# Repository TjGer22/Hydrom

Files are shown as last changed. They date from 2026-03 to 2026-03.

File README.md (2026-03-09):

# Hydrom Firmware

This directory contains the ESP32 firmware for the Hydrom smart hydrometer, built with [PlatformIO](https://platformio.org/) on the Arduino framework.

## Target Hardware

**Heltec WiFi LoRa 32 V2** — ESP32 with integrated OLED and LoRa (only the ESP32 core is used; LoRa is not used in this project).

## Directory Structure

```
firmware/
├── src/              # main.cpp — application entry point
├── lib/              # Project-specific libraries
│   ├── ArduAutoUpdater/   # OTA firmware update
│   ├── BTManager/         # Bluetooth LE (BLE iBeacon)
│   ├── Calibrator/        # Gravity calibration logic
│   ├── DeviceManager/     # Device lifecycle management
│   ├── FileManager/       # SPIFFS configuration storage
│   ├── FindCurve/         # Polynomial curve fitting
│   ├── I2Cdevlib-Core/    # I2C abstraction (vendored)
│   ├── I2Cdevlib-MPU6050/ # MPU6050 IMU driver (vendored)
│   ├── NetworkManager/    # Wi-Fi (AP + client mode)
│   ├── SensorManager/     # IMU + DS18B20 sensor handling
│   ├── ServiceManager/    # Cloud service integrations
│   ├── Utils/             # Shared utilities
│   └── WebManager/        # Embedded Web UI
├── data/             # SPIFFS assets (logo, font, favicon)
├── Flasher/          # Helper scripts for manual flashing
├── platformio.ini    # Build configuration
└── partitions_custom8MB.csv  # Custom 8 MB partition table
```

## Installing the Firmware (no development tools required)

The installer scripts download the latest release from GitHub and flash it
to your Hydrom automatically. You only need an internet connection and a USB
cable that supports data transfer.

### Windows

Open **PowerShell** (search for it in the Start menu) and paste:

```powershell
powershell -ExecutionPolicy Bypass -Command "irm https://raw.githubusercontent.com/TjGer22/Hydrom/main/firmware/Flasher/install.ps1 | iex"
```

The script will:

1. Install Python 3 if it is not already present (via winget or direct download)
2. Install esptool via pip
3. Detect the COM port of your Hydrom automatically
4. Download the latest firmware files from the GitHub Releases page
5. Flash all five binary files in the correct order

> **Driver note** — if no COM port is detected, install the CP2102 driver first:
> https://www.silabs.com/developers/usb-to-uart-bridge-vcp-drivers

---

### macOS

Open **Terminal** and paste:

```bash
curl -fsSL https://raw.githubusercontent.com/TjGer22/Hydrom/main/firmware/Flasher/install.sh | bash
```

---

### Linux

```bash
curl -fsSL https://raw.githubusercontent.com/TjGer22/Hydrom/main/firmware/Flasher/install.sh | bash
```

> **Permission note** — if the flash fails with a permission error, add your user
> to the `dialout` group, then log out and back in:
> ```bash
> sudo usermod -aG dialout $USER
> ```

---

### Overriding port or baud rate

If the installer cannot find the device automatically, you can pass the port
and baud rate as environment variables before the command:

**macOS / Linux:**
```bash
HYDROM_PORT=/dev/ttyUSB0 HYDROM_BAUD=115200 \
  curl -fsSL https://raw.githubusercontent.com/TjGer22/Hydrom/main/firmware/Flasher/install.sh | bash
```

**Windows (PowerShell):**
```powershell
$env:HYDROM_PORT="COM3"; $env:HYDROM_BAUD="115200"
powershell -ExecutionPolicy Bypass -Command "irm https://raw.githubusercontent.com/TjGer22/Hydrom/main/firmware/Flasher/install.ps1 | iex"
```

---

### What happens during flashing

The installer writes five binary files to specific addresses in the ESP32 flash:

| File | Address | Purpose |
|---|---|---|
| `bootloader_dio_40m.bin` | `0x1000` | ESP32 first-stage bootloader |
| `partitions.bin` | `0x8000` | Partition table (8 MB layout) |
| `boot_app0.bin` | `0xe000` | OTA selection bootloader |
| `firmware.bin` | `0x10000` | Application firmware |
| `spiffs.bin` | `0x5B0000` | Filesystem (Web UI assets) |

When prompted, hold the **BOOT** button on the Hydrom and release it once
you see `Connecting...` in the output.

---

## Building from Source (PlatformIO)

```bash
# Build firmware + SPIFFS image
pio run --environment local --target buildfs
pio run --environment local

# Flash to connected device
pio run --environment local --target upload
pio run --environment local --target uploadfs

# Open serial monitor
pio device monitor
```

## Building

```bash
# Build firmware + SPIFFS image
pio run --environment local --target buildfs
pio run --environment local

# Flash to connected device
pio run --environment local --target upload
pio run --environment local --target uploadfs

# Open serial monitor
pio device monitor
```

## Credentials

Copy `lib/FileManager/Credentials.txt.example` to `lib/FileManager/Credentials.txt` and fill in your own values.
The `Credentials.txt` file is listed in `.gitignore` and will **never** be committed.

## License

GPL v3 — see [../LICENSE](../LICENSE)

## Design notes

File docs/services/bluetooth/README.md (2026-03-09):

---
description: >-
  The Hydrom supports iBeacon technology and enables Bluetooth Low Energy data
  transmission to smartphones and tablets in the surrounding area.
---

# Change Bluetooth Settings

!!! danger
    It is not possible to connect to the Hydrom via Bluetooth. \
    To receive the Bluetooth signals (iBeacon), please use the competitor's Tilt2app:\
    [https://tilthydrometer.com/pages/app](https://tilthydrometer.com/pages/app)

    If you have an iPhone, there is a BETA test currently running:

    [https://testflight.apple.com/join/UNli2kml](https://testflight.apple.com/join/UNli2kml)

!!! tip
    **Precondition:**

    To make this setting you must have access to the user interface. If this is not the case, see here how to do it:[access-to-the-user-interface.md](../access-to-the-user-interface.md)

## Step 1: Open the Menue

To access the menu bar you have to click on the three lines in the upper left corner. (See arrow)\
Then the menu bar will open.

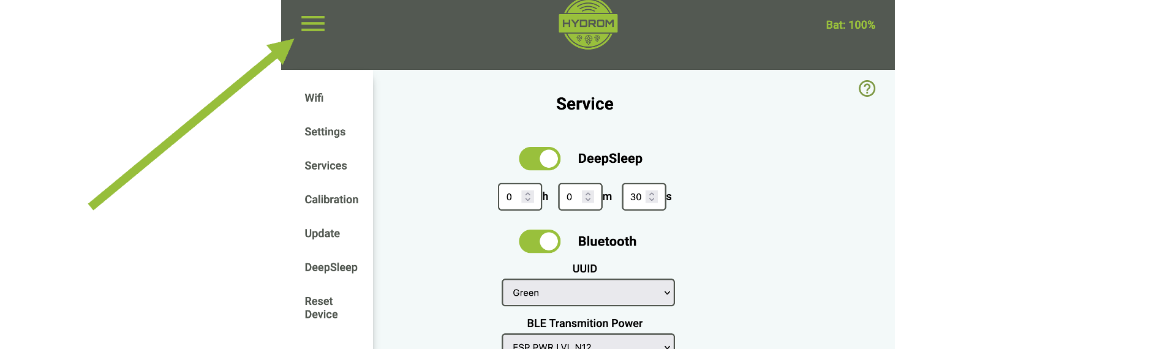
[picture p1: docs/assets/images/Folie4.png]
<figure><figcaption></figcaption></figure>

## Select "Service"

The "Services" page is a resource that allows users to select and configure various interfaces and cloud services for use with their system. On this page, users can choose from three different interfaces - HTTP, MQTT, and TCP - and several cloud services, and then activate and parameterize these options to suit their needs. This page is a useful tool for those who want to connect their system to the cloud or other external services and customize the way in which data is transmitted and received. With the options available on the "Services" page, users can tailor their system to meet their specific requirements and ensure that it is able to communicate effectively with other devices and systems.

## Step 3: Enable Bluetooth

The Hydrom will now send the following measured values via bluetooth after a restart by DeepSleep. For this, DeepSleep must also be activated as shown in the picture below.

!!! warning
    The "test message" option is not available for Bluetooth. So you have to wait until the Hydrom wakes up from a deep sleep. Hier findest du die Anleitu

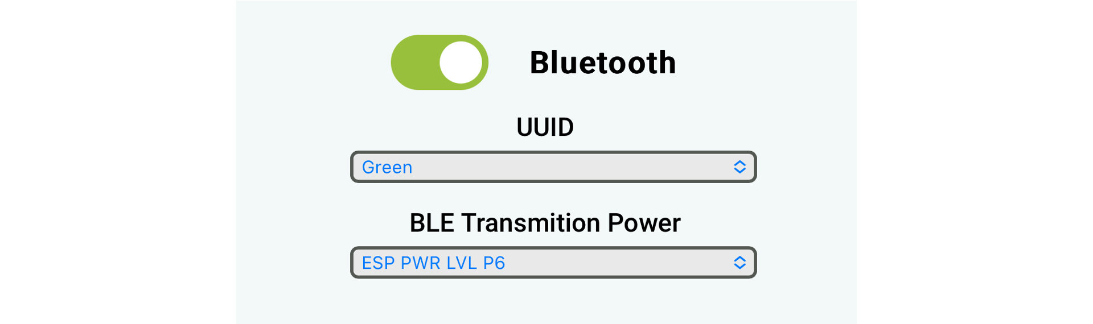
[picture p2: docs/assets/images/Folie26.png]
Enabled Bluetooth


!!! warning
    The "test message" option is not available for Bluetooth. So you have to wait until the Hydrom wakes up from a deep sleep.

## Choose UUID

Up to 8 Hydrom can be connected in parallel via Bluetooth. The different devices are then assigned different colors.

## Choose the transmission power

In the Hydrom, the power with which Bluetooth is transmitted can be set here. The range increases with higher transmission power. But beware, the battery life will also decrease with higher transmission power.

The powers with ascending transmission power:

*   ESP\_PWR\_LVL\_N14

    Corresponding to -14dbm
*   ESP\_PWR\_LVL\_N11

    Corresponding to -11dbm
*   ESP\_PWR\_LVL\_N8

    Corresponding to -8dbm
*   ESP\_PWR\_LVL\_N5

    Corresponding to -5dbm
*   ESP\_PWR\_LVL\_N2

    Corresponding to -2dbm
*   ESP\_PWR\_LVL\_P1

    Corresponding to 1dbm
*   ESP\_PWR\_LVL\_P4

    Corresponding to 4dbm
*   ESP\_PWR\_LVL\_P7

    Corresponding to 7dbm

### Save Settings

Saving the data is important because it is the only way to connect to the service after waking up from DeepSleep.

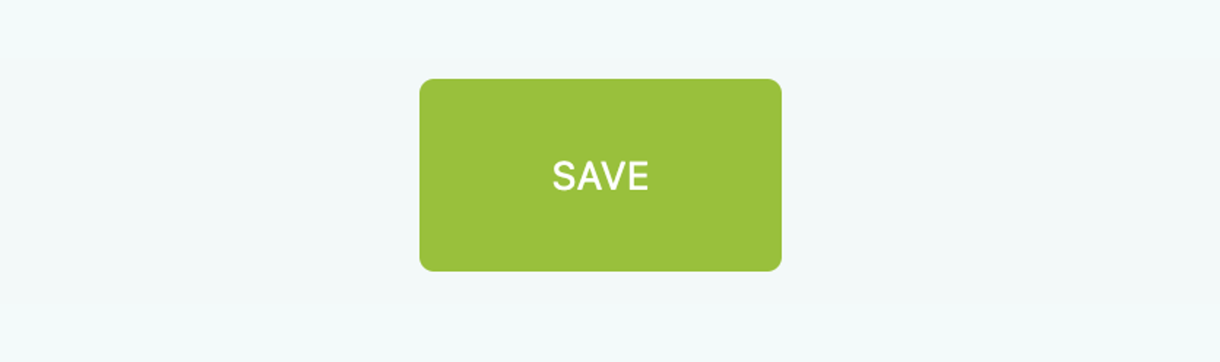
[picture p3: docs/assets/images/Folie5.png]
Pressing the "save" button saves the settings.


You can check whether the saving was successful by looking at the settings file at http://hydrom001/settings.json/. to check if the save was successful. This file is the permanent memory of the Hydrom.

A second way to check the saving is to reload the page (all browsers offer this). If the properties are then reloaded, the hydrom has accepted them, otherwise the old settings are reloaded.

### activate DeepSleep

Activating DeepSleep is mandatory for the hydrom to be able to send data. If DeepSleep is activated, the hydrom wakes up after the set time and sends the data to the set service. Afterwards, the hydrom goes back to sleep and waits for the new service.

[enable-deepsleep.md](../../configuration/enable-deepsleep.md)

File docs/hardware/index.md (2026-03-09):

---
description: >
  Overview of the Hydrom hardware design, KiCad source files and PCB specifications.
---

# Hardware Overview

The Hydrom PCB is designed with [KiCad](https://www.kicad.org/) (version 6+). All design files are open source under the **CERN Open Hardware Licence v2 – Strongly Reciprocal (CERN-OHL-S v2)**.

## Board Images

| Top side | Bottom side |
|---|---|
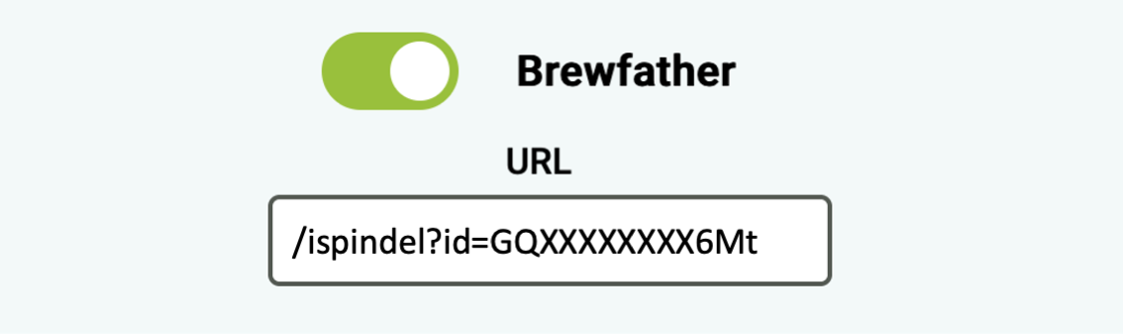
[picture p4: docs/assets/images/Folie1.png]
PCB Top
|  | PCB Bottom |

## Main Components

| Component | Function |
|---|---|
| ESP32 (Heltec WiFi LoRa 32 V2) | Main microcontroller — Wi-Fi, BLE, processing |
| MPU6050 | 6-axis IMU — measures tilt angle for density calculation |
| DS18B20 | 1-Wire temperature sensor |
| RT9080-33GJ5 | 3.3 V LDO voltage regulator |
| LiPo battery | Power supply |
| USB-C connector | Charging |

## Design Files

All KiCad source files are in [`hardware/pcb/`](https://github.com/TjGer22/Hydrom/tree/main/hardware/pcb). Open `hydrom_V1.0-2.kicad_pro` in KiCad to get started.

## Production Files

Ready-to-order files for PCB fabrication and assembly are in [`hardware/production/`](https://github.com/TjGer22/Hydrom/tree/main/hardware/production):

- **Gerbers** — standard Gerber 274-X format, tested with JLCPCB
- **BOM** — full bill of materials in XLSX format
- **Centroid** — pick-and-place files for top and bottom side

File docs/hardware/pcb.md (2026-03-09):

---
description: >
  PCB design details, fabrication notes and Gerber file locations for the Hydrom circuit board.
---

# PCB Design Files

The schematic and board layout are created with [KiCad](https://www.kicad.org/) 6+.

## Files

| File | Description |
|---|---|
| `hydrom_V1.0-2.kicad_pro` | KiCad project file — open this first |
| `hydrom_V1.0-2.kicad_sch` | Schematic |
| `hydrom_V1.0-2.kicad_pcb` | PCB layout |
| `hydrom_V1.0-2.xml` | Netlist |
| `PCB2.lib` | Custom schematic symbol library |
| `RT9080-33GJ5.lib` / `.dcm` | RT9080 LDO symbol and datasheet reference |
| `fp-lib-table` | Footprint library table |
| `sym-lib-table` | Symbol library table |

## Opening the Project

1. Install [KiCad](https://www.kicad.org/download/) 6 or later.
2. Clone the repository:
   ```bash
   git clone https://github.com/TjGer22/Hydrom.git
   ```
3. Open `hardware/pcb/hydrom_V1.0-2.kicad_pro` in KiCad.

## Board Renders

JLCPCB Top View
JLCPCB Bottom View

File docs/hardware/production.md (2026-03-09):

---
description: >
  Ready-to-order production files for PCB fabrication and SMD assembly of the Hydrom.
---

# Production Files

Ready-to-order production files are in [`hardware/production/`](https://github.com/TjGer22/Hydrom/tree/main/hardware/production).

## Gerbers

Standard Gerber 274-X files for PCB fabrication. Tested successfully with **JLCPCB**.

| File | Layer |
|---|---|
| `hydrom-F_Cu.gbr` | Front copper |
| `hydrom-B_Cu.gbr` | Back copper |
| `hydrom-F_Mask.gbr` | Front solder mask |
| `hydrom-B_Mask.gbr` | Back solder mask |
| `hydrom-F_Silkscreen.gbr` | Front silkscreen |
| `hydrom-B_Silkscreen.gbr` | Back silkscreen |
| `hydrom-F_Paste.gbr` | Front solder paste |
| `hydrom-B_Paste.gbr` | Back solder paste |
| `hydrom-Edge_Cuts.gbr` | Board outline |
| `hydrom-PTH.drl` | Plated through-holes |
| `hydrom-NPTH.drl` | Non-plated through-holes |

## Centroid (Pick-and-Place)

Pick-and-place files for SMT assembly:

- `hydrom-top-pos.xlsx` — top side component positions
- `hydrom-bottom-pos.xlsx` — bottom side component positions

## Ordering from JLCPCB

1. Download the `gerbers/` folder as a ZIP.
2. Upload to [jlcpcb.com](https://jlcpcb.com) → *Order Now*.
3. Enable *SMT Assembly* and upload the BOM and centroid files from `bom/` and `centroid/`.
4. Review the component placement preview and place your order.

!!! tip
    Select **HASL-Lead Free** or **ENIG** surface finish for best solderability.

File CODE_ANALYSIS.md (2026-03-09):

# Hydrom Firmware – Code Analysis & Cleanup Plan

> Generated: 2026-03-08
> Branch: `cleanup`
> Status: **In progress**

This document tracks every finding from the deep code review so work can be
resumed if the session is interrupted. Each item is marked ✅ when fixed.

---

## 1. Critical Typos in Identifiers

These affect compilation and must be changed everywhere consistently.

| # | File | Identifier | Issue | Fix | Status |
|---|---|---|---|-----|---|
| T1 | `lib/SensorManager/TemperaturCompensation.h/.cpp` | `TemperaturCompensation` | Missing 'e' → affects 17+ files | Rename class + files to `TemperatureCompensation` | ✅ |
| T2 | `lib/FileManager/HydromConfiguration.h:148` | `Enable_Temperaturcompensation` | Typo in member name | `Enable_TemperatureCompensation` | ✅ |
| T3 | `lib/FileManager/HydromConfiguration.h` | `Temperaturcompensation_Factor` | Typo in member | `TemperatureCompensation_Factor` | ✅ |
| T4 | `lib/SensorManager/SensorManager.h:47` | `readBatteryVolatage` | "Volatage" → "Voltage" | `readBatteryVoltage` | ✅ |
| T5 | `src/main.cpp:95` | comment `"3 seconds0"` | Stray zero | `"3 seconds"` | ✅ |

### Files affected by T1 (`TemperaturCompensation`):
- `lib/SensorManager/TemperaturCompensation.h` → rename file
- `lib/SensorManager/TemperaturCompensation.cpp` → rename file
- `lib/SensorManager/SensorManager.h` (include + member type)
- `lib/SensorManager/SensorManager.cpp` (usage)
- `lib/FileManager/HydromConfiguration.h` (member)
- `lib/FileManager/HydromConfiguration.cpp` (usage)
- `lib/WebManager/WebManager.cpp` (usage)
- `src/main.cpp` (include + usage)

---

## 2. Magic Numbers → Named Constants

All to be placed in `lib/FileManager/Globals.h`.

| # | File | Line | Value | Name | Status |
|---|---|---|---|---|---|
| M1 | `src/main.cpp` | 96 | `7` (button press seconds) | `BUTTON_PRESS_RESET_WIFI_SECONDS` | ✅ |
| M2 | `src/main.cpp` | 101 | `15` (factory reset seconds) | `BUTTON_PRESS_FACTORY_RESET_SECONDS` | ✅ |
| M3 | `src/main.cpp` | 170 | `3.0` (battery critical V) | `BATTERY_CRITICAL_VOLTAGE` | ✅ |
| M4 | `src/main.cpp` | 170 | `1.0` (battery min V) | `BATTERY_MIN_VOLTAGE` | ✅ |
| M5 | `src/main.cpp` | 173 | `10.0` (min startup temp °C) | `MIN_STARTUP_TEMPERATURE` | ✅ |
| M6 | `src/main.cpp` | 175 | `30.0` (max startup temp °C) | `MAX_STARTUP_TEMPERATURE` | ✅ |
| M7 | `lib/Calibration_MPU.cpp` | 36 | `3150` (µs delay) | `MPU_CALIBRATION_US_DELAY` | ✅ |
| M8 | `lib/Calibration_MPU.cpp` | 37 | `1000` (fast samples) | `MPU_CALIBRATION_FAST_SAMPLES` | ✅ |
| M9 | `lib/Calibration_MPU.cpp` | 38 | `10000` (slow samples) | `MPU_CALIBRATION_SLOW_SAMPLES` | ✅ |
| M10 | `lib/BTManager/BLESender.cpp` | 76 | `0x4C00` | `APPLE_IBEACON_MANUFACTURER_ID` | ✅ |

---

## 3. Duplicate Logic → Helper Functions

| # | Location | Pattern | Refactoring | Status |
|---|---|---|---|---|
| D1 | `main.cpp:209,281,334,446` | `DeepSleep.hours*3600 + DeepSleep.minutes*60 + DeepSleep.seconds` | Extract `calculateDeepSleepSeconds()` to Util | ✅ |
| D2 | `SensorManager.cpp:49-58` | Element-by-element array copy | Replace with `memcpy()` | ✅ |

---

## 4. const Correctness

| # | File | Function | Fix | Status |
|---|---|---|-----|---|
| C1 | `SensorManager.h` | `get_batteryVoltage()` and all getters | Add `const` | ✅ |
| C2 | `FindCurve.h:29` | `get_Curve_Quality()` | Add `const` | ✅ |
| C3 | `ServiceManager.h:33` | `Replace_Placeholder(char _url[265])` | `const String&` param | ✅ |
| C4 | `Calibration_MPU.h:22-26` | `LBRACKET`, `RBRACKET` etc. | `static constexpr` | ✅ |

---

## 5. Safety – StringCopy Buffer Overflow

| # | File | Lines | Issue | Fix | Status |
|---|---|---|---|-----|---|
| S1 | `Util.cpp:13-21` | `StringCopy` + `StringCopyConst` | `strlen(des)` on uninit buffer; no bounds check | Add null-guard + use `strlcpy()` | ✅ |
| S2 | `Util.cpp:27` | `IpToString()` static buffer | Not thread-safe | Add comment, keep for now (embedded single-task path) | ✅ |

---

## 6. Include Guards → `#pragma once`

All custom headers converted to `#pragma once` (PlatformIO/GCC supports it).

Files: `TemperaturCompensation.h`, `SensorManager.h`, `FindCurve.h`,
`Calibrator.h`, `BLESender.h`, `NetworkManager.h`, `DeviceManager.h`,
`WebManager.h`, `ServiceManager.h`, `HydromConfiguration.h`.

Status: ✅

---

## 7. Uninitialized Variables

| # | File | Line | Variable | Fix | Status |
|---|---|---|---|-----|---|
| U1 | `main.cpp:34` | `long last_Release;` | Initialize to `0` | ✅ |
| U2 | `SensorManager.h:88-100` | `float g_*` members | Default-initialize to `0.0f` | ✅ |

---

## 8. Dead Code Removed

| # | File | Lines | Description | Status |
|---|---|---|---|---|
| DC1 | `main.cpp:554-605` | ~50-line commented-out block | Remove | ✅ |
| DC2 | `WebManager.cpp:30` | `// boolean liveData = false;` | Remove comment | ✅ |

---

## 9. Out of Scope / Risk Too High (deferred)

These require deeper refactoring or embedded system expertise:

- **Race conditions** on global structs (FreeRTOS multi-core): Requires adding `SemaphoreHandle_t`; risks affecting timing.
- **setup() split**: 280-line function; refactoring into sub-functions is safe but very large change.
- **Hardcoded OTA password** in `NetworkManager.cpp:40`: Already in `Secrets.h`-like pattern; moving to runtime config requires flash storage changes.
- **TLS `setInsecure()`** in `ArduAutoUpdater`: Requires embedding CA cert bundle; separate task.
- **`Salzen()` rename**: Cryptographic/obfuscation function – renaming without understanding all callers is risky.
- **Service registry pattern** for `publish_Data_to_Services()`: Large architectural change.

---

## File Rename Map (T1)

| Old | New |
|-----|-----|
| `lib/SensorManager/TemperaturCompensation.h` | `lib/SensorManager/TemperatureCompensation.h` |
| `lib/SensorManager/TemperaturCompensation.cpp` | `lib/SensorManager/TemperatureCompensation.cpp` |

---

*Resume point: All items with ✅ are complete. Continue with any remaining items.*

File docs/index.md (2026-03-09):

---
description: >
  Introduction to the Hydrom open-source smart hydrometer — features, hardware, and licence overview.
---

# Hydrom — Open-Source Smart Hydrometer

**Hydrom** is a free-floating smart hydrometer that measures the density of your beer, wine, or cider in real time — no more opening the fermenter to take manual readings.

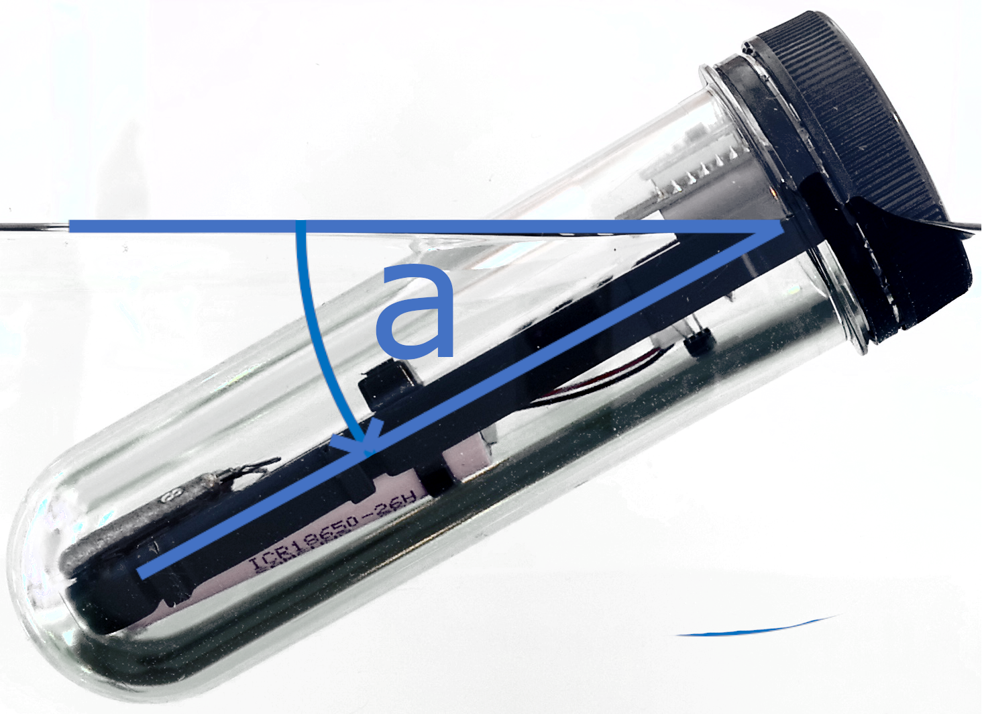
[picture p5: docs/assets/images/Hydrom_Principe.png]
Hydrom smart hydrometer floating in fermenter


---

<div class="feature-grid" markdown>

<div class="feature-card" markdown>
<h3>📡 Wi-Fi</h3>
<p>Connects to your home network and transmits measurements every few minutes — fully automatic.</p>
</div>

<div class="feature-card" markdown>
<h3>🔵 Bluetooth LE</h3>
<p>Broadcasts as an iBeacon — pick up readings on your smartphone without an internet connection.</p>
</div>

<div class="feature-card" markdown>
<h3>☁️ Cloud Services</h3>
<p>Direct integration with Brewfather, Brewer's Friend, Brewblox, Grainfather, MQTT, Google Sheets, and more.</p>
</div>

<div class="feature-card" markdown>
<h3>🔋 Deep Sleep</h3>
<p>Ultra-low power consumption. One charge lasts through an entire fermentation.</p>
</div>

<div class="feature-card" markdown>
<h3>🔧 OTA Updates</h3>
<p>Update firmware directly from the built-in web interface — no USB cable needed.</p>
</div>

<div class="feature-card" markdown>
<h3>📖 Open Source</h3>
<p>Firmware, hardware, and documentation are fully open. Build your own or contribute.</p>
</div>

</div>

---

## Quick Start

New to Hydrom? These are the steps to get from unboxing to active monitoring:

| Step | Action |
|---|---|
| 1 | [Read Safety Warnings](getting-started/warnings-read-before-use.md) |
| 2 | [Disinfect the Hydrom](getting-started/disinfect-before-use.md) |
| 3 | [Charge via USB-C](services/charging-the-hydrom.md) |
| 4 | [Switch on](services/turn-on-the-hydrom.md) and [enter Configuration Mode](services/wakeup-the-hydrom.md) |
| 5 | [Connect to your Wi-Fi](services/wifi-setup.md) |
| 6 | [Open the Web UI](services/access-to-the-user-interface.md) |
| 7 | [Calibrate](calibration/check-calibration.md) for accurate readings |
| 8 | [Connect a service](services/connect_to_brewfather.md) — e.g. Brewfather |

→ [Full Getting Started guide](getting-started/README.md)

---

## How It Works

The Hydrom floats in your liquid at an angle determined by the liquid's density. An onboard IMU (MPU-6050) measures this angle continuously, a DS18B20 temperature sensor compensates for temperature effects, and the firmware converts the result to specific gravity or °Plato. Data is transmitted via Wi-Fi every few minutes — or broadcast continuously as a Bluetooth Low Energy beacon.

---

## Licenses

| Component | License |
|---|---|
| Firmware / Software | [GPL v3](https://github.com/TjGer22/Hydrom/blob/main/LICENSE) |
| PCB / Hardware | [CERN-OHL-S v2](https://github.com/TjGer22/Hydrom/blob/main/hardware/LICENSE-HARDWARE) |
| Documentation | [CC BY 4.0](https://github.com/TjGer22/Hydrom/blob/main/docs/LICENSE-DOCS) |

Contributions are welcome — see the [Contributing Guide](contributing.md).

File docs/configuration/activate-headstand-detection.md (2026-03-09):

---
description: >
  How to enable headstand detection so the Hydrom pauses measurements when inverted.
---

# Activate Headstand Detection

## What is Headstand Detection?

During fermentation, your Hydrom needs to float normally in your fermenter. However, sometimes the Hydrom may accidentally end up upside down—for example, during cleaning, when removing it from the fermenter, or if something bumps it.

**Headstand detection** automatically recognizes when the Hydrom is inverted and stops transmitting false readings. This protects your fermentation data by preventing inaccurate measurements and saves battery power by not sending bad data.

!!! info
    Detection threshold is approximately 90 degrees. When inverted, the Hydrom will suspend measurement and transmission. It automatically resumes normal operation on the next wake cycle when placed right-side up.

## How to Enable Headstand Detection

### Step 1: Open the Menu

Open the Hydrom web interface in your browser. Look for the **menu icon** (three horizontal lines) in the top-left corner of the screen.

### Step 2: Navigate to Settings

Tap or click on **Settings** from the menu options.

### Step 3: Enable Headstand Detection

In the Settings page, locate the **Headstand Detection** toggle switch. Tap or click to enable it.

### Step 4: Save Your Settings

Click the **Save** button to apply the setting. You'll see a confirmation message.

## How It Works

When **Headstand Detection** is enabled:

- **Monitors orientation** of the Hydrom continuously
- **Detects inversion** when tilted beyond approximately 90 degrees
- **Stops transmissions** if upside down to prevent false readings
- **Prevents battery drain** from transmitting bad data
- **Auto-recovers** when the Hydrom returns to normal floating position

## Benefits

- **Protects data integrity** during handling and cleaning
- **Saves battery** by not transmitting erroneous measurements
- **Automatic recovery** — no manual intervention needed
- **Works silently** in the background

## When to Use This Feature

Enable Headstand Detection if:

- Your Hydrom occasionally gets bumped or moved around
- You clean your fermenter while the Hydrom is present
- You want the maximum battery life
- You're concerned about accidental inversions affecting your data

## Tips

- **Always leave enabled** for normal operation
- **No impact on accuracy** when the Hydrom is floating normally
- **Complements temperature compensation** for the best measurement experience
- **Check orientation occasionally** to ensure normal floating position

---

**Related guides:**
- [Temperature Compensation →](setting-up-the-temperature-compensation.md)
- [Return to Settings →](changing-the-hydrom-name.md)

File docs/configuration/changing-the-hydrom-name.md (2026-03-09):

---
description: >
  How to change the device name of your Hydrom in the web interface.
---

# Changing the Hydrom name

!!! danger
    ATTENTION! If you have entered incorrect Name for the Hydrom, you will not be able to connect to the Hydrom via existing Network. You will then need to use the Configuration-Wifi.

    If the setting is incorrect, you can reset the Hydrom as described here:

    [#reset-by-the-button](factory-reset.md#reset-by-the-button)

!!! info
    Changing the Hydrom name has the following effect:

    1. The user interface is not accessed via [http://hydrom001/](http://hydrom001) as described in the chapter [Access to the User Interface](../services/access-to-the-user-interface.md#connect-to-the-hydrom-via-the-hydroms-configuration-wifi), but now via http://\<own\_choosen\_name>/.
    2.  Some of the services described in the chapter "Connect Services" now send to a different address.

        However, this is mentioned separately in the respective instruction article.

!!! tip
    To make this setting you must have access to the user interface. If this is not the case, see here how to do it:

    [access-to-the-user-interface.md](../services/access-to-the-user-interface.md)

## Step 1: Open the Menue

To access the menu bar you have to click on the three lines in the upper left corner. (See arrow)\
Then the menu bar will open.

access the menu bar by clicking the three lines in the upper left corner

## Step 2: Select "Settings"

On this page, you can adjust various settings to personalize your experience with the device. Options you can customize include the interval at which the device collects and sends data, the units displayed on the main page, and the overhead detection feature. You can also enable temperature compensation to ensure accurate measurements. Take some time to explore the various settings available and make the necessary adjustments for your needs.

## Step 3: Change device name

To change the device name, enter the new name under the "Devicename" lettering.\
By default, the device name is "Hydrom001".

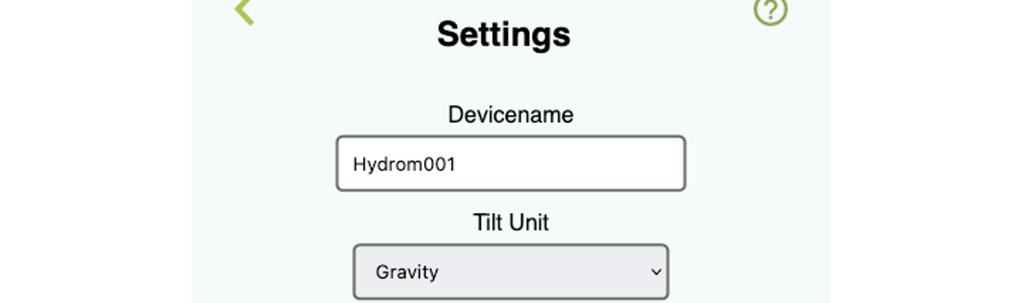
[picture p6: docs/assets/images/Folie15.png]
Changing the device name of the hydrometer


### Save Settings

Saving the data is important because it is the only way to connect to the service after waking up from DeepSleep.

Pressing the "save" button saves the settings.

You can check whether the saving was successful by looking at the settings file at http://hydrom001/settings.json/. to check if the save was successful. This file is the permanent memory of the Hydrom.

A second way to check the saving is to reload the page (all browsers offer this). If the properties are then reloaded, the hydrom has accepted them, otherwise the old settings are reloaded.

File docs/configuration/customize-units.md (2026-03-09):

---
description: >-
  The Hydrom supports several units for the tilt and the temperature. Here is
  explained how to change the unit.
---

# Customize units

!!! tip
    **Precondiion:**\
    To make this setting you must have access to the user interface. If this is not the case, see here how to do it:[access-to-the-user-interface.md](../services/access-to-the-user-interface.md)

## Step 1: Open the Menue

To access the menu bar you have to click on the three lines in the upper left corner. (See arrow)\
Then the menu bar will open.

access the menu bar by clicking the three lines in the upper left corner

## Step 2: Select "Settings"

On this page, you can adjust various settings to personalize your experience with the device. Options you can customize include the interval at which the device collects and sends data, the units displayed on the main page, and the overhead detection feature. You can also enable temperature compensation to ensure accurate measurements. Take some time to explore the various settings available and make the necessary adjustments for your needs.

## Step 3: Change Units

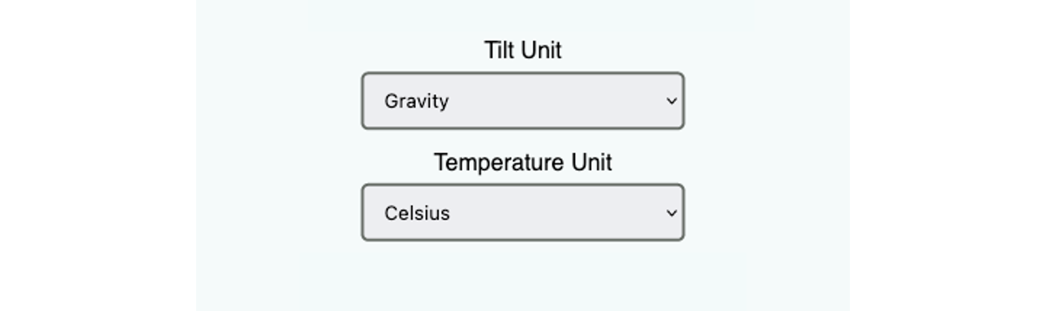
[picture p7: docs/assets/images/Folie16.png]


### Tilt

* **Plato** The unit Plato (°P) is a unit of measure used to quantify the concentration of sugars in a solution. It is commonly used in the brewing industry to describe the concentration of wort, which is the liquid that is extracted from the mashing process during the production of beer. One degree Plato is equal to one gram of sucrose per 100 grams of solution. The Plato scale is widely used because it is more accurate than other methods of measuring the concentration of sugars, such as the Brix scale.
* **Specific Gravity** Specific gravity is a unit of measure used to compare the density of a substance to the density of a reference substance, typically water. It is commonly used in the brewing industry to measure the concentration of sugars in a solution, such as wort or beer. Specific gravity is expressed as a ratio, with the density of the substance being measured being the numerator and the density of the reference substance being the denominator. For example, if the specific gravity of a substance is 1.050, it means that it is 1.050 times denser than water, which has a specific gravity of 1.000. Specific gravity is an important measure for brewers because it allows them to determine the concentration of sugars and other dissolved solids in their wort or beer, which can affect the final alcohol content and flavor of the finished product.
* **Degree** The raw angle of the Hydrom to the horizontal is indicated in degrees. If the hydrometer is horizontal, "0°" is displayed. If the hydrometer is in the vertical plane, "90°" is displayed.

### Temperature

* **Celsius** The unit Celsius (°C) is the international standard temperature scale used for measuring temperatures, with zero set at 0 °C and the boiling point of water set at 100 °C.
* **Fahrenheit** Fahrenheit (°F) is a temperature scale used in the United States and some other countries, with the freezing point of water set at 32 °F and the boiling point at 212 °F.
* **Kelvin**. The unit Kelvin (K) is a temperature scale used in science and industrial applications and on which the absolute temperature scale is based. On the Kelvin scale, absolute zero is set at 0 K, which corresponds to the theoretical state of complete immobility of atoms and molecules. The Kelvin scale is often used in physics and chemistry because it is independent of the type of heat transfer and has no negative values.

!!! info
    The set units do not affect the services.

    This means that the data sent will always be consistent, no matter what unit is set.

### Save Settings

Saving the data is important because it is the only way to connect to the service after waking up from DeepSleep.

Pressing the "save" button saves the settings.

You can check whether the saving was successful by looking at the settings file at http://hydrom001/settings.json/. to check if the save was successful. This file is the permanent memory of the Hydrom.

A second way to check the saving is to reload the page (all browsers offer this). If the properties are then reloaded, the hydrom has accepted them, otherwise the old settings are reloaded.

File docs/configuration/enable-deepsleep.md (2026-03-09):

---
description: >-
  If you put your ESP32 in deep sleep mode, it will reduce the power consumption
  and your batteries will last longer.
---

# Adjust Interval

!!! tip
    **Precondition:**\
    To make this setting you must have access to the user interface. If this is not the case, see here how to do it:

    [access-to-the-user-interface.md](../services/access-to-the-user-interface.md)

## Step 1: Open the Menue

To access the menu bar you have to click on the three lines in the upper left corner. (See arrow)\
Then the menu bar will open.

access the menu bar by clicking the three lines in the upper left corner

## Step 2: Select "Settings"

On this page, you can adjust various settings to personalize your experience with the device. Options you can customize include the interval at which the device collects and sends data, the units displayed on the main page, and the overhead detection feature. You can also enable temperature compensation to ensure accurate measurements. Take some time to explore the various settings available and make the necessary adjustments for your needs. or "Services"

## Step 3: Adjust Interval

Select the time the hydrom should sleep.



If you want to put the Hydrom to sleep immediately, you can select "DeepSleep" in the navigation bar.
Even if you switch the Hydrom off and on again via the switch, the Hydrom will be put into deep sleep after the first transmission of the measured values.

!!! info
    **Sleep time calculation**

    Currently the Hydrom needs 23sec. to start, set up the network, send out the readings.

    This means that for a constant transmission of data every 15min, you need to set a sleep time of 14min. 27sec.

### Save Settings

Saving the data is important because it is the only way to connect to the service after waking up from DeepSleep.

Pressing the "save" button saves the settings.

You can check whether the saving was successful by looking at the settings file at http://hydrom001/settings.json/. to check if the save was successful. This file is the permanent memory of the Hydrom.

A second way to check the saving is to reload the page (all browsers offer this). If the properties are then reloaded, the hydrom has accepted them, otherwise the old settings are reloaded.

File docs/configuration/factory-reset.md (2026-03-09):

---
description: >-
  The Hydrom can be reset with the reset button
---

# Factory Reset

## Reset by the button

The Hydrom can be reset by pressing the reset button for 10 seconds.&#x20;

To access this button, the lid must be unscrewed.

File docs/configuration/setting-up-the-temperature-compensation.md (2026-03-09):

---
description: >
  How to configure the temperature compensation factor to correct angle readings at different temperatures.
---

# Setting Up Temperature Compensation

## What is Temperature Compensation?

The Hydrom hydrometer is calibrated at 20°C (68°F) during manufacturing. However, during fermentation, your beer or wine may be at a different temperature—warmer or cooler. Since the density of liquids changes with temperature, this difference can introduce small measurement errors.

**Temperature compensation automatically corrects these errors** by using the Hydrom's built-in temperature sensor to adjust readings based on the actual liquid temperature. This ensures you get accurate gravity measurements regardless of fermentation conditions.

!!! note
    The sensor must be fully submerged for accurate temperature readings. Make sure the Hydrom floats freely in your fermenter.

## How to Enable Temperature Compensation

### Step 1: Open the Menu

Open the Hydrom web interface in your browser. Look for the **menu icon** (three horizontal lines) in the top-left corner of the screen.

Open the menu

### Step 2: Navigate to Settings

Tap or click on **Settings** from the menu options that appear.

### Step 3: Enable Temperature Compensation

In the Settings page, locate the **Temperature Compensation** toggle switch. Tap or click to enable it.

Save your settings

### Step 4: Save Your Changes

Click the **Save** button to apply the temperature compensation setting. You'll see a confirmation message indicating the setting has been saved.

## What to Expect

Once enabled, the Hydrom will:

- **Monitor liquid temperature** continuously using its built-in sensor
- **Automatically adjust** gravity readings to reflect 20°C equivalent values
- **Display both** the actual reading and temperature in the web interface
- **Improve accuracy** especially during temperature fluctuations

## Tips

- **Enable this feature** for the most accurate fermentation tracking
- **Works best** when the Hydrom is floating freely in the fermenter
- **No additional calibration** is needed after enabling temperature compensation
- **Check occasionally** that the Hydrom remains fully submerged as fermentation progresses

Temperature compensation takes the guesswork out of accounting for temperature variations and helps you make better decisions about your fermentation.

---

**Next steps:**
- [Activate Headstand Detection →](activate-headstand-detection.md)
- [Return to Settings →](changing-the-hydrom-name.md)

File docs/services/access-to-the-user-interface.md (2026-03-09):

---
description: >
  How to access the Hydrom configuration web interface from a phone or computer.
---

# Access to the user interface

!!! tip
    **Precondition:**

    1. The Hydrom must be powered on\
       How to switch on the Hydrom can be found here:\
       [turn-on-the-hydrom.md](turn-on-the-hydrom.md)
    2.  The Hydrom must be in configuration mode\
        In normal operation, no user interface is loaded in order not to waste the battery charge. Therefore, the Hydrom must be put into configuration mode.

        You can detect if the Hydrom is in Deepsleep when the green LED is on as described here: [Status LED](../getting-started/indicator-leds.md#status-led-of-the-hydrom-logic)

        If the Hydrom is in Deepsleep, it can be woken up according to the instructions on this page:\
        [wakeup-the-hydrom.md](wakeup-the-hydrom.md)

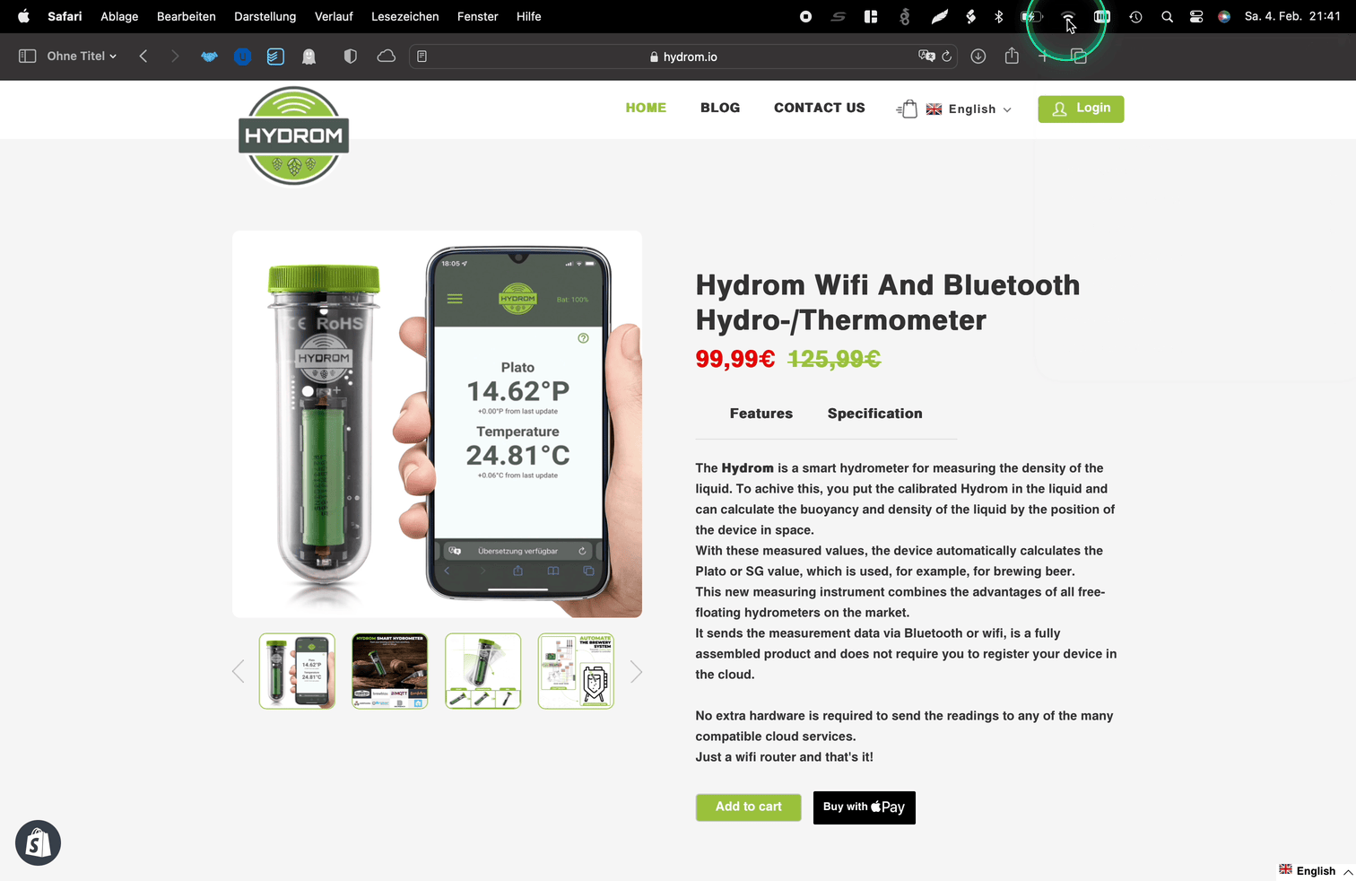
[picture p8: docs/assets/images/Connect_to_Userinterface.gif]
<figure><figcaption></figcaption></figure>

## Connect to the Hydrom via the Hydrom's configuration wifi.

### Step 1: Connect to the Hydrom's WLAN

1. turn on your smartphone, tablet or computer.
2. in your device's wifi settings, search for a wifi named "hydrom\_XXXXX". Select this Wi-Fi and connect to it.

### Step 2: Open the Hydrom user interface in the browser

1. open the internet browser on your device (e.g. Google Chrome, Mozilla Firefox or Safari). Enter the following address in the address bar of the browser: [http://192.168.2.1](http://192.168.2.1) and press Enter.

## Connect to the Hydrom via the existing WLAN (only if the Hydrom is already connected to the WLAN).

!!! info
    If the hydrom is already connected to your WLAN, it now has a different address. The old address "[http://192.168.2.1](http://192.168.2.1)" does not work anymore.

    If you don't know the new address, connect to the Hydrom WLAN as described in **step 1**.\
    Then go to the network settings in the Hydrom user interface. If the connection is successful, you will see the new address in a green box at the top of the page.

1. open your internet browser again. 2.
2. type the new address (e.g. "http://\<new IP>") in the address bar and press enter.

Now you should be able to see and use the Hydrom user interface.

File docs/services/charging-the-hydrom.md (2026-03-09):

---
description: >
  How to charge the Hydrom battery and check the charging status via the indicator LEDs.
---

# Charging the Hydrom

The Hydrom can be charged with any commercially available USB-C charging cable.

Even the direction in which you insert the plug into the device does not matter. To charge, open the Hydrom by twisting off the lid.

The charging LED (described here: [Charging LED](../getting-started/indicator-leds.md#charging-led)) indicates the current charging status. If the LED is red, the Hydrom is being charged. When the LED is green, the charging process is complete.\\

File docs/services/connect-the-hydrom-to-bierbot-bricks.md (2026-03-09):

---
description: >-
  BierBot Bricks software is designed to support all steps of the brewing
  process from mashing, to fermentation, to lagering.
cover: ../assets/images/Folie74.png
coverY: 0
---

# Connect the Hydrom to BierBot Bricks

!!! tip
    **Prerequisite:**

    1. **Access to user interface**\
       To make this setting, you must have access to the user interface. If this is not the case, see here how to do it:[access-to-the-user-interface.md](access-to-the-user-interface.md)
    2. **BierBot Bricks account available**.\
       To use BierBot Bricks, you need an account. You can register here: [https://bierbot.com](https://bierbot.com)

## Prepare the service

### Create brick in the BierBot brewery

To do this navigate to the BierBot Bricks website and log in. Then click on the "Brewery" tab. Then click on the "Add Brick" button.

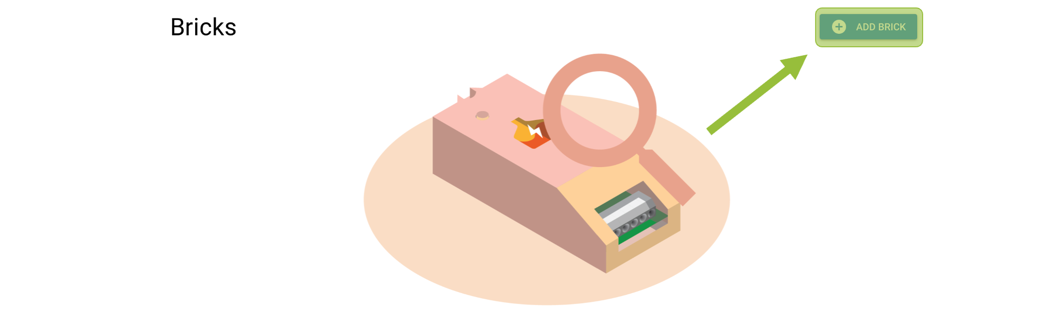
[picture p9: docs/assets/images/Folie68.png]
Add Brick


Choose HYDROM as type of brick you want to add. Then click on the "Add Brick" button.

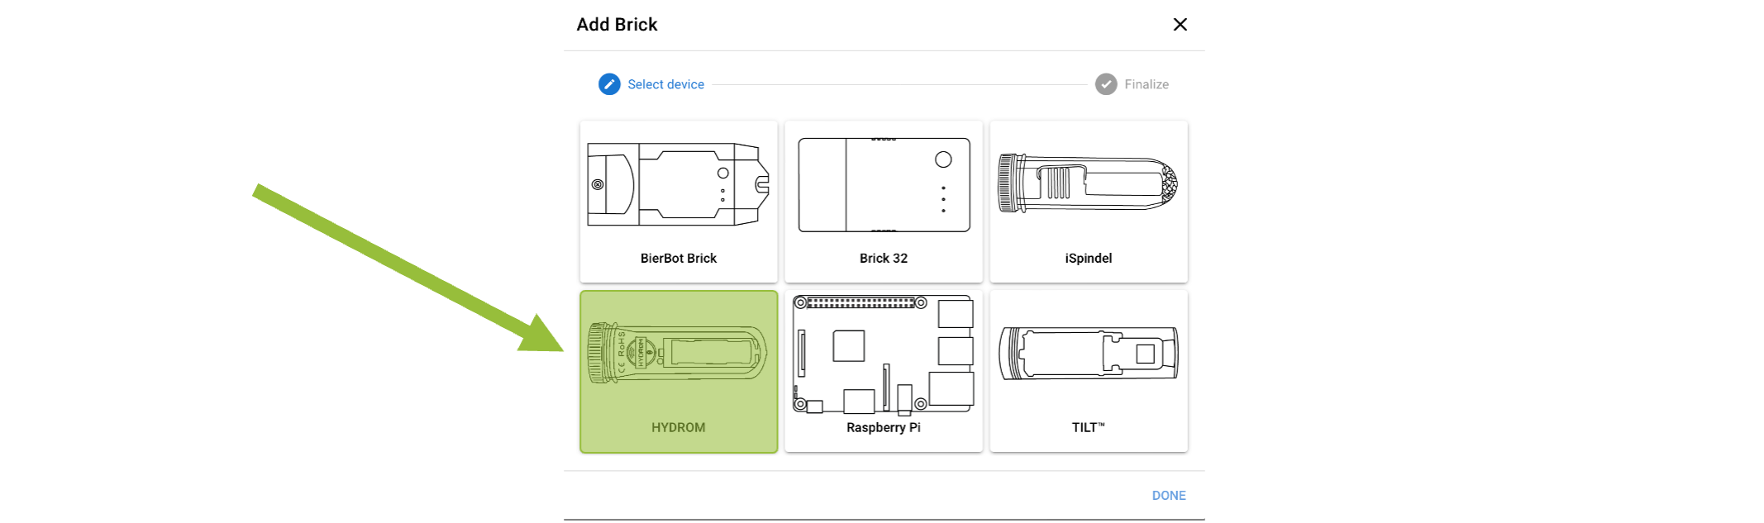
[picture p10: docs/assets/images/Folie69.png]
Add HYDROM Brick


### Copy the API token

After the brick has been added, you will be redirected to the brick settings. Here you can find the API token. Copy the API token and save it for later use.

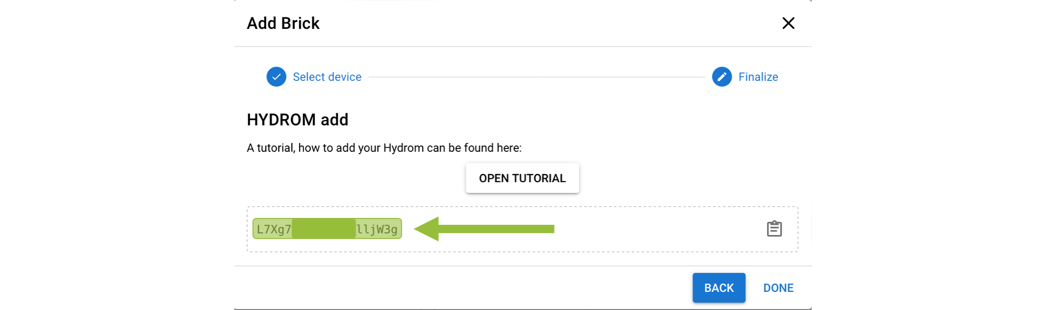
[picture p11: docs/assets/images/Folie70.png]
<figure><figcaption></figcaption></figure>

When the Hydrom sends measured values to the BierBot Bricks service for the first time, the new device is displayed in the brewery under "Bricks" with all measured values.\
The fastest way to get the device displayed is to set the interval in the Hydrom to 1 second.\
Then BierBot Bricks will automatically set the time to 15min.

### Activate the Device

If the device is displayed under the Bricks, it still needs to be activated.

### Set custom logging interval

The default logging interval is 15 minutes. If you want to change this interval, you can do so here. To do this, click on the "Settings" tab and then on the "Logging" tab.

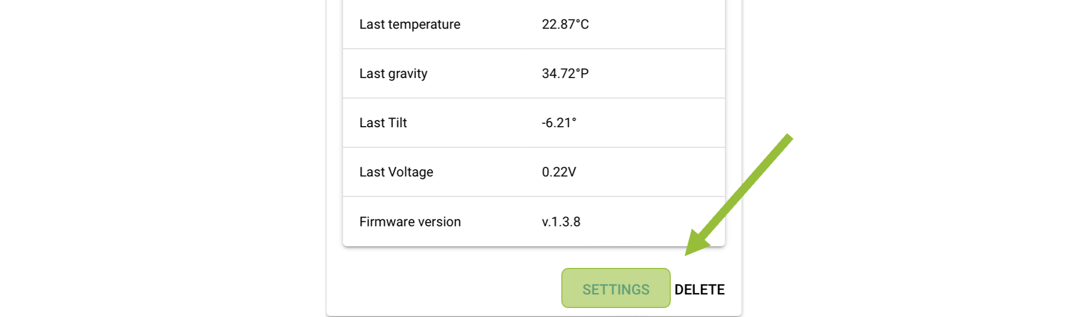
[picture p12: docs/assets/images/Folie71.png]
<figure><figcaption></figcaption></figure>

Activate "Set Custom Interval" (1). Then change the logging interval to the desired value (2) and click on the "Save" button (3).

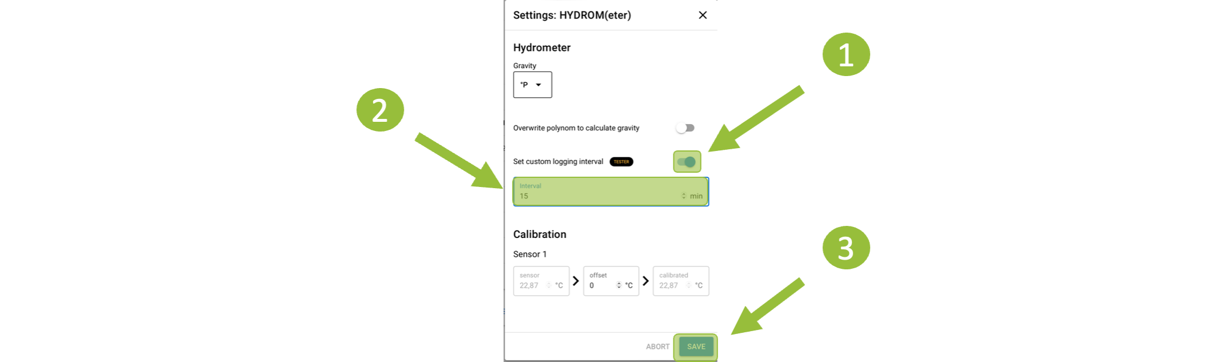
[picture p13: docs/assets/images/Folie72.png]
<figure><figcaption><p>Set custom logging interval</p></figcaption></figure>

## Insert BierBot Bricks settings in Hydrom

Now open the user interface of the Hydrom, in the best case the Hydrom is already in the network and can be easily accessed via Webpage.\
If there are questions about how to get to the user interface, the following page is recommended: [access-to-the-user-interface.md](access-to-the-user-interface.md)

Otherwise the Hydrom must still be started.

### Step 1: Open the Menue

To access the menu bar you have to click on the three lines in the upper left corner. (See arrow)\
Then the menu bar will open.

access the menu bar by clicking the three lines in the upper left corner

### Step 2: Select "Service"

The "Services" page is a resource that allows users to select and configure various interfaces and cloud services for use with their system. On this page, users can choose from three different interfaces - HTTP, MQTT, and TCP - and several cloud services, and then activate and parameterize these options to suit their needs. This page is a useful tool for those who want to connect their system to the cloud or other external services and customize the way in which data is transmitted and received. With the options available on the "Services" page, users can tailor their system to meet their specific requirements and ensure that it is able to communicate effectively with other devices and systems.

### Step 3: Activate BierBot Bricks and change the settings.

On the "Service" page, you need to activate the BierBot Bricks service. Copy the API token from the BierBot Bricks website and paste it into the "Token" field.

!!! info
    The token must be entered without any spaces. If there are spaces, the token will not be accepted.

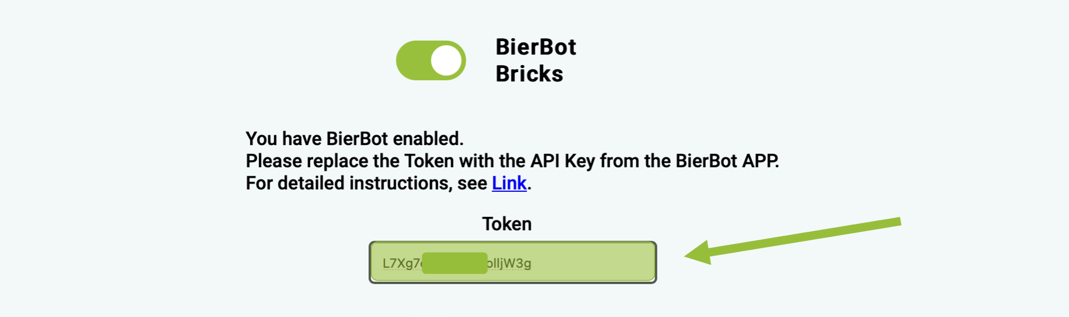
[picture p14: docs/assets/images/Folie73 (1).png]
The settings made here will be used in the Hydrom


The Deepsleep interval set here will be ignored, cause the Bierbot Bricks API will set the setted interval in the Bierbot Bricks brewery.\
The default value is 15 minutes.\
If you want this Interval to be different, you have to change it in the BierBot Bricks brewery (see above).

### additional settings

In order not to consume too much power, we would turn Bluetooth off when it is not needed. It was documented here:

[Enable Bluetooth on the Hydrom](bluetooth/README.md)

In order for the Hydrom to transmit the data reliably, a DeepSleep time must be set. This is documented on this page:

[enable-deepsleep.md](../configuration/enable-deepsleep.md)

### Save Settings

Saving the data is important because it is the only way to connect to the service after waking up from DeepSleep.

Pressing the "save" button saves the settings.

You can check whether the saving was successful by looking at the settings file at http://hydrom001/settings.json/. to check if the save was successful. This file is the permanent memory of the Hydrom.

A second way to check the saving is to reload the page (all modern browsers offer this Feature). If the properties are then reloaded, the hydrom has accepted them, otherwise the old settings are reloaded.

### activate DeepSleep

Activating DeepSleep is mandatory for the hydrom to be able to send data. If DeepSleep is activated, the hydrom wakes up after the set time and sends the data to the set service. Afterwards, the hydrom goes back to sleep and waits for the new service.

[enable-deepsleep.md](../configuration/enable-deepsleep.md)

!!! tip
    To ensure that the device sends measured values to the Service in the set interval as intended, the Hydrom must be put into deep sleep.

    There are two ways to put the Hydrom into deep sleep.

    Turning the _**power switch off and on**_ is the easiest way to put the Hydrom into deep sleep.

    The alternative way is to put it to sleep _**via the UI**_. To do this, open the navigation bar and go to the "DeepSleep" tab.

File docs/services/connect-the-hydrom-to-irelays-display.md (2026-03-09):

---
description: >-
  Nautilis, have an iRelays on the market that receives and displays the hydrom
  locally. Here is a description of how to make the connection.
---

# Connect the Hydrom to iRelays Display

!!! tip
    **Prerequisite**

    1. To make this setting, you must have access to the user interface. If you don't, see here how to do it:\
       [Access to the user Interface](access-to-the-user-interface.md)
    2. **iRelays available** To use iRelays, you need to buy one of this devices.

## Principle of the iRelay

The iRelay can be used locally or as a transmitter to the cloud. It acts as a repeater and reports the received measurement results to a cloud service. For information on how to create a cloud service in the relay, please refer to the instructions for the relay.

In this manual, you will learn how to configure the relay and the Hydrom so that the measurement values are sent to the relay and can then be displayed locally.

## Prepare the iRelay

If the iRelay is to be connected to the Internet or an existing network, the following steps must be done.

### Step 1: Supply the iRelay with voltage

The device has no battery, so you have to power it with a USB-C cable.

### Step 2: Connect to the WiFi of the iRelay

### Step 3: Connect the iRelay to the existing network

## Setting up the Hydrom

Now open the Hydrom's user interface.

### Step 1: Open menu bar

To access the menu bar, you need to click on the three lines in the upper left corner. (See arrow)\
Then the menu bar will open.

open the menu bar by clicking on the three lines in the upper left corner

### Step 2: Select "Service

On the "Services" page, you have the option to select and configure various interfaces and cloud services for use with its system. On this page, users can choose from three different interfaces - HTTP, MQTT, and TCP - and several cloud services, and then enable and parameterize these options to fit their needs. This page is a useful tool for those who want to connect their system to the cloud or other external services and customize the way data is transmitted and received. With the options available on the Services page, users can customize their system to meet their specific needs and ensure that it can communicate effectively with other devices and systems.

### Step 3: Enable "http" and change the settings.

On the "Service" page, the http-Server service must be activated.

<!-- Screenshot: Service page with HTTP Server activated -->

Content:

* **Server**\
  Set the server to "192.168.4.1".
* **Port**\
  Set the port to "80".
* **URL**\
  Set the server to "/gravity".

### Step 4: Change the name of the Hydrom

The iRelay needs a special name for the hydrom like this: "1-Hydrom\[SG]".\
You can find out how to change the name here:

[changing-the-hydrom-name.md](../configuration/changing-the-hydrom-name.md)

### Step 5: Connect the hydrom to the WiFi of the iRelay

In order for the hydrom to send the readings to the iRelay, the hydrom needs to be connected to the iRelay's WiFi.

* **SSID**\
  Set the SSID to "nautilis-ispindel".
* **Password**\
  Set the password to "1234567890".

You can find out how to change the Network Settings here:

[Wi-Fi Setup](wifi-setup.md)

### additional settings

To avoid using too much power, we would turn off Bluetooth when it is not needed. This was documented here:

[Enable Bluetooth on the Hydrom](bluetooth/README.md)

In order for the hydrom to transmit data reliably, a DeepSleep time must be set. This is documented on this page:

[enable-deepsleep.md](../configuration/enable-deepsleep.md)

### Save settings

Saving the data is important because it is the only way to connect to the service after waking up from DeepSleep.

Pressing the "SAVE" button saves the settings

You can check if the save was successful by looking at the settings file at http://hydrom001/settings.json/. This file is the persistent storage of the hydrom.

A second way to check the saving is to reload the page (all browsers offer this). If then the properties are reloaded, the hydrom has accepted them, otherwise the old settings are reloaded.

### Activate DeepSleep

Enabling DeepSleep is mandatory for the hydrom to send data. If DeepSleep is activated, the hydrom wakes up after the specified time and sends the data to the set service. After that, the hydrom goes back to sleep and waits for the new service.

[enable-deepsleep.md](../configuration/enable-deepsleep.md)

!!! tip
    In order for the device to send readings to the service at the set interval as intended, the Hydrom must be put into deep sleep.

    There are two ways to put the Hydrom into deep sleep.

    The easiest way to put the Hydrom into deep sleep is to _**turn the power switch**_ off and on.

    The other way is to put the device into deep sleep _**using the user interface**_. To do this, open the navigation bar and go to the "DeepSleep" tab.

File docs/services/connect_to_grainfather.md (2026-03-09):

---
description: >-
  The free brewing app has all the tools, calculators and beer recipes that
  empower you to create amazing beer at home.
cover: https://grainfather.com/wp-content/uploads/2021/06/GF-logo.svg
coverY: 0
---

# Connect the Hydrom to Grainfather

!!! tip
    **Prerequisite:**

    1. **Access to user interface**\
       To make this setting, you must have access to the user interface. If this is not the case, see here how to do it:[access-to-the-user-interface.md](access-to-the-user-interface.md)
    2. **Grainfather user account available**.\
       An account has been created with the cloud provider Grainfather.
    3. **Grainfather App was downloaded**.\
       https://grainfather.com/brewing-app/

## Preparing the service

In order to make the Hydrom known to the Grainfather application, the Hydrom must be created in the application.

### Step 1: Navigate to the equipment manager.

Select the icon at the bottom that looks like a boiler, then the equipment manager will open up

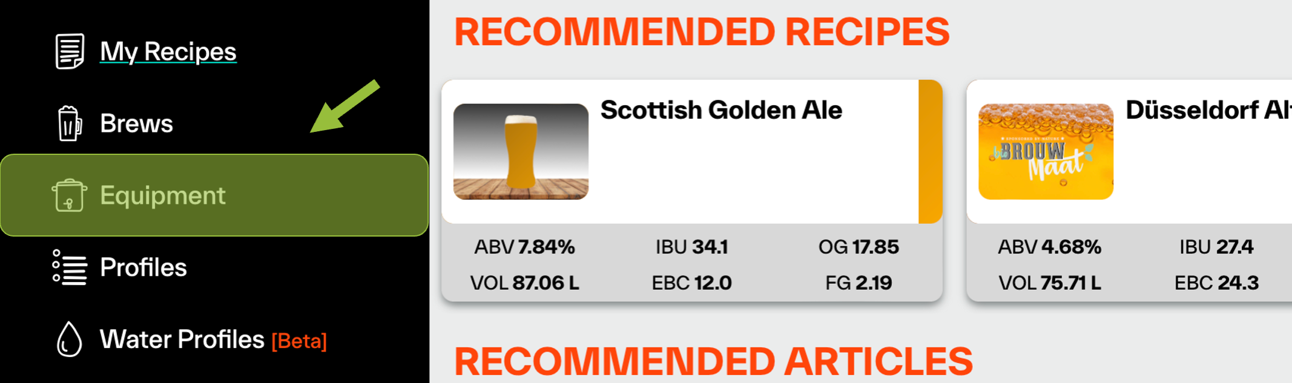
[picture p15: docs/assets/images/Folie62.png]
<figure><figcaption></figcaption></figure>

### Step 2: Add Fermentation device

The Hydrom should be added as a "Fermentation device".

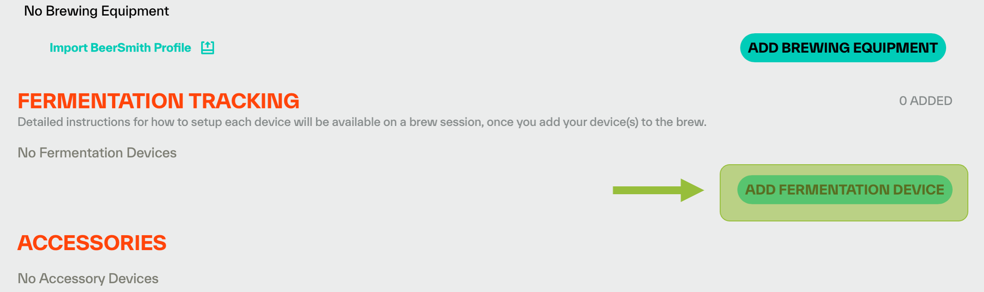
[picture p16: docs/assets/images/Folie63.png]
<figure><figcaption></figcaption></figure>

### Step 3: Select device type

Unfortunately, the Hydrom is not yet natively supported, so you still have to take the detour via the custom device. Please select the custom device.

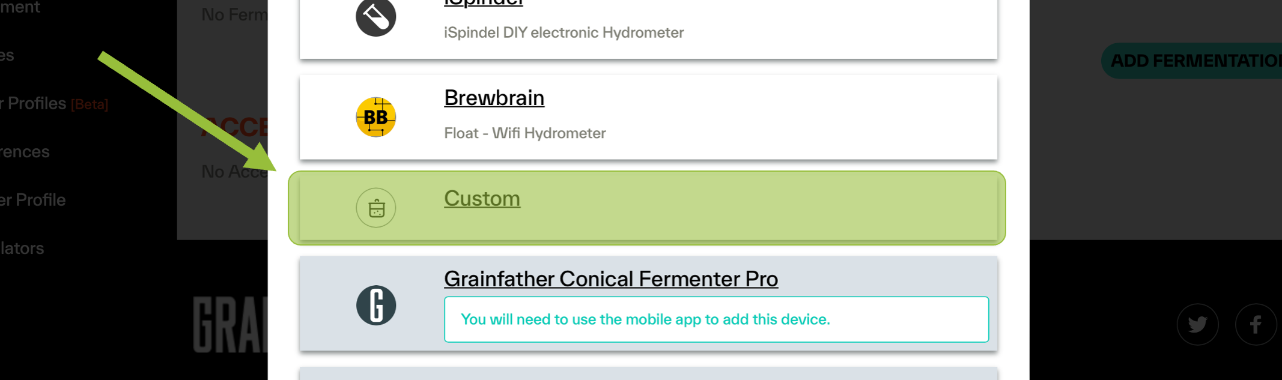
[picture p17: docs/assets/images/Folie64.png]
<figure><figcaption></figcaption></figure>

### Step 5: Choose device name

Here you have to choose a device name (1).\
If there are several devices the name should be chosen speaking.\
Then confirm with "Save" (2).

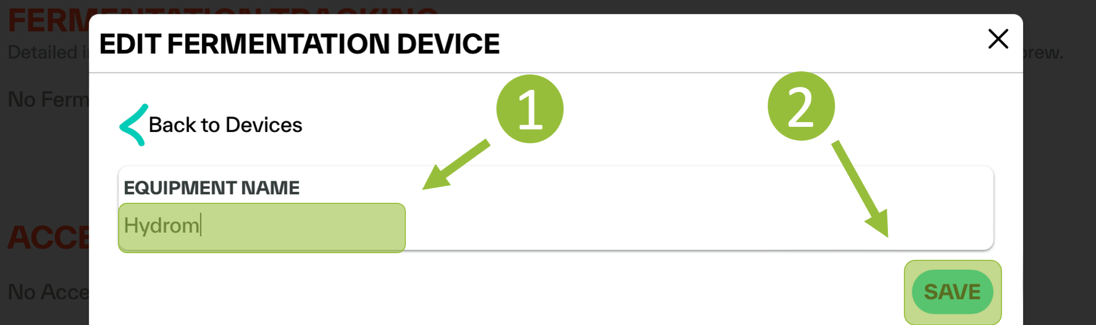
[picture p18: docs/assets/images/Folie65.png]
<figure><figcaption></figcaption></figure>

### Step 6: Copy the ID

If the saving was successful, then the created device will appear in the Fermentation Tracking part.\
Clicking on the information menu opens the window where you can find the connection settings.

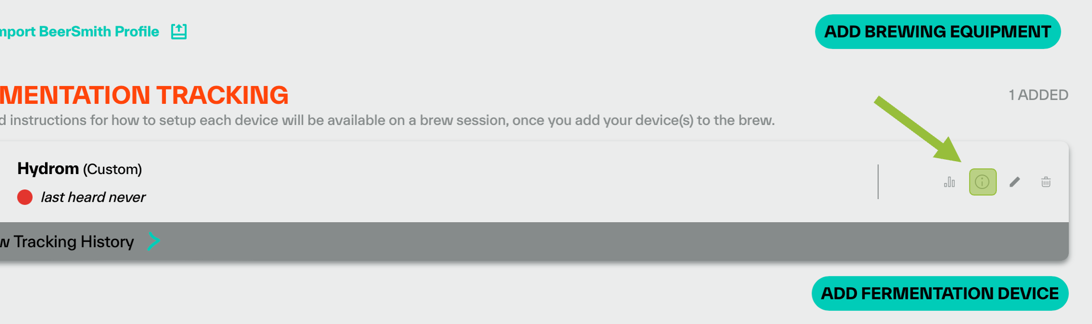
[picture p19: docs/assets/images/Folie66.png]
<figure><figcaption></figcaption></figure>

between "/iot/" and "/costum" there are two words, separated by a minus. these two words must be copied.

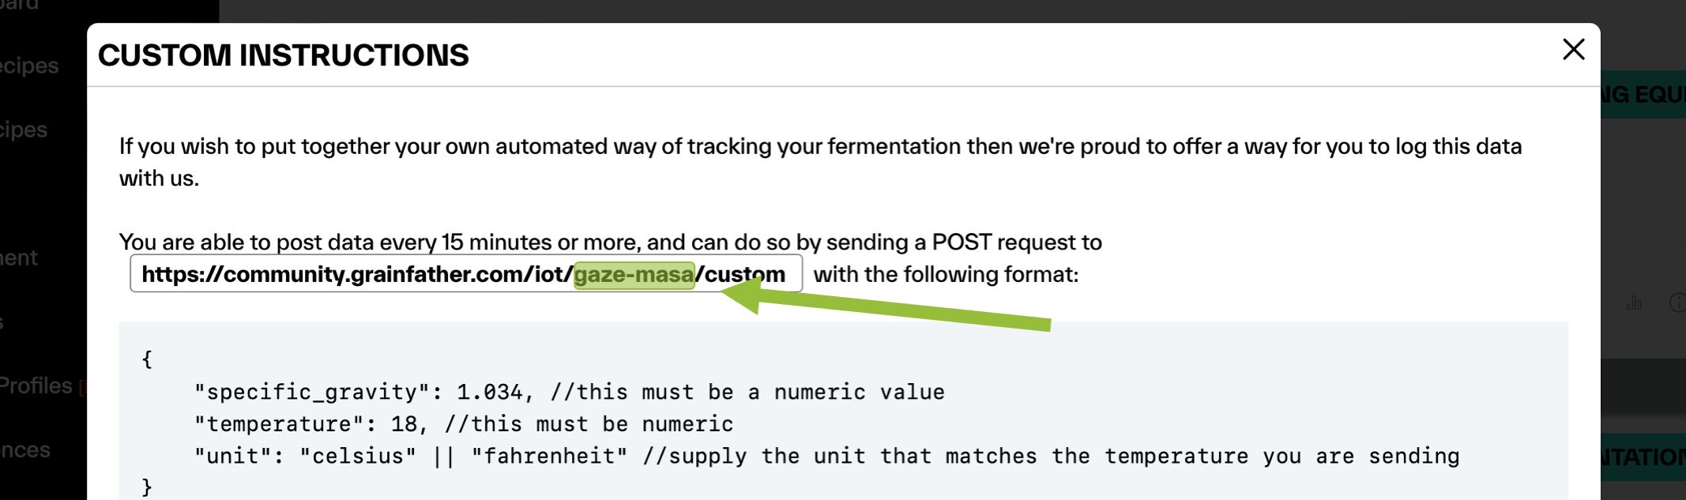
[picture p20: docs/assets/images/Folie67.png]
<figure><figcaption></figcaption></figure>

Now let's switch to the Interface of the Hydrom.

## Setting up the Hydrom

Now open the user interface of the Hydrom, in the best case the Hydrom is already in the network and can be reached easily via http://Hydrom001/.

Otherwise, the Hydrom still needs to be started.

## Step 1: Open the Menue

To access the menu bar you have to click on the three lines in the upper left corner. (See arrow)\
Then the menu bar will open.

access the menu bar by clicking the three lines in the upper left corner

## Step 2: Select "Service"

The "Services" page is a resource that allows users to select and configure various interfaces and cloud services for use with their system. On this page, users can choose from three different interfaces - HTTP, MQTT, and TCP - and several cloud services, and then activate and parameterize these options to suit their needs. This page is a useful tool for those who want to connect their system to the cloud or other external services and customize the way in which data is transmitted and received. With the options available on the "Services" page, users can tailor their system to meet their specific requirements and ensure that it is able to communicate effectively with other devices and systems.

## Step 3: Activate Grainfaher

1. then search for "Grainfather" in the list of services and activate it.
2. a selection of settings will appear.
3. You can keep the settings. You just need to replace the "XXXX-XXXX" part with the two words from the GF app. This way GF knows that the Hydrom is sending data.

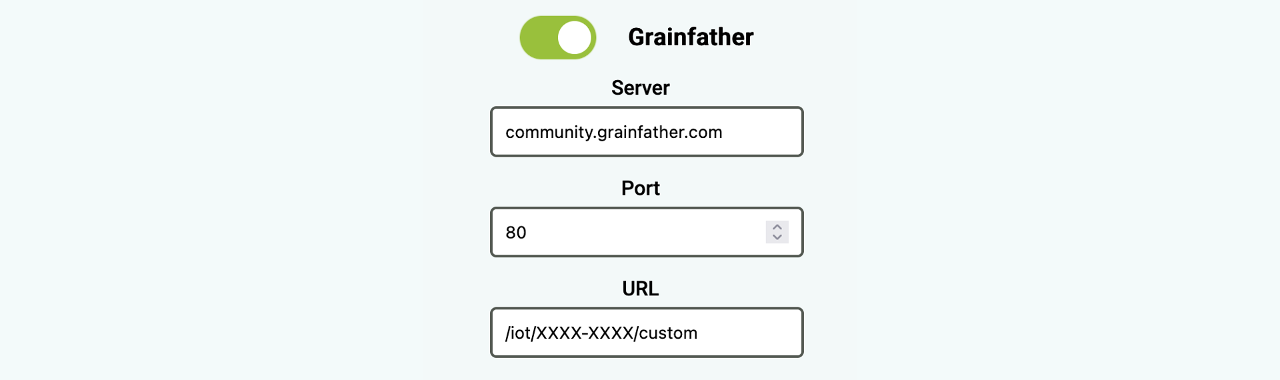
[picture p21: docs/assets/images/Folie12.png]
<figure><figcaption></figcaption></figure>

Now you just have to check if the connection to Grainfather is successful by sending a test message (See chapter [send test message](connect\_to\_grainfather.md#send-test-message)) and if the connection was successful you have to put the Hydrom into [deep sleep](../configuration/enable-deepsleep.md) so that the readings are sent constantly in the set time.

### additional settings

In order not to consume too much power, we would turn Bluetooth off when it is not needed. It was documented here:

[Enable Bluetooth on the Hydrom](bluetooth/README.md)

In order for the Hydrom to transmit the data reliably, a DeepSleep time must be set. This is documented on this page:

[enable-deepsleep.md](../configuration/enable-deepsleep.md)

### Save Settings

Saving the data is important because it is the only way to connect to the service after waking up from DeepSleep.

Pressing the "save" button saves the settings.

You can check whether the saving was successful by looking at the settings file at http://Hydrom001/settings.json/. to check if the save was successful. This file is the permanent memory of the Hydrom.

A second way to check the saving is to reload the page (all modern browsers offer this Feature). If the properties are then reloaded, the Hydrom has accepted them, otherwise the old settings are reloaded.

### Send Test-message

By activating this button, you can check whether the Hydrom has a connection to the service and to the individual parts of the service. If you now click on "Save", the set services are executed once and the page is reloaded. On the new page you can see whether the servers are accessible and the ports are open.

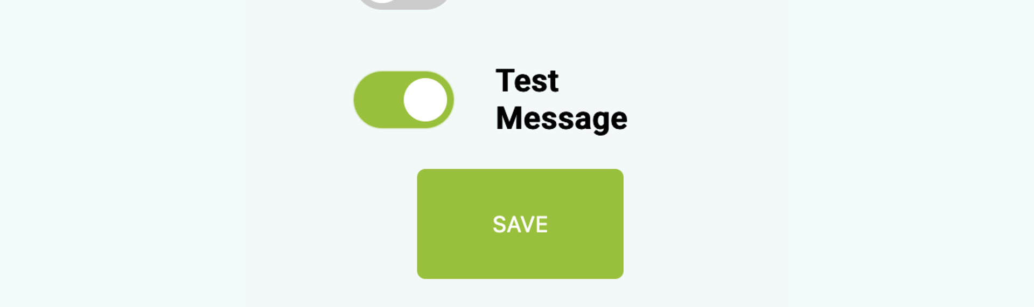
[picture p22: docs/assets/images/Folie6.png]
Sending a test message can greatly simplify the process of checking the connection.


### activate DeepSleep

Activating DeepSleep is mandatory for the Hydrom to be able to send data. If DeepSleep is activated, the Hydrom wakes up after the set time and sends the data to the set service. Afterwards, the Hydrom goes back to sleep and waits for the new service.

[enable-deepsleep.md](../configuration/enable-deepsleep.md)

!!! tip
    To ensure that the device sends measured values to the Service in the set interval as intended, the Hydrom must be put into deep sleep.

    There are two ways to put the Hydrom into deep sleep.

    Turning the _**power switch off and on**_ is the easiest way to put the Hydrom into deep sleep.

    The alternative way is to put it to sleep _**via the UI**_. To do this, open the navigation bar and go to the "DeepSleep" tab.

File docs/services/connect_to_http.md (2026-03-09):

---
description: >-
  Hypertext Transfer Protocol (HTTP) is an application-layer protocol for
  transmitting hypermedia documents. It was designed for communication between
  web browsers and web servers.
cover: https://labs.tadigital.com/wp-content/uploads/2019/11/http.jpg
coverY: 0
---

# Send Measurements via Webhook

!!! tip
    **Prerequisite:**

    1. **Access to user interface**\
       To make this setting, you must have access to the user interface. If this is not the case, see here how to do it:[access-to-the-user-interface.md](access-to-the-user-interface.md)
    2. **Access to an http-Server server/Cloud Service**.\
       An http-Server server has been set up or there is access to a cloud http-Server.

## Datatransfer

### Via URL

If placeholders are used in the URL specified in the "URL", the hydrom will replace them with the current variables.

An example would be: {VALUE\_TILT\_P} --> 15.3\
{VALUE\_TEMPERATURE\_C} --> 25.3

* **{NAME\_DEVICE}** If this variable is used, the hydrom replaces this placeholder with the current name of the hydrom. Default: "Hydrom001
* **{VALUE\_TEMPERATURE\_C}** If this variable is used, the Hydrom replaces this placeholder with the currently measured temperature. The unit of this variable is Celsius
* **{VALUE\_TILT\_P}** If this variable is used, the Hydrom replaces this placeholder with the currently measured temperature. The unit of this variable is Plato
* **{VALUE\_TILT\_SG}** If this variable is used, the Hydrom replaces this placeholder with the currently measured tilt. The unit of this variable is specific Gravity
* **{VALUE\_TILT\_G}** If this variable is used, the Hydrom replaces this placeholder with the currently measured tilt. The unit of this variable is Gravity
* **{VALUE\_RSSI}** If this variable is used, the Hydrom replaces this placeholder with the currently measured tilt.
* **{VALUE\_BATTERY\_VOLTAGE}** If this variable is used, the Hydrom replaces this placeholder with the currently measured Batteryvoltage. The unit of this variable is Volt
* **{VALUE\_BATTERY\_PERCENTAGE}** If this variable is used, the Hydrom replaces this placeholder with the current battery level. The unit of this variable is Percent.

#### Example URL

```url
https://maker.ifttt.com/trigger/hydrom/with/key/clLb9jfjgngkdovIx?value1={VALUE_TILT_G}&value2={VALUE_TEMPERATURE_C}&value3={VALUE_BATTERY_PERCENTAGE}
```

<figure><figcaption></figcaption></figure>

### via JSON

The hydrom sends, if you have activated "http", then the hydrom sends a JSON file to the path specified in the "URL".\
How the file looks like and what the parameters contain you can read here.

* **name**\
  Each device has the name "Hydrom001" by default. This name can be changed at any time to distinguish several devices from each other.\
  [changing-the-hydrom-name.md](../configuration/changing-the-hydrom-name.md)\\
* **angle**\
  This reading is the raw reading of the slope of the hydrom without any processing.\\
* **temperature**\
  This value is the measured temperature in degrees Celsius.\\
* **temp\_units**\
  A "C" for Celsius is sent here.\\
* **battery**\
  Battery voltage in V\\
* **gravity**\
  If this variable is used, the Hydrom replaces this placeholder with the current battery level. The unit of this variable is Percent\\
* **interval**\
  The interval during which the measured values are sent (+ approx. 23s).\\
* **RSSI**\
  Wifi transmit power

Sample content of the JSON:

```json
{
"name":"Hydrom001",
"ID":3,
"angle":65.54,
"temperature":26.43,
"temp_units":"C",
"battery":3.9,
"gravity":9.34,
"interval":900,
"RSSI":63.5
}
```

## Step 1: Open the Menue

To access the menu bar you have to click on the three lines in the upper left corner. (See arrow)\
Then the menu bar will open.

access the menu bar by clicking the three lines in the upper left corner

## Step 2: Select "Service"

The "Services" page is a resource that allows users to select and configure various interfaces and cloud services for use with their system. On this page, users can choose from three different interfaces - HTTP, MQTT, and TCP - and several cloud services, and then activate and parameterize these options to suit their needs. This page is a useful tool for those who want to connect their system to the cloud or other external services and customize the way in which data is transmitted and received. With the options available on the "Services" page, users can tailor their system to meet their specific requirements and ensure that it is able to communicate effectively with other devices and systems.

### Activate http-client and change the settings

On the "Service" page, the http-Server service must be activated.

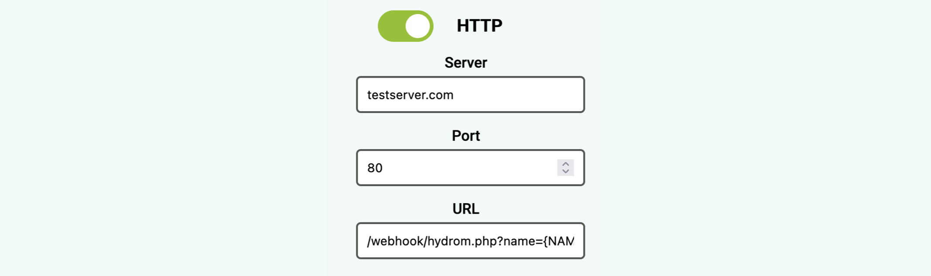
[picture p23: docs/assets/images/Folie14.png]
<figure><figcaption></figcaption></figure>

### additional settings

In order not to consume too much power, we would turn Bluetooth off when it is not needed. It was documented here:

[Enable Bluetooth on the Hydrom](bluetooth/README.md)

In order for the Hydrom to transmit the data reliably, a DeepSleep time must be set. This is documented on this page:

[enable-deepsleep.md](../configuration/enable-deepsleep.md)

### Save Settings

Saving the data is important because it is the only way to connect to the service after waking up from DeepSleep.

Pressing the "save" button saves the settings.

You can check whether the saving was successful by looking at the settings file at http://hydrom001/settings.json/. to check if the save was successful. This file is the permanent memory of the Hydrom.

A second way to check the saving is to reload the page (all modern browsers offer this Feature). If the properties are then reloaded, the hydrom has accepted them, otherwise the old settings are reloaded.

### Send Test-message

By activating this button, you can check whether the Hydrom has a connection to the service and to the individual parts of the service. If you now click on "Save", the set services are executed once and the page is reloaded. On the new page you can see whether the servers are accessible and the ports are open.

Sending a test message can greatly simplify the process of checking the connection.

### activate DeepSleep

Activating DeepSleep is mandatory for the hydrom to be able to send data. If DeepSleep is activated, the hydrom wakes up after the set time and sends the data to the set service. Afterwards, the hydrom goes back to sleep and waits for the new service.

[enable-deepsleep.md](../configuration/enable-deepsleep.md)

!!! tip
    To ensure that the device sends measured values to the Service in the set interval as intended, the Hydrom must be put into deep sleep.

    There are two ways to put the Hydrom into deep sleep.

    Turning the _**power switch off and on**_ is the easiest way to put the Hydrom into deep sleep.

    The alternative way is to put it to sleep _**via the UI**_. To do this, open the navigation bar and go to the "DeepSleep" tab.

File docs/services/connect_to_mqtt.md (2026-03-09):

---
description: >-
  MQTT is an OASIS standard messaging protocol for the Internet of Things (IoT).
  Many services can be connected via this open standard.
cover: https://mqtt.org/assets/downloads/mqtt-logo.png
coverY: 0
---

# To set up the Hydrom as an MQTT publisher

!!! tip
    **Prerequisite:**

    1. **Access to user interface**\
       To make this setting, you must have access to the user interface. If this is not the case, see here how to do it:[access-to-the-user-interface.md](access-to-the-user-interface.md)
    2. **Access to an MQTT server**.\
       An MQTT server has been set up or there is access to a cloud MQTT server.

## Collect the information from the MQTT interface

* Server (IP Adress)
* Port
* Username
* Password
* Topiclevel

## Insert MQTT settings in Hydrom

Now open the user interface of the Hydrom, in the best case the Hydrom is already in the network and can be easily accessed via Webpage.\
If there are questions about how to get to the user interface, the following page is recommended: [access-to-the-user-interface.md](access-to-the-user-interface.md)

Otherwise the Hydrom must still be started.

## Step 1: Open the Menue

To access the menu bar you have to click on the three lines in the upper left corner. (See arrow)\
Then the menu bar will open.

access the menu bar by clicking the three lines in the upper left corner

## Step 2: Select "Service"

The "Services" page is a resource that allows users to select and configure various interfaces and cloud services for use with their system. On this page, users can choose from three different interfaces - HTTP, MQTT, and TCP - and several cloud services, and then activate and parameterize these options to suit their needs. This page is a useful tool for those who want to connect their system to the cloud or other external services and customize the way in which data is transmitted and received. With the options available on the "Services" page, users can tailor their system to meet their specific requirements and ensure that it is able to communicate effectively with other devices and systems.

### Activate MQTT and change the settings

On the "Service" page, the MQTT service must be activated.

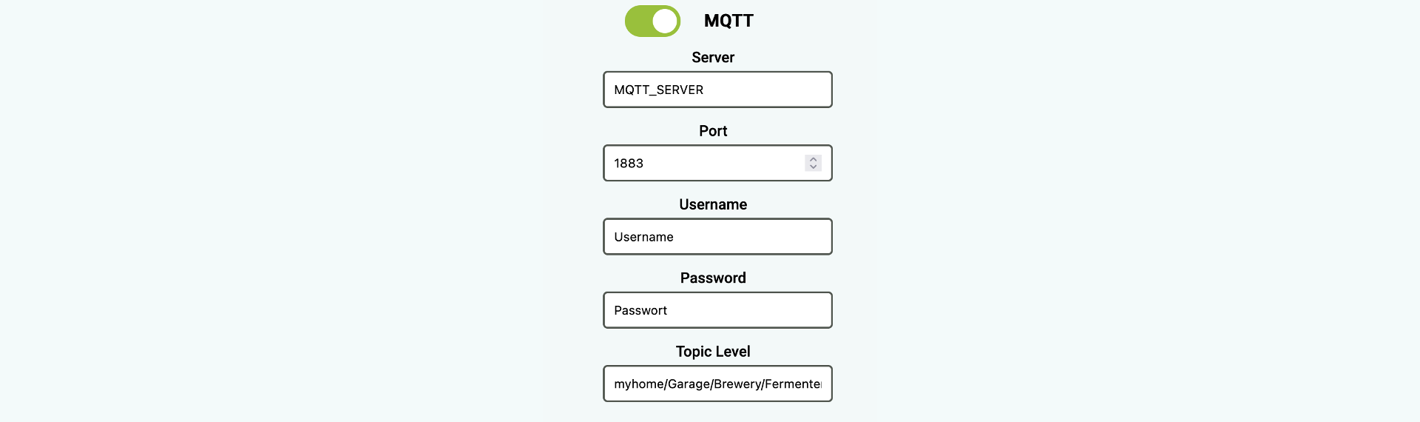
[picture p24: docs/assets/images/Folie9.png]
The settings that are entered here are saved in the Hydrom


\*\*Server Address: Name or IP of the MQTT broker.

**Server Port:** MQTT port, which is 1883 by default.

**Username:** You get the username from the MQTT broker.

**Password:** You get the password from the MQTT broker.

### Topiclevel and explanation

In MQTT, the word Topic refers to a UTF-8 string that the broker uses to filter messages for each connected client. The topic consists of one or more topic levels also called topiclevel. Each topic level is separated by a slash.

<figure><figcaption><p>Explanation Topiclevel</p></figcaption></figure>

### Example values

The following parameters are transmitted via MQTT:

* myhome/garage/brewery/fermenter/hydrom/ tilt\_G 61.51\
  This value is the real angle of the hydrom in space.\
  If the hydrom is horizontal, this value will be 0 degrees.\
  If the hydrom is vertical in the water, this value will be 90 degrees.
* myhome/Garage/Brewery/Fermenterl/Hydrom/tilt\_SG 1.038\
  This value is the calculated Specific Gravity value measured by the Hydrom and calculated using the calculation formula after calibration.
*   myhome/Garage/Brewery/Fermenterl/Hydrom/tilt\_P 9.684916496

    This value is the calculated Plato value measured by the Hydrom and calculated with the calculation formula after calibration.
*   myhome/Garage/Brewery/Fermenterl/Hydrom/temperature 20.5

    This is the measured temperature in degrees Celsius.
*   myhome/Garage/Brewery/Fermenterl/Hydrom/temp\_units C

    This is the unit in which the temperature is transmitted
*   myhome/garage/brewery/fermenter/hydrom/battery 4.20

    This is the measured battery voltage.\
    100%=4,20V\
    0%=3V
*   myhome/Garage/Brewery/Fermenterl/Hydrom/gravity 9.68

    This value is the calculated Plato value measured by the Hydrom and calculated with the calculation formula after calibration.
*   myhome/Garage/Brewery/Fermenterl/Hydrom/interval 900

    This is the transmission period. Here a measured value is transmitted every 900s
*   myhome/Garage/Brewery/Fermenterl/Hydrom/RSSI-60

    The transmission power of the WLAN.

### additional settings

In order not to consume too much power, we would turn Bluetooth off when it is not needed. It was documented here:

[Enable Bluetooth on the Hydrom](bluetooth/README.md)

In order for the Hydrom to transmit the data reliably, a DeepSleep time must be set. This is documented on this page:

[enable-deepsleep.md](../configuration/enable-deepsleep.md)

### Save Settings

Saving the data is important because it is the only way to connect to the service after waking up from DeepSleep.

Pressing the "save" button saves the settings.

You can check whether the saving was successful by looking at the settings file at http://hydrom001/settings.json/. to check if the save was successful. This file is the permanent memory of the Hydrom.

A second way to check the saving is to reload the page (all modern browsers offer this Feature). If the properties are then reloaded, the hydrom has accepted them, otherwise the old settings are reloaded.

### Send Test-message

By activating this button, you can check whether the Hydrom has a connection to the service and to the individual parts of the service. If you now click on "Save", the set services are executed once and the page is reloaded. On the new page you can see whether the servers are accessible and the ports are open.

Sending a test message can greatly simplify the process of checking the connection.

### activate DeepSleep

Activating DeepSleep is mandatory for the hydrom to be able to send data. If DeepSleep is activated, the hydrom wakes up after the set time and sends the data to the set service. Afterwards, the hydrom goes back to sleep and waits for the new service.

[enable-deepsleep.md](../configuration/enable-deepsleep.md)

!!! tip
    To ensure that the device sends measured values to the Service in the set interval as intended, the Hydrom must be put into deep sleep.

    There are two ways to put the Hydrom into deep sleep.

    Turning the _**power switch off and on**_ is the easiest way to put the Hydrom into deep sleep.

    The alternative way is to put it to sleep _**via the UI**_. To do this, open the navigation bar and go to the "DeepSleep" tab.

## View Hydrom readings on the MQTT broker

### Check if the topic has been published

Here it is recommended to use a MQTT client app. Under IOS I recommend the app MQTTAnalyzer.

With this app you can connect to the broker and subscribe to the topiclevel and get the measured values. This way you can make sure in the first step that the data is sent correctly and received correctly by the broker.

### The further procedure is strongly dependent on the MQTT client.

It is not possible to describe a general procedure here. In the future, sample configurations for the most common clients will appear here, for which I ask for your help. Please send me your working configurations and I will publish them here, anonymized of course.

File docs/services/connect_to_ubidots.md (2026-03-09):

---
description: >-
  Ubidots is a cloud service that accepts, stores and visualizes measurement
  data from internet-enabled devices.
cover: >-
  https://files.startupranking.com/startup/thumb/6796_043b01ef967da629abc843eca1f2a477906da07a_ubidots_l.png
coverY: 0
---

# Connect the Hydrom to Ubidots

!!! tip
    **Prerequisite:**

    1. **Access to the user interface**\
       To make this setting you must have access to the user interface. If this is not the case, see here how to do it:[access-to-the-user-interface.md](access-to-the-user-interface.md)
    2. **Ubidots user account available**\
       An account was created with the cloud provider ubidots. At the time of writing, there is a free account for non-commercial use.\
       https://industrial.ubidots.com/accounts/signup\_industrial/

<figure><figcaption></figcaption></figure>

## Add the hydrom to Ubidots

### Navigate to the Devicemanager

The device management is located at the top center. Here a new device must be added



### Add Blank Device

It is really important that you enter the device name here. E.g. "Hydrom001" in the default configuration

Choose Device Name

### Copy the token

After adding the device, the device must be opened and then the token must be copied (see red marking).

Copy Ubidots Token

## Insert Service settings in Hydrom

Now open the user interface of the Hydrom, in the best case the Hydrom is already in the network and can be easily accessed via Webpage.\
If there are questions about how to get to the user interface, the following page is recommended: [access-to-the-user-interface.md](access-to-the-user-interface.md)

Otherwise the Hydrom must still be started.

## Step 1: Open the Menue

To access the menu bar you have to click on the three lines in the upper left corner. (See arrow)\
Then the menu bar will open.

access the menu bar by clicking the three lines in the upper left corner

## Step 2: Select "Service"

The "Services" page is a resource that allows users to select and configure various interfaces and cloud services for use with their system. On this page, users can choose from three different interfaces - HTTP, MQTT, and TCP - and several cloud services, and then activate and parameterize these options to suit their needs. This page is a useful tool for those who want to connect their system to the cloud or other external services and customize the way in which data is transmitted and received. With the options available on the "Services" page, users can tailor their system to meet their specific requirements and ensure that it is able to communicate effectively with other devices and systems.

## Step 3: Activate Ubidots and change the settings

On the "Service" page, the Ubidots service must be activated.

Activating the Ubidots interface and entering the token

### additional settings

In order not to consume too much power, we would turn Bluetooth off when it is not needed. It was documented here:

[Enable Bluetooth on the Hydrom](bluetooth/README.md)

In order for the Hydrom to transmit the data reliably, a DeepSleep time must be set. This is documented on this page:

[enable-deepsleep.md](../configuration/enable-deepsleep.md)

### Save Settings

Saving the data is important because it is the only way to connect to the service after waking up from DeepSleep.

Pressing the "save" button saves the settings.

You can check whether the saving was successful by looking at the settings file at http://hydrom001/settings.json/. to check if the save was successful. This file is the permanent memory of the Hydrom.

A second way to check the saving is to reload the page (all modern browsers offer this Feature). If the properties are then reloaded, the hydrom has accepted them, otherwise the old settings are reloaded.

### Send Test-message

By activating this button, you can check whether the Hydrom has a connection to the service and to the individual parts of the service. If you now click on "Save", the set services are executed once and the page is reloaded. On the new page you can see whether the servers are accessible and the ports are open.

Sending a test message can greatly simplify the process of checking the connection.

### activate DeepSleep

Activating DeepSleep is mandatory for the hydrom to be able to send data. If DeepSleep is activated, the hydrom wakes up after the set time and sends the data to the set service. Afterwards, the hydrom goes back to sleep and waits for the new service.

[enable-deepsleep.md](../configuration/enable-deepsleep.md)

!!! tip
    To ensure that the device sends measured values to the Service in the set interval as intended, the Hydrom must be put into deep sleep.

    There are two ways to put the Hydrom into deep sleep.

    Turning the _**power switch off and on**_ is the easiest way to put the Hydrom into deep sleep.

    The alternative way is to put it to sleep _**via the UI**_. To do this, open the navigation bar and go to the "DeepSleep" tab.

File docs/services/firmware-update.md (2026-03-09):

---
description: >-
  The Hydrom has the possibility to install the firmware via the WebUI. Here you
  will find the instructions on how to do this.
hidden: true
---

# Do Firmwareupdate

## Firmware Update

!!! tip
    **Precondition:**\
    To Upload the Firmware you must have access to the user interface. If this is not the case, see here how to do it:[access-to-the-user-interface.md](access-to-the-user-interface.md)

    The hydrom must be fully charged

You can download the latest version of the firmware from [this site]. To do this, go to the download section of the website.

**Please read all instructions carefully** to make sure you download the correct version.\
Updating the firmware - can be done via the web interface of the Hydrom.\
The procedure is the same for each:\
Windows, macOS and LINUX.

## Download the latest update

It is generally a good idea to keep the firmware of your devices up to date because newer versions of firmware can often fix bugs and security vulnerabilities that were present in previous versions. Outdated firmware can leave your device susceptible to security risks, such as malicious attacks, which can compromise the security and privacy of your data. Updating the firmware can also often improve the performance and functionality of your device, providing access to new features and enhancements. In order to ensure the best possible experience with your device, it is important to keep the firmware up to date.\
\
You can find the latest firmware here:

You can find all firmware releases on the [GitHub Releases page](https://github.com/TjGer22/Hydrom/releases).

### Step 1: Open the Menue

To access the menu bar you have to click on the three lines in the upper left corner. (See arrow)\
Then the menu bar will open.

access the menu bar by clicking the three lines in the upper left corner

### Step 2: Select "Update"

### Step 3: Select the Update device

You can download the updates from our download section, unzip the file and select it in the web interface.

### Step 4: Start the Update

Press the "Update"-Button to start the process.\
This process may take a few minutes.

!!! info
    You will know that the Hydrom has installed the new firmware by the Hydrom shutting down and then going into DeepSleep mode (easily recognized by the status LEDs going out).

    How to wake up the Hydrom can be found here:

    [Wake Up the Hydrom](wakeup-the-hydrom.md)

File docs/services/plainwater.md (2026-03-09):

---
description: >-
  The "Plainwater" method is a calibration method that is very fast and
  uncomplicated. The density of the current liquid is measured and the
  hydrometer calculates from experience the formula
---

# Do PlainWaterCalibration

!!! tip
    **Prerequisite:**

    1. user interface access\
       To make this setting, you must have access to the user interface. If this is not the case, see here how to do it: [Access the Userinterface](../troubleshooting/webui-unreachable.md)
    2. Equipment needed:
       1. water tank in which the hydrom can float.

1. place the hydrom in 20 degrees cold water and navigate to "Calibration
2. Activate the "Plainwater method".
3. Confirm the calibration with "Start".
4. The Hydrom measures the current position and compares it with the reference measurement values.
5. If there is an error message saying that the angle is over >90 degrees, please perform a position sensor calibration. This has only been necessary for a few customers so far and only occurs after the update to 1.5.1. [Do Attitude Sensor Calibration](../calibration/attitude-sensor-calibration.md)
6. The Hydrom now has a new calibration.

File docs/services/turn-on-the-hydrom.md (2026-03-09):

---
description: This operation deals with switching on the Hydrom.
---

# Turn on the Hydrom

!!! info
    There is a label on the circuit board below the switch, which indicates the direction in which the switch contact must be moved.

1. Open the Hydrom by twisting off the lid.
2. Slide the switch contact to the center.
3.  The hydrom now starts to DeepSleep mode.

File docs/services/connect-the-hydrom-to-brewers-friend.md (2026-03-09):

---
description: >-
  The Hydrom is compatible with Brewer's Friend! To integrate the Hydrom into
  the online service you can, you can use the http interface.
cover: >-
  https://brewersfriend.postaffiliatepro.com/accounts/default1/files/logo_with_name_20170723.png
coverY: 0
---

# Connect the Hydrom to Brewers Friend

!!! tip
    **Prerequisite:**

    1. **Access to user interface**\
       To make this setting, you must have access to the user interface. If this is not the case, see here how to do it:[access-to-the-user-interface.md](access-to-the-user-interface.md)
    2. **Brewer´s Friend user account available**\
       An account has been created with Brewer's Friend. The test account is not sufficient to connect the hydrom. Please upgrade the trial account\
       https://www.brewersfriend.com

## Add the hydrom to Brewers Friend

Log in to Brewer's Friend

### Navigate to the Devicemanager

Under the profile there is a menu "Integrations". All compatible devices are listed here.



### Copy the token

The Hydrom is not yet natively supported, so you have to take the detour via the iSpindle interface.\
Here we are interested in the address of the server (1) and the token (2).\
\
Copy the token, you will need it in the next few steps.

Copy Brewer´Friend Token

## Configuring the Hydrom

## Step 1: Open the Menue

To access the menu bar you have to click on the three lines in the upper left corner. (See arrow)\
Then the menu bar will open.

access the menu bar by clicking the three lines in the upper left corner

## Step 2: Select "Service"

The "Services" page is a resource that allows users to select and configure various interfaces and cloud services for use with their system. On this page, users can choose from three different interfaces - HTTP, MQTT, and TCP - and several cloud services, and then activate and parameterize these options to suit their needs. This page is a useful tool for those who want to connect their system to the cloud or other external services and customize the way in which data is transmitted and received. With the options available on the "Services" page, users can tailor their system to meet their specific requirements and ensure that it is able to communicate effectively with other devices and systems.

### Activate http-client and change the settings

On the "Service" page, the http-Server service must be activated.

<figure><figcaption></figcaption></figure>

**1: Server Address:** Insert "log.brewersfriend.com" here.

**2: Server Port:** Insert "80" here.

**3: URL:** here "/ispindel/" must be entered. and behind it the token of the Brewers Friend Service. For example "/ispindel/eb4f9af1492c3fc554471eb4f9af1492c3fc554471".

### Check if the Testmessage arrived

If a test message has been sent from the hydrom, as described below, then it is possible to check whether the service has also received the message.

On the integrations page, click on "Device Settings" as shown in the following picture:

<figure><figcaption></figcaption></figure>

And then you can click on "Show all" as shown in the following picture:

<figure><figcaption></figcaption></figure>

If then this message appears, then you have done it. Just put it to sleep and then you are ready to go.

<figure><figcaption></figcaption></figure>

### additional settings

In order not to consume too much power, we would turn Bluetooth off when it is not needed. It was documented here:

[Enable Bluetooth on the Hydrom](bluetooth/README.md)

In order for the Hydrom to transmit the data reliably, a DeepSleep time must be set. This is documented on this page:

[enable-deepsleep.md](../configuration/enable-deepsleep.md)

### Save Settings

Saving the data is important because it is the only way to connect to the service after waking up from DeepSleep.

Pressing the "save" button saves the settings.

You can check whether the saving was successful by looking at the settings file at http://hydrom001/settings.json/. to check if the save was successful. This file is the permanent memory of the Hydrom.

A second way to check the saving is to reload the page (all modern browsers offer this Feature). If the properties are then reloaded, the hydrom has accepted them, otherwise the old settings are reloaded.

### Send Test-message

By activating this button, you can check whether the Hydrom has a connection to the service and to the individual parts of the service. If you now click on "Save", the set services are executed once and the page is reloaded. On the new page you can see whether the servers are accessible and the ports are open.

Sending a test message can greatly simplify the process of checking the connection.

### activate DeepSleep

Activating DeepSleep is mandatory for the hydrom to be able to send data. If DeepSleep is activated, the hydrom wakes up after the set time and sends the data to the set service. Afterwards, the hydrom goes back to sleep and waits for the new service.

[enable-deepsleep.md](../configuration/enable-deepsleep.md)

!!! tip
    To ensure that the device sends measured values to the Service in the set interval as intended, the Hydrom must be put into deep sleep.

    There are two ways to put the Hydrom into deep sleep.

    Turning the _**power switch off and on**_ is the easiest way to put the Hydrom into deep sleep.

    The alternative way is to put it to sleep _**via the UI**_. To do this, open the navigation bar and go to the "DeepSleep" tab.

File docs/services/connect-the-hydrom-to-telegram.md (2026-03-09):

---
description: >-
  Telegram is a free chat and messaging service. It allows   users to exchange
  text messages securely and quickly. But you can also use it   also use it as a
  reception service for the hydrom.
---

# Connect the Hydrom to Telegram

!!! tip
    **Prerequisite:**

    1. **Access to user interface**\
       To make this setting, you must have access to the user interface. If this is not the case, see here how to do it:[access-to-the-user-interface.md](access-to-the-user-interface.md)
    2. **Telegram account available**.\
       An account has been created with the Telegram messaging service.
    3. **Telegram App was downloaded**.\
       https://telegram.org

## Prepare the service

### Create a bot

Log in to Telegram and search for the bot "BotFather". Send a message to Bot Father with the text "/newbot" (without quotes). Choose a name and a username for your bot. The username must end with "bot". The usernames are only used to identify the chat in Telegram. Chat with the botfather by creating a bot

### Identify the Telegram ChatID

Start a conversation with the bot for which you want to determine the chat ID. Call the URL "https://api.telegram.org/bot\[API\_TOKEN]/getUpdates", inserting the bot's API token in place of \[API\_TOKEN]. This will give you a JSON response with information about all of the bot's recent conversations. In the response, look for the "message" section, and note the chat ID, which is given as "chat" -> "id". api.telegram response with the chatID

## Insert Telegram settings in Hydrom

Now open the user interface of the Hydrom, in the best case the Hydrom is already in the network and can be easily accessed via Webpage.\
If there are questions about how to get to the user interface, the following page is recommended: [access-to-the-user-interface.md](access-to-the-user-interface.md)

Otherwise the Hydrom must still be started.

## Step 1: Open the Menue

To access the menu bar you have to click on the three lines in the upper left corner. (See arrow)\
Then the menu bar will open.

access the menu bar by clicking the three lines in the upper left corner

## Step 2: Select "Service"

The "Services" page is a resource that allows users to select and configure various interfaces and cloud services for use with their system. On this page, users can choose from three different interfaces - HTTP, MQTT, and TCP - and several cloud services, and then activate and parameterize these options to suit their needs. This page is a useful tool for those who want to connect their system to the cloud or other external services and customize the way in which data is transmitted and received. With the options available on the "Services" page, users can tailor their system to meet their specific requirements and ensure that it is able to communicate effectively with other devices and systems.

### Step 3: Activate Telegram and change the settings.

On the "Service" page, you need to activate the Telegram service. Copy the \[API\_TOKEN] and the ChatID into the fields provided.

The settings made here will be used in the Hydrom

After the service is set up in the hydrom and the hydrom is put into deep sleep, the data is sent to the Telegram chat at the set interval as shown here.

Image of the Telegram Chat

### additional settings

In order not to consume too much power, we would turn Bluetooth off when it is not needed. It was documented here:

[Enable Bluetooth on the Hydrom](bluetooth/README.md)

In order for the Hydrom to transmit the data reliably, a DeepSleep time must be set. This is documented on this page:

[enable-deepsleep.md](../configuration/enable-deepsleep.md)

### Save Settings

Saving the data is important because it is the only way to connect to the service after waking up from DeepSleep.

Pressing the "save" button saves the settings.

You can check whether the saving was successful by looking at the settings file at http://hydrom001/settings.json/. to check if the save was successful. This file is the permanent memory of the Hydrom.

A second way to check the saving is to reload the page (all modern browsers offer this Feature). If the properties are then reloaded, the hydrom has accepted them, otherwise the old settings are reloaded.

### activate DeepSleep

Activating DeepSleep is mandatory for the hydrom to be able to send data. If DeepSleep is activated, the hydrom wakes up after the set time and sends the data to the set service. Afterwards, the hydrom goes back to sleep and waits for the new service.

[enable-deepsleep.md](../configuration/enable-deepsleep.md)

!!! tip
    To ensure that the device sends measured values to the Service in the set interval as intended, the Hydrom must be put into deep sleep.

    There are two ways to put the Hydrom into deep sleep.

    Turning the _**power switch off and on**_ is the easiest way to put the Hydrom into deep sleep.

    The alternative way is to put it to sleep _**via the UI**_. To do this, open the navigation bar and go to the "DeepSleep" tab.

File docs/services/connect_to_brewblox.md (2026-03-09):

---
description: >-
  Brewblox is a modern, open source brewery control platform. It runs on a
  central  (on premise) server to which multiple temperature controllers and
  sensors can connect in an intuitive web interface.
cover: https://www.brewblox.com/brewpi-wordmark.svg
coverY: 0
---

# Connect the Hydrom to Brewblox

## Connect the Hydrom to Brewblox

### Precondition

!!! tip
    To make this setting you must have access to the user interface. If this is not the case, see here how to do it:[access-to-the-user-interface.md](access-to-the-user-interface.md)

    In order to connect the Hydrom to Brewblox, a Brewblox server must first be set up.

    See [Brewblox startup guide](https://brewblox.netlify.app/user/startup.html#what-you-will-need) to set up a Pi with Brewblox.

### Adding Hydrom to BrewBlox

The Hydrom is natively supported by Brewblox. This means that once the hydrom is set up, the readings are automatically sent to the server and can be used. Multiple devices can also be used in parallel by customising the name of the Hydrom.

There are two basic ways to connect the Hydrom to Brewblox.

1. via WLAN\
   Assuming the Hydrom is on the same network as the Brewblox server, it is best to set it up via WLAN. How to do this is described in this manual.
2. via Bluetooth\
   If the Brewblox server is not in the WLAN and there is no access to a WLAN, the Hydrom can only be connected via Bluetooth. No instructions have yet been written for this. In principle, you can say, follow the instructions for the Tilt Hydrometer: [https://www.brewblox.com/user/services/tilt.html](https://www.brewblox.com/user/services/tilt.html)\
   These instructions also apply 1:1 to the Hydrom.

### Configuring the Hydrom

### Step 1: Open the Menue

To access the menu bar you have to click on the three lines in the upper left corner. (See arrow)\
Then the menu bar will open.

access the menu bar by clicking the three lines in the upper left corner

## Step 2: Select "Service"

The "Services" page is a resource that allows users to select and configure various interfaces and cloud services for use with their system. On this page, users can choose from three different interfaces - HTTP, MQTT, and TCP - and several cloud services, and then activate and parameterize these options to suit their needs. This page is a useful tool for those who want to connect their system to the cloud or other external services and customize the way in which data is transmitted and received. With the options available on the "Services" page, users can tailor their system to meet their specific requirements and ensure that it is able to communicate effectively with other devices and systems.

## Step 3: Activate Brewblox

Change the setting of the Hydrom

**Server Address:** Name or IP of the Brewblox/MQTT broker

**Server Port:** MQTT port, which is 1883 by default.

**Path / URI:** must be set to "brewcast/history", which is the MQTT-Topic for the history service.

**Username / Password:** This field remains empty because Brewblox does not yet support MQTT with authentication.

The two indicators next to the IP address of the server and the port of the server then turn green/red when a test message has been sent.\
The Hydrom then checks whether the address can be reached and if so, whether the destination port is open.

#### additional settings

In order not to consume too much power, we would turn Bluetooth off when it is not needed. It was documented here:

[Enable Bluetooth on the Hydrom](bluetooth/README.md)

In order for the Hydrom to transmit the data reliably, a DeepSleep time must be set. This is documented on this page:

[enable-deepsleep.md](../configuration/enable-deepsleep.md)

#### Save Settings

Saving the data is important because it is the only way to connect to the service after waking up from DeepSleep.

Pressing the "save" button saves the settings.

You can check whether the saving was successful by looking at the settings file at http://hydrom001/settings.json/. to check if the save was successful. This file is the permanent memory of the Hydrom.

A second way to check the saving is to reload the page (all modern browsers offer this Feature). If the properties are then reloaded, the hydrom has accepted them, otherwise the old settings are reloaded.

#### Send Test-message

By activating this button, you can check whether the Hydrom has a connection to the service and to the individual parts of the service. If you now click on "Save", the set services are executed once and the page is reloaded. On the new page you can see whether the servers are accessible and the ports are open.

Sending a test message can greatly simplify the process of checking the connection.

#### activate DeepSleep

Activating DeepSleep is mandatory for the hydrom to be able to send data. If DeepSleep is activated, the hydrom wakes up after the set time and sends the data to the set service. Afterwards, the hydrom goes back to sleep and waits for the new service.

[enable-deepsleep.md](../configuration/enable-deepsleep.md)

!!! tip
    To ensure that the device sends measured values to the Service in the set interval as intended, the Hydrom must be put into deep sleep.

    There are two ways to put the Hydrom into deep sleep.

    Turning the _**power switch off and on**_ is the easiest way to put the Hydrom into deep sleep.

    The alternative way is to put it to sleep _**via the UI**_. To do this, open the navigation bar and go to the "DeepSleep" tab.

## Configuration of the Hydrom in the Brewblox

#### Add a dashboard

In order to view the measured values of the Hydrom, a dashboard must first be created if one does not already exist.

Create Brewblox Dashboard

#### Add widget

The measured values of the Hydrom can be visualised via a graph. To do this, a widget must first be created.



#### Add graph

Now add a graph to this widget

Select Graph as widget to visualise the readings of the Hydrom

Click on "Create" to create this widget.

Confirm selection

#### Activating the Hydrom

Adding the graph is not enough to display the measured values of the Hydrom. The measured values of the Hydrom do not have to be made visible. To do this, go to the top right corner and click on the two triangles to activate the settings of the graph.

Make settings of the graph

In the settings of the graph, the filter has to be activated. So practically, which measured values do I want to see. For clarity, it is recommended to activate only the required measured values here.

Activate the filters as needed

At the end you see at least the test measurement after which the hydrom was put to sleep but also the measured values in the set interval.

End result: The hydrom delivers measured values to the graph

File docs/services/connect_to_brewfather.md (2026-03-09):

---
description: >-
  Brewfather (https://brewfather.app/) is a software cloud solution for brewing
  beer. It allows the creation, synchronisation and exchange of recipes. The
  Hydrom helps to track the fermentation process
cover: https://i.ytimg.com/vi/1Sjh_-V1Tg8/maxresdefault.jpg
coverY: 0
---

# Connect the Hydrom to Brewfather

!!! tip
    **Prerequisite:**

    1. **Access to user interface**\
       To make this setting, you must have access to the user interface. If this is not the case, see here how to do it:[access-to-the-user-interface.md](access-to-the-user-interface.md)
    2. **Brewfather user account available**.\
       An account has been created with the cloud provider Brewfather.
    3. **Brewfather App was downloaded**.\
       https://brewfather.app/

## Add the hydrom to the Brewfather

### Activate "iSpindel"

Open the Brewfather app and navigate to the settings. There you activate the device "iSpindel".\
Unfortunately, the detour must still go as long as the Hydrom is not natively supported.. I am in close exchange with the founder, that this grievance will be removed as soon as possible.

Settings selection

### Copy BrewFather Path

To copy the Brewfather link you can either copy the path (1) or use the copy function (2)

The marked parameter must be coupled into the hydrom.

## Insert BrewFather settings in Hydrom

Now open the user interface of the Hydrom, in the best case the Hydrom is already in the network and can be easily accessed via Webpage.\
If there are questions about how to get to the user interface, the following page is recommended: [access-to-the-user-interface.md](access-to-the-user-interface.md)

Otherwise the Hydrom must still be started.

## Step 1: Open the Menue

To access the menu bar you have to click on the three lines in the upper left corner. (See arrow)\
Then the menu bar will open.

access the menu bar by clicking the three lines in the upper left corner

## Step 2: Select "Service"

The "Services" page is a resource that allows users to select and configure various interfaces and cloud services for use with their system. On this page, users can choose from three different interfaces - HTTP, MQTT, and TCP - and several cloud services, and then activate and parameterize these options to suit their needs. This page is a useful tool for those who want to connect their system to the cloud or other external services and customize the way in which data is transmitted and received. With the options available on the "Services" page, users can tailor their system to meet their specific requirements and ensure that it is able to communicate effectively with other devices and systems.

## Step 3: Activate Brewfather and change the settings

On the "Service" page, the "http" service must be activated.

The Server and Port fields in the http field must be filled in as follows.\
The URL must be copied from the Brewfather interface. (The last step of the Brewfather setup)

The settings made here are saved in the hydrom

### additional settings

In order not to consume too much power, we would turn Bluetooth off when it is not needed. It was documented here:

[Enable Bluetooth on the Hydrom](bluetooth/README.md)

In order for the Hydrom to transmit the data reliably, a DeepSleep time must be set. This is documented on this page:

[enable-deepsleep.md](../configuration/enable-deepsleep.md)

### Save Settings

Saving the data is important because it is the only way to connect to the service after waking up from DeepSleep.

Pressing the "save" button saves the settings.

You can check whether the saving was successful by looking at the settings file at http://hydrom001/settings.json/. to check if the save was successful. This file is the permanent memory of the Hydrom.

A second way to check the saving is to reload the page (all modern browsers offer this Feature). If the properties are then reloaded, the hydrom has accepted them, otherwise the old settings are reloaded.

### Send Test-message

By activating this button, you can check whether the Hydrom has a connection to the service and to the individual parts of the service. If you now click on "Save", the set services are executed once and the page is reloaded. On the new page you can see whether the servers are accessible and the ports are open.

Sending a test message can greatly simplify the process of checking the connection.

### activate DeepSleep

Activating DeepSleep is mandatory for the hydrom to be able to send data. If DeepSleep is activated, the hydrom wakes up after the set time and sends the data to the set service. Afterwards, the hydrom goes back to sleep and waits for the new service.

[enable-deepsleep.md](../configuration/enable-deepsleep.md)

!!! tip
    To ensure that the device sends measured values to the Service in the set interval as intended, the Hydrom must be put into deep sleep.

    There are two ways to put the Hydrom into deep sleep.

    Turning the _**power switch off and on**_ is the easiest way to put the Hydrom into deep sleep.

    The alternative way is to put it to sleep _**via the UI**_. To do this, open the navigation bar and go to the "DeepSleep" tab.

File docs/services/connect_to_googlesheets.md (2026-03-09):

---
description: >-
  The Google Sheets software was developed to cover all steps of the brewing
  process brewing process, from mashing to fermentation to storage.
cover: ../assets/images/Folie75.png
coverY: 0
---

# Connect the Hydrom to Google Sheets

!!! tip
    **Prerequisite**

    1. To make this setting, you must have access to the user interface. If you don't, see here how to do it:\
       [Access to the user Interface](access-to-the-user-interface.md)
    2. **Google account available** To use Google Sheets, you need a Google account. You can register here: [https://accounts.google.com](https://google.com)

## Principle behind the Google Sheet integration

After the Hydrom has been successfully put into deep sleep, it will automatically begin submitting its collected and calculated readings to the user's Google account. Following this, Google Sheets automatically creates a new worksheet whose title corresponds to the name of the hydrom in question.

New Sheet

In this newly created Sheet, the received data variables are clearly organized and stored in different columns so that the user can easily access and analyze them.

Contents of the created Sheet

## Prepare the sheet

### Copy the sheet from the Bonorum account

Call the following link:

[https://docs.google.com/spreadsheets/d/1v6VI\_eaHwb0OGDMxZvnlsiRH7fhhiMUscAlDiQi-g14](https://docs.google.com/spreadsheets/d/1v6VI\_eaHwb0OGDMxZvnlsiRH7fhhiMUscAlDiQi-g14)

Click on the File menu and then select "Make a copy"

### Deploy the script

Click on the menu "Extensions" and then on "Apps Script"

Click on the blue "Deploy" button in the upper right corner of the screen and then select "New Deployment"

click on the gear in the type selector, then select "Web App" click on the gear in the type selector, then select "Web App"

Make sure you use your email and that "Everyone" can access the Web APP

Click "Authorize Access" when the window appears and select your Google account.

A dialog box appears with the message "This application is not verified". Select "Advanced" and then "Go to main script (unsafe)."

A dialog box with approval requests is displayed. Select "Allow"

### Copy the token

"Copy" to copy the web app / cloud URL and send it to your app, or you can use our mail option.

## Setting up the Hydrom

Now open the Hydrom's user interface.

### Step 1: Open menu bar

To access the menu bar, you need to click on the three lines in the upper left corner. (See arrow)\
Then the menu bar will open.

open the menu bar by clicking on the three lines in the upper left corner
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

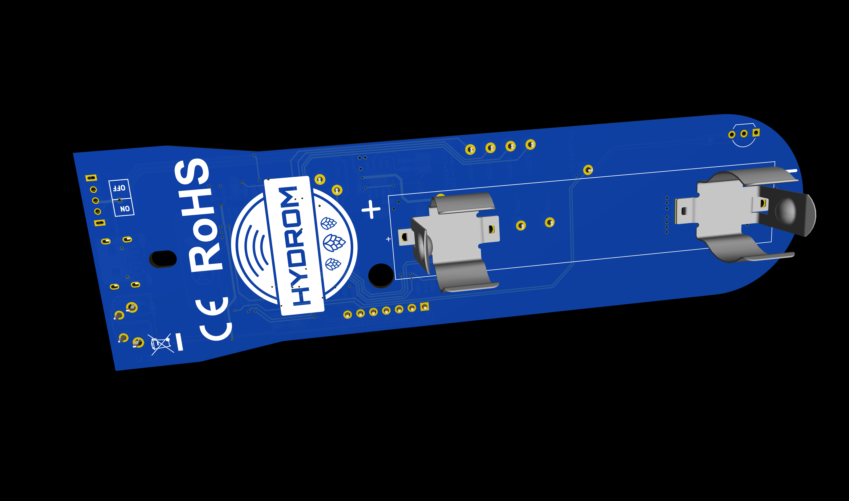
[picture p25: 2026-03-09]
hardware/images/PCB2 Bottom.png

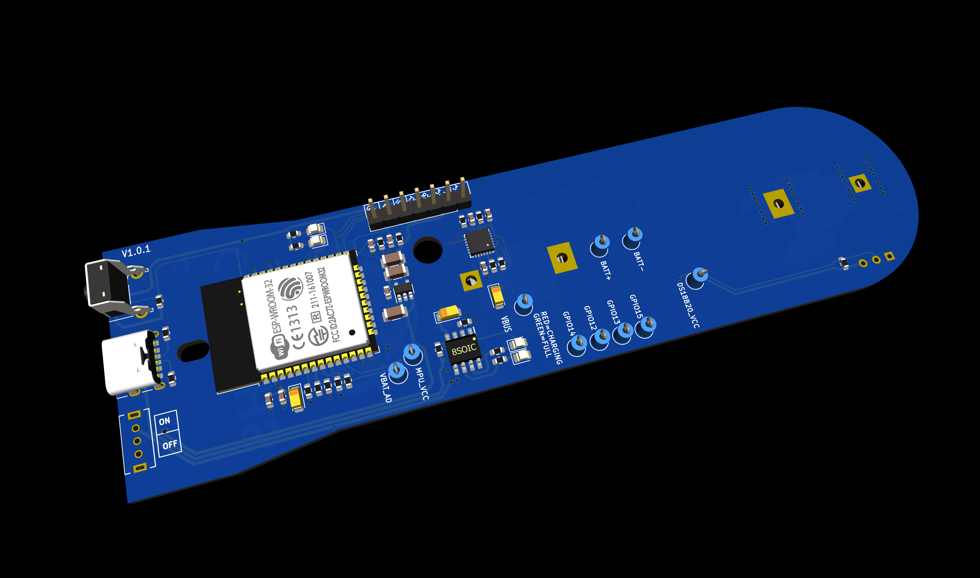
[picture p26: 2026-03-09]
hardware/images/PCB2 Top.png

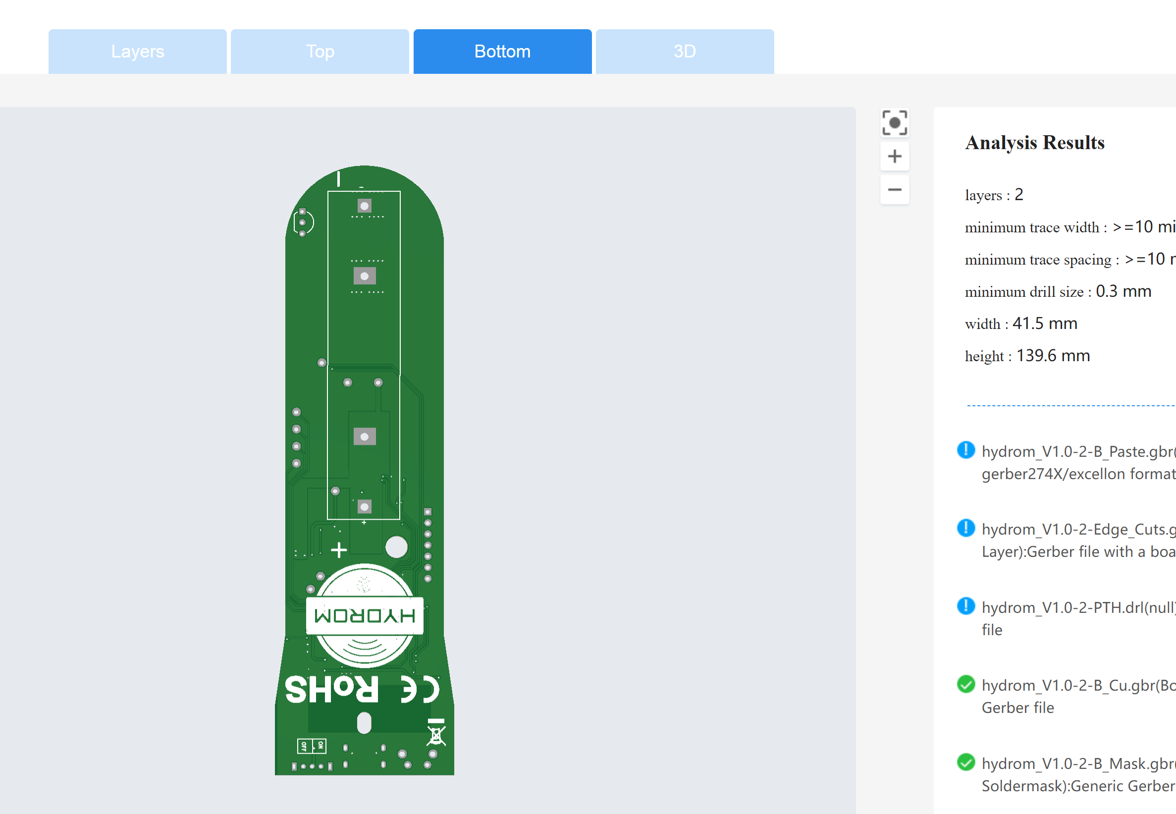
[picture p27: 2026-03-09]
hardware/images/JLCPCB_View BOT.png

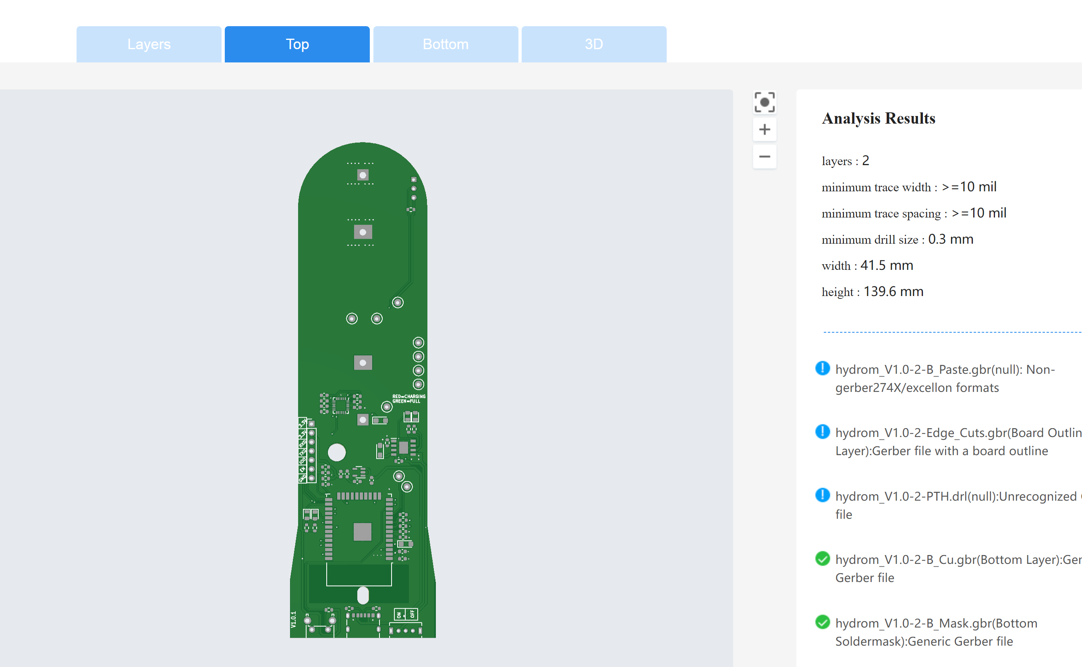
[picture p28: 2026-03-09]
hardware/images/JLCPCB_View TOP.png

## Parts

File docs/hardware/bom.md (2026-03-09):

---
description: >
  Bill of materials (BOM) listing all components required to build the Hydrom hardware.
---

# Bill of Materials

The full Bill of Materials (BOM) is available as an XLSX file in the repository:

📄 [`hardware/production/bom/BOM.xlsx`](https://github.com/TjGer22/Hydrom/raw/main/hardware/production/bom/BOM.xlsx)

The BOM includes reference designators, component values, footprints, LCSC/JLCPCB part numbers, and quantity per board.

## Sourcing

The BOM is optimised for ordering from **JLCPCB** with SMT assembly. Most components are available from the JLCPCB basic parts library, which significantly reduces assembly cost.

If you are self-sourcing components, equivalent parts from Mouser, DigiKey or LCSC can be substituted — check the datasheet for pin-compatible alternatives.

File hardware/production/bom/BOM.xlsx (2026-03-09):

Reference(s) | Qty | Value | Footprint | Mfr# | Manufacturer | Supplier
C1, C4, C9 | 3 | 10uF | Capacitor_Tantalum_SMD:CP_EIA-3216-18_Kemet-A | CA45-A010K106T | Hunan Xiangyee in S&T | LCSC
C2, C5, C10, C13, C15 | 5 | 0.1uF | Capacitor_SMD:C_0603_1608Metric | CC0603KRX7R9BB104 | Yageo | LCSC
C7 | 1 | 4.7uF | Capacitor_SMD:C_0603_1608Metric | CL10A475KQ8NNNC | Samsung Electro-Mechanics | LCSC
C8, C12, C16 | 3 | 47uF | Capacitor_SMD:C_1206_3216Metric | GRM188R60J476ME15D | Murata Electronics | LCSC
C11 | 1 | 10nF | Capacitor_SMD:C_0603_1608Metric | CC0603KRX7R9BB103 | Yageo | LCSC
C14 | 1 | 2.2nF | Capacitor_SMD:C_0603_1608Metric | 603B222K250NT | FH(Guangdong Fenghua Advanced Tech) | LCSC
D1, D3 | 2 | RED | LED_SMD:LED_0805_2012Metric | XL-2012SURC | XINGLIGHT | LCSC
D2, D4 | 2 | GREEN | LED_SMD:LED_0805_2012Metric | XL-2012SYGC | XINGLIGHT | LCSC
J1 | 1 | UJC-HP-3-SMT-TR | footprints:217175-0001 | UJC-HP-3-SMT-TR | CUI Devices | Mouser
P1 | 2 | CONN 2 | greencharge-footprints:MY-18650-02 | MY-18650-02 | MYOUNG | LCSC
Q3 | 1 | DS18B20+ | Package_TO_SOT_THT:TO-92_Inline_Wide | DS18B20+ | Maxim Integrated | LCSC
R1, R4, R7, R9, R17, R20, R21, R22 | 8 | 10k | Resistor_SMD:R_0603_1608Metric | 0603WAF1002T5E | UNI-ROYAL(Uniroyal Elec) | LCSC
R2, R3, R12, R13 | 4 | 1k | Resistor_SMD:R_0603_1608Metric | 0603WAF1001T5E | UNI-ROYAL(Uniroyal Elec) | LCSC
R5 | 1 | 1.2k | Resistor_SMD:R_0603_1608Metric | 0603WAF1201T5E | UNI-ROYAL(Uniroyal Elec) | LCSC
R6, R8, R14 | 3 | 4.7k | Resistor_SMD:R_0603_1608Metric | FRC0603J472 TS | FOJAN | LCSC
R10 | 1 | 0.1R | Resistor_SMD:R_0603_1608Metric | FRL0603JR100TS | FOJAN | LCSC
R15 | 1 | 47k | Resistor_SMD:R_0603_1608Metric | FRC0603J473 TS | FOJAN | LCSC
R16 | 1 | 91k | Resistor_SMD:R_0603_1608Metric | FRC0603J913 TS | FOJAN | LCSC
R18, R19 | 2 | 5.1k | Resistor_SMD:R_0603_1608Metric | FRC0603J512 TS | FOJAN | LCSC
S1 | 1 | slide-SPDT | iSpindel:Slide_Switch | SK12D07VG4NSPA | C&K | Mouser
SW1 | 1 | PTS645VL39-2 LFS | Button_Switch_THT:SW_Tactile_SPST_Angled_PTS645Vx39-2LFS | PTS645VL392LFS | C&K | LCSC
U1 | 1 | RT9080-33GJ5 | Package_TO_SOT_SMD:SOT-23-5 | TPRT9080-33GJ5 | TECH PUBLIC | LCSC
U2 | 1 | ESP32-WROOM-32E (8MB) | RF_Module:ESP32-WROOM-32 | ESP32-WROOM-32-N4 | Espressif Systems | LCSC
U3 | 1 | TP4056 | SamacSys_Parts:SOIC127P600X175-9N | TP4056 | UMW(Youtai Semiconductor Co., Ltd.) | LCSC
U4 | 1 | MPU-6050 | Sensor_Motion:InvenSense_QFN-24_4x4mm_P0.5mm | MPU-6050 | TDK InvenSense | LCSC
 |  |  |  |  |  | LCSC

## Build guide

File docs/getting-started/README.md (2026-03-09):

---
description: >
  Overview of the getting-started section for new Hydrom users.
---

# Getting Started with Hydrom

## Welcome to Hydrom

Hydrom is an intelligent, free-floating hydrometer that measures beer and wine fermentation density via Wi-Fi. Unlike traditional hydrometers, Hydrom continuously monitors gravity changes without disturbing your fermentation process, and automatically sends data to your smartphone or computer.

### What You'll Need

Before starting, gather the following:

| Item | Purpose |
|---|---|
| **Hydrom device** | The smart hydrometer |
| **USB-C cable + charger** | To charge the built-in battery |
| **Smartphone or computer** | To access the web interface and monitor fermentation |
| **Wi-Fi network** | For Hydrom to connect and transmit data |
| **Wi-Fi credentials** | Your network name (SSID) and password |

## Setup Checklist

Follow these 8 steps to get your Hydrom up and running:

| Step | Topic | Time | Difficulty |
|---|---|---|---|
| 1 | [Read Safety Warnings](warnings-read-before-use.md) | 5 min | Easy |
| 2 | [Disinfect Before Use](disinfect-before-use.md) | 10 min | Easy |
| 3 | [Charge the Battery](../services/charging-the-hydrom.md) | 2-3 hours | Easy |
| 4 | [Connect to Wi-Fi](../services/wifi-setup.md) | 5 min | Easy |
| 5 | [Access the Web Interface](../services/access-to-the-user-interface.md) | 2 min | Easy |
| 6 | [Calibrate the Device](../calibration/check-calibration.md) | 5-120 min | Medium |
| 7 | [Configure Settings](../configuration/changing-the-hydrom-name.md) | 5 min | Easy |
| 8 | [Connect Services](../services/connect_to_brewfather.md) | 5-10 min | Easy |

## Setup Steps in Detail

### 1. Read Safety Warnings
Before handling your Hydrom, please read the [Safety Warnings](warnings-read-before-use.md) to understand important precautions, especially regarding battery safety.

**Time required:** 5 minutes

### 2. Disinfect Before Use
It's important to sterilize your Hydrom before first use. Follow the [Disinfection Guide](disinfect-before-use.md) to ensure hygienic operation.

**Time required:** 10 minutes

### 3. Charge the Battery
Your Hydrom arrives with a depleted battery. Charge it fully using the included USB-C cable before first use.

**Time required:** 2-3 hours

### 4. Connect to Wi-Fi
Configure your Hydrom to join your home or brewery Wi-Fi network. The device creates its own temporary network during setup.

**Time required:** 5 minutes

### 5. Access the Web Interface
Once connected to Wi-Fi, access the Hydrom web interface from any browser to view live measurements and configure settings.

**Time required:** 2 minutes

### 6. Calibrate Your Device
Calibration ensures accurate measurements. Choose from three methods depending on your accuracy requirements and available time.

**Time required:** 5-120 minutes (depending on method)

### 7. Configure Settings
Enable optional features like temperature compensation and headstand detection to get the most out of your Hydrom.

**Time required:** 5 minutes

### 8. Connect Services
Integrate Hydrom with popular brewing services like Brewfather, BeerSmith, or Fermentrack to track fermentation alongside other data.

**Time required:** 5-10 minutes

## After Setup

Congratulations! Your Hydrom is now ready to monitor your fermentation.

### What You Can Do Now

- **Monitor fermentation in real-time** from your phone or computer
- **Track gravity changes** automatically without opening your fermenter
- **Receive notifications** when fermentation completes
- **Export data** to brewing software
- **Review fermentation history** and trends

### Recommended Next Steps

#### Connect Your Services
If you use brewing software or apps, connect Hydrom to sync data automatically:
- [Connect Services →](../services/connect_to_brewfather.md)

#### Adjust Your Settings
Fine-tune your Hydrom with optional features:
- [Device Settings →](../configuration/changing-the-hydrom-name.md)

#### Need Help?
If you encounter any issues:
- [Troubleshooting →](../troubleshooting/webui-unreachable.md)

## Typical Fermentation Workflow

1. **Brew day:** Pitch your yeast
2. **Day 1:** Place Hydrom in fermenter and enable Wi-Fi connection
3. **Days 2-7:** Monitor gravity drop in real-time
4. **When ready:** Check final gravity to confirm fermentation is complete
5. **Packaging:** Remove Hydrom, clean, and prepare for next batch

## Tips for Best Results

- **Keep Wi-Fi stable** — Position fermenter where Wi-Fi signal is strong
- **Full submersion** — Ensure Hydrom floats freely without touching walls or lid
- **Regular monitoring** — Check the web interface daily to track progress
- **Temperature stability** — Consistent fermentation temperature improves accuracy
- **Calibration first** — Calibrate before your first use for best accuracy

## Questions?

Refer to our [Troubleshooting Guide](../troubleshooting/webui-unreachable.md) or contact support at support@hydrom.io

---

**Ready to begin? Start here:** [Read Safety Warnings →](warnings-read-before-use.md)

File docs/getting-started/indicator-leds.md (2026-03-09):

---
description: >-
  The Hydrom has two different pairs of LEDs.One pair of LEDs shows the charging
  behavior, the other shows the status of the device.
---

# Indicator LEDs

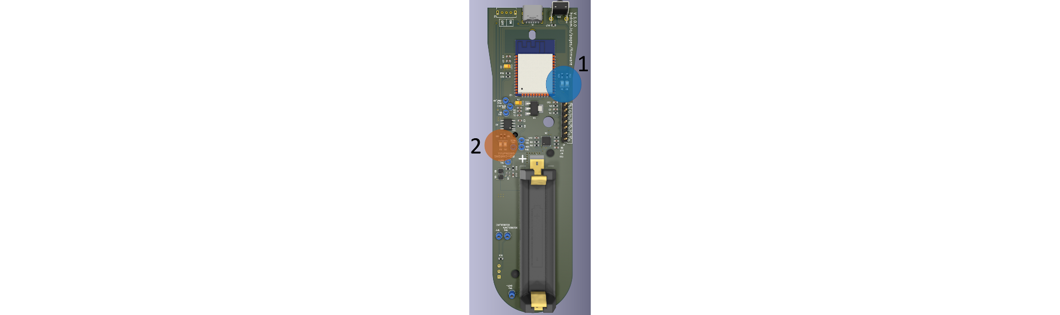
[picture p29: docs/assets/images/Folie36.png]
Position of LED pairs


## Status LED of the Hydrom Logic

The Status LED shows the current operating state. When the Hydrom is in configuration mode, the LED is green. If something has gone wrong, only the red LED is lit.

## Charging LED

The Charging LED indicates battery state. If the battery is fully charged, the green LED is on. When the battery is charging, the red LED is on.

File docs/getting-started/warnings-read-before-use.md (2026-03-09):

---
description: >
  Important safety and usage warnings to read before operating the Hydrom.
---

# Safety Warnings — Please Read Before Use

!!! danger "Battery Safety"
    The Hydrom contains a lithium-ion battery. Improper handling can cause fire, explosion, or chemical burns. Read and follow all warnings carefully.

## Important Safety Warnings

### 1. DO NOT Disassemble the Device

**Never** open or disassemble the Hydrom casing. The device is sealed for waterproofing and contains a lithium-ion battery that can be dangerous if exposed.

- Disassembly voids the warranty
- Opening the casing may damage the device
- Battery exposure creates fire/explosion hazards

### 2. DO NOT Damage the Battery

**Never** puncture, crush, bend, or damage the battery or casing. A damaged battery can catch fire or explode.

- Do not drop from height
- Do not apply excessive pressure
- Inspect the device regularly for dents or damage
- Do not use if the casing is cracked or leaking

### 3. DO NOT Overcharge or Use Improper Chargers

**Never** charge with a charger other than the provided USB-C cable and approved charger.

- Use only USB-C chargers rated 5V or higher
- Do not leave charging unattended for extended periods
- Disconnect when fully charged
- Do not charge in wet environments

### 4. DO NOT Expose to Extreme Temperatures

**Never** expose the device to temperatures below -10°C or above 60°C (14°F to 140°F).

- Do not leave in direct sunlight
- Do not place near heat sources
- Do not freeze the device
- Allow to acclimate to room temperature before use

### 5. DO NOT Submerge Fully Beyond Intended Depth

While Hydrom is water-resistant, it is designed for floating in fermentation vessels, not full submersion beyond normal operational depth.

- Do not push underwater or hold submerged
- Allow normal floating operation
- Do not use in high-pressure environments (deep water)
- Do not submerge the USB-C charging port

### 6. NEVER Ignore Warning Signs

**Stop using immediately if:**

- The device smells unusual or produces smoke
- The casing is hot to the touch
- The battery is swollen or deformed
- The device no longer charges properly
- There are visible cracks or leaks
- The device was dropped into water from height

If any of these occur, remove the device to a safe location away from flammable materials and contact support@hydrom.io immediately.

## Safe Usage Practices

- **Keep dry between uses** — Store in a dry location
- **Regular inspection** — Check the device weekly for damage
- **Clean appropriately** — Wipe with a damp cloth; avoid soaking before charging
- **Proper storage** — Store at room temperature in a dry place
- **Keep away from children** — Small parts and battery hazards
- **Respect the product** — Handle with care as you would electronics

## Emergency Procedures

**If battery catches fire:**
1. Do NOT attempt to extinguish with water
2. Evacuate the area immediately
3. Allow the fire to burn in open air or use a Class D fire extinguisher
4. Call emergency services (911 in US)

**If battery leaks:**
1. Do NOT touch the liquid
2. Wash affected skin with water immediately
3. Remove contaminated clothing
4. Seek medical attention if skin/eyes irritated
5. Properly dispose of the device at an e-waste recycling facility

## Warranty and Liability

Failure to follow these safety warnings:
- Voids your warranty
- May result in injury or property damage
- Releases the manufacturer from liability
- May be illegal in your jurisdiction

## Questions About Safety?

If you have questions about safe use, contact support@hydrom.io before using the device.

---

**By using the Hydrom, you acknowledge that you have read, understood, and agree to follow all safety warnings.**

**Next step:** [Disinfect Before Use →](disinfect-before-use.md)

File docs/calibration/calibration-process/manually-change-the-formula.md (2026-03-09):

---
description: >-
  An external calibration can be made and then the calculated formula can be
  entered via the user interface. Here is explained how.
---

# Manually change the formula

!!! tip
    To make this setting you must have access to the user interface. If this is not the case, see here how to do it:[access-to-the-user-interface.md](../../services/access-to-the-user-interface.md)

There are many ways to calculate the formula of the hydrometer. When a formula has been calculated, it can be entered under ("Calibration" --> "Custom Form") and saved with the button below.

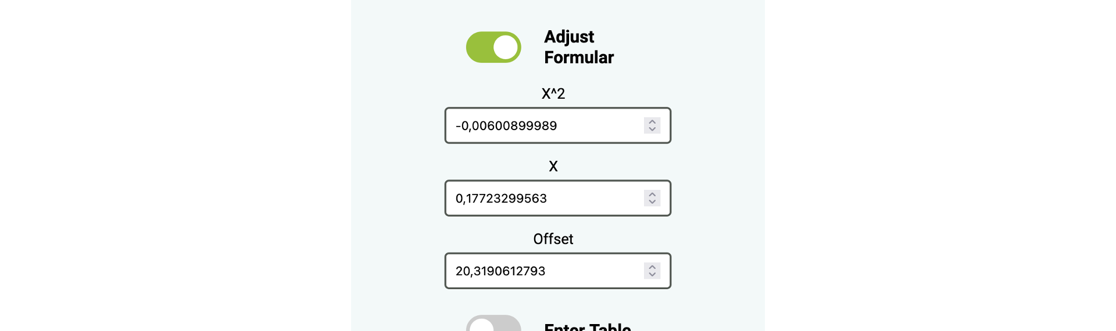
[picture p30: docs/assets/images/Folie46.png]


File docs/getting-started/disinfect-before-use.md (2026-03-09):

---
description: >-
    It is important to ensure that your Hydrom is thoroughly disinfected before use, it can help prevent the spread of germs and bacteria.
---

# Disinfect before use

To properly disinfect your Hydrom, start by thoroughly cleaning it with hot water and a mild detergent. Once it is clean, you can use a disinfectant solution or wipes to kill any remaining bacteria and germs. Be sure to follow the instructions on the disinfectant product you are using, as some may require you to let the solution sit for a certain amount of time before rinsing it off.

It is also a good idea to regularly disinfect your Hydrom, especially if it is used frequently or if it has come into contact with any potentially contaminated substances. By keeping your Hydrom clean and disinfected, you can help ensure that your food and beverages are safe to consume.

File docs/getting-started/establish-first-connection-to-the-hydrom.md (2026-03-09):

---
description: >
  Step-by-step guide to connecting to the Hydrom for the first time using its built-in WiFi access point.
---

# Establish first connection to the hydrom

1. [turn-on-the-hydrom.md](../services/turn-on-the-hydrom.md)
2. [wakeup-the-hydrom.md](../services/wakeup-the-hydrom.md)
3. [access-to-the-user-interface.md](../services/access-to-the-user-interface.md)

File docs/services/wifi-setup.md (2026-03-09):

---
description: >
  How to connect the Hydrom to your home WiFi network.
---

# Connect to existing WiFi

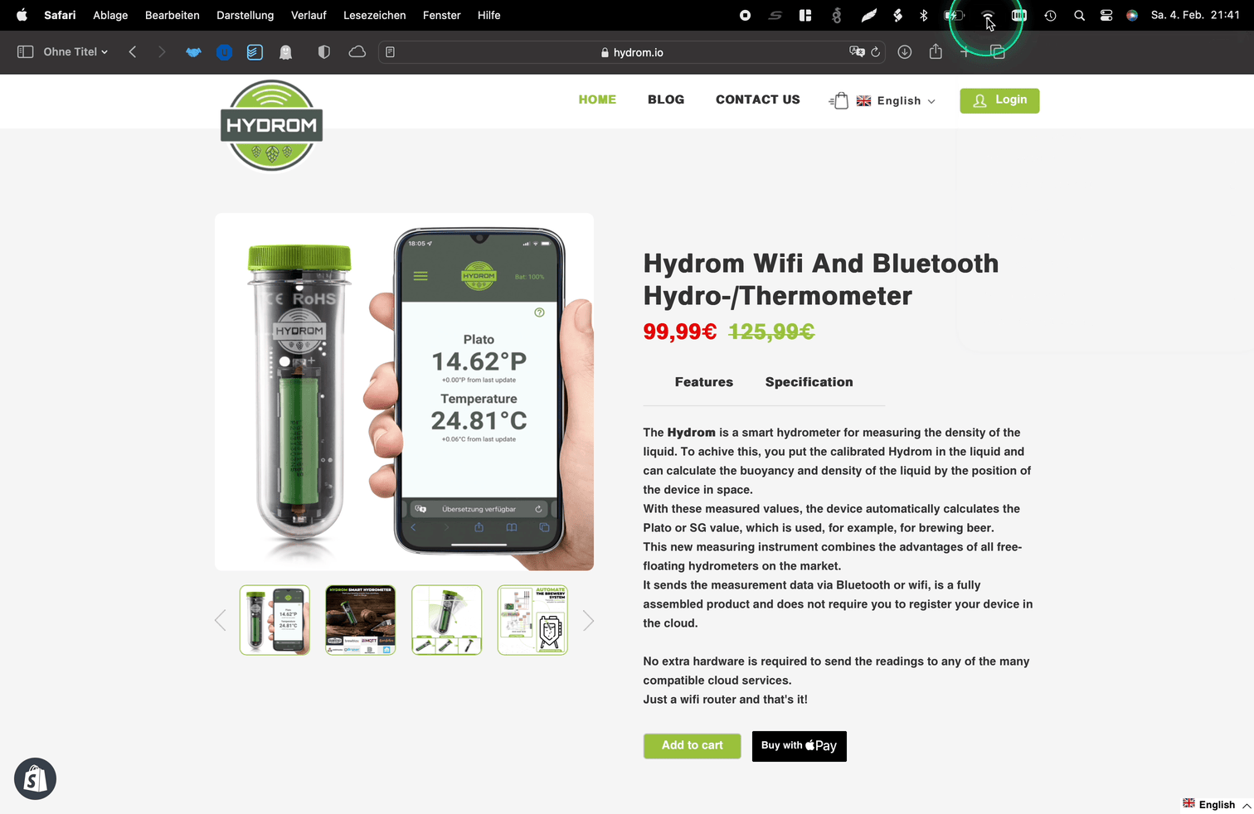
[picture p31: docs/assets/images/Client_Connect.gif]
<figure><figcaption></figcaption></figure>

!!! info
    Requirement that the Hydrom has for the WiFi:

    * 802.11 b/g/n
    * 802.11 n (2.4 GHz), up to 150 Mbps
    * WiFi name length: max 30 characters
    * WiFi password length: max 63 characters
    * Supported special characters for name and password:
    * a-zA-Z0-9!/#$&'()\*+a-zA-Z0-9!/#$
    * Security: WEP/WPA-TKIP/WPA2-CCMP

To change the network settings, open the navigation bar on the left side and select the "Wifi" option

## Connect Hydrom to a WiFi that already exists

To set up the Hydrom as a client in an existing network, enter the name of the existing network in the field under "SSID". This setting allows the device to connect to an existing WiFi.

There are services that rely on the Hydrom having access to the Internet. If the Hydrom connects to a WiFi that does not have Internet, only local services will be available.

After you have entered the desired settings, press "Save".

Here is an example of the settings for an existing WiFi:

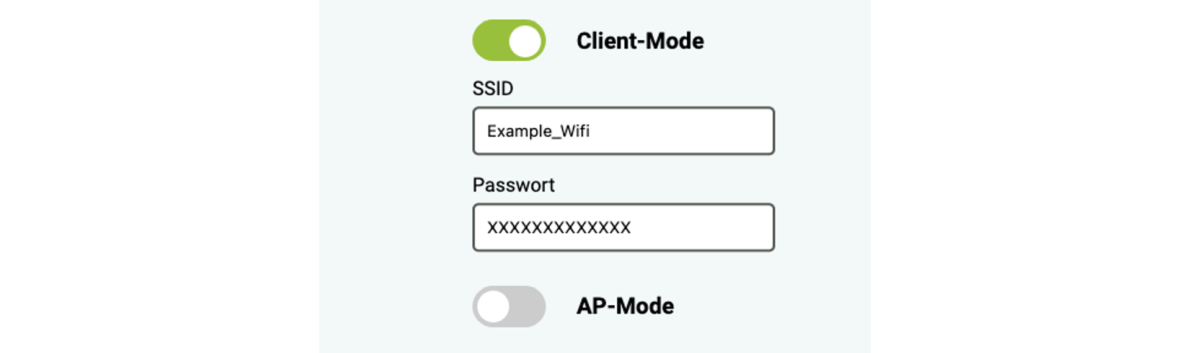
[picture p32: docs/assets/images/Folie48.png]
Example of setting "Hydrom in existing WiFi"


### Save Settings

Pressing the "save" button saves the settings.

You can check whether the saving was successful by looking at the settings file at http://hydrom001/settings.json/. to check if the save was successful. This file is the permanent memory of the Hydrom.

A second way to check the saving is to reload the page (all modern browsers offer this Feature). If the properties are then reloaded, the hydrom has accepted them, otherwise the old settings are reloaded.

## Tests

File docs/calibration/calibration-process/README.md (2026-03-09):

---
description: >
  Overview of the available Hydrom calibration methods.
---

# Calibration Process

This section describes the available methods to calibrate the Hydrom. For an overview of when calibration is needed and how to choose the right method, see [When and Why to Calibrate](../check-calibration.md).

## Available Methods

**[Quick Method – Plainwater](../../services/plainwater.md)**
Takes about 5 minutes. Only requires clean water at 20 °C. Suitable for most users.

**[Accurate Method – Reference](reference-method.md)**
Takes 1–2 hours. Requires a reference hydrometer and sugar or active wort. Produces the most accurate calibration curve across 7 density points.

**[Manual Formula Entry](manually-change-the-formula.md)**
If you have already calculated a polynomial calibration formula externally, you can enter it directly into the web UI.

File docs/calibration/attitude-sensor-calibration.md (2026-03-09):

---
description: >-
  It may happen that the Attitude Sensor loses its initial calibration. This is manifested
  by the measured angle deviating from reality (+- 30 degrees).
---

# Attitude Sensor Calibration

!!! tip
    **Prerequisite:**

    1. **Access to the user interface:** To make this setting, you must have access to the user interface. If this is not the case, look here to see how to do it: [access-to-the-user-interface.md](../services/access-to-the-user-interface.md)

## Preparing the Hydrom

### Step 1: Place the Hydrom on a horizontal surface.

Place the Hydrom on the table in such a way that it is completely level. The battery ensures that the Hydrom is correctly aligned.

!!! warning
    It is important that the ring on the Hydrom (photo to follow) does not rest on the table, as otherwise the Hydrom would have an additional angle of 2°, which could significantly distort the result.

### Step 2: Open the menu bar

To call up the menu bar, click on the three lines in the top left corner (see arrow). The menu bar will then open.

<figure><figcaption><p>Call up the menu bar by clicking on the three lines in the top left corner.</p></figcaption></figure>

### Step 3: Start the calibration

If you are connected to the Hydrom via the configuration WLAN, you can call up the following link: [`http://192.168.2.1/mpucalibration`](http://192.168.2.1/mpucalibration)

If you have connected directly to the Hydrom via your WLAN, you will need the IP address of your device. The page to be called up is then as follows: http://\<IP-Address>/mpucalibration

The LEDs will now flash.

### Step 4: Wait

The Hydrom will now measure the current position frequently and then determine an offset for the attitude sensor based on changes in the measured values. Once the LEDs stop flashing, the attitude sensor is calibrated.

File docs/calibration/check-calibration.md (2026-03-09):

---
description: >
  How to verify whether your Hydrom is correctly calibrated and when re-calibration is needed.
---

# Check and Calibrate Your Hydrom

## Why Calibration Matters

Calibration ensures your Hydrom provides accurate gravity measurements. Since every sensor is slightly different, calibration creates a reference point for your specific device. This is especially important because gravity measurements are critical for:

- Determining fermentation progress
- Predicting alcohol content
- Knowing when fermentation is complete
- Making consistent batches

## When to Calibrate

### First Use (Required)
Calibrate your Hydrom before monitoring your first fermentation.

### After Firmware Updates
If you update your Hydrom's firmware, recalibrate to ensure the new software has accurate reference points.

### If Readings Seem Off
If measurements don't match your refractometer or other hydrometers, recalibration may improve accuracy.

### Periodic Verification
Calibrate every 6-12 months of regular use to maintain accuracy.

## Quick Calibration Check

To verify your current calibration:

1. **Prepare 20°C water** — Use distilled or RO water at room temperature (20°C / 68°F)
2. **Place Hydrom in water** — Let it float naturally
3. **Wait a few minutes** — Allow the sensor to stabilize
4. **Check the reading** — Open the web interface and look at the gravity display
5. **Should read ~0°P** — If it shows approximately 0°Plato, your calibration is good

If the reading is significantly different from 0°P, proceed with a calibration method below.

## Calibration Methods

Choose the method that best fits your needs, accuracy requirements, and available time:

| Method | Time | Accuracy | What You Need | Best For |
|---|---|---|---|---|
| **Plain Water** | 5 minutes | Good | Distilled/RO water at 20°C | Quick verification |
| **Reference Solution** | 1-2 hours | Highest | Reference hydrometer, sugar, scale, thermometer | Maximum accuracy |
| **Manual/Formula** | Minutes | Depends on source | Pre-calculated calibration data from Hydrom support | Quick single-point calibration |

### Method 1: Plain Water Calibration (Quick)

**Best for:** Quick verification and basic accuracy

**Time required:** 5 minutes

**You'll need:**
- Distilled or RO water
- Thermometer (to verify 20°C)

**Steps:**

1. Heat or cool water to 20°C (68°F)
2. Pour water into a clean container (glass or plastic)
3. Place your Hydrom in the water and let it float naturally
4. Open the web interface and note the gravity reading
5. If it reads approximately 0°P, calibration is correct
6. If it reads higher or lower, contact support or use the reference method

### Method 2: Reference Solution Calibration (Most Accurate)

**Best for:** Highest accuracy and long-term consistency

**Time required:** 1-2 hours

**You'll need:**
- A reference hydrometer (must be calibrated itself)
- Sugar and scale (or pre-made reference solution)
- Distilled or RO water
- Thermometer
- Container (1-2 liters)
- Measuring cup

**Steps:**

1. **Prepare reference solutions:**
   - Solution 1 (0°P): Use distilled water only
   - Solution 2 (5°P): Dissolve sugar in water (approximately 50g sugar per liter, or verify with reference hydrometer)
   - Solution 3 (10°P): Double the sugar amount

2. **For each solution:**
   - Heat or cool to exactly 20°C
   - Measure the gravity with both the reference hydrometer and Hydrom
   - Record both readings

3. **Compare readings:**
   - Create a calibration curve from the three data points
   - If readings are off, note the offset or curve
   - Contact support@hydrom.io with your data for calibration adjustment

4. **Apply calibration:**
   - Support will provide a calibration coefficient
   - Access the calibration menu in the Hydrom web interface
   - Enter the coefficient to correct future measurements

### Method 3: Manual/Pre-Calculated Calibration

**Best for:** Single-point quick calibration

**Time required:** 5-15 minutes

**You'll need:**
- Pre-calculated calibration data (provided by Hydrom support)

**Steps:**

1. Contact Hydrom support with your device serial number
2. Receive your pre-calculated calibration values
3. Open the Hydrom web interface → Settings → Calibration
4. Enter the provided calibration offset or coefficient
5. Save and test with plain water

## Attitude Sensor Calibration

In addition to gravity sensor calibration, the Hydrom includes an attitude sensor (accelerometer/gyroscope) that must be calibrated for accurate orientation detection. This sensor powers the headstand detection feature.

**To calibrate the attitude sensor:**

1. Open Hydrom web interface → Settings → Calibration
2. Select "Calibrate Attitude Sensor"
3. Follow on-screen instructions (usually involves placing device in specific orientations)
4. Calibration typically takes 1-2 minutes

See also: [Activate Headstand Detection →](../configuration/activate-headstand-detection.md)

## Calibration Tips

- **Use clean containers** — Residue can affect readings
- **Allow stabilization time** — Wait 2-3 minutes after placing Hydrom in liquid
- **Consistent temperature** — Keep solutions at 20°C; temperature affects density
- **Document your results** — Keep records of calibrations for future reference
- **Trust the device** — Once calibrated, Hydrom is more reliable than repeated manual sampling

## If You're Unsure

Contact support@hydrom.io with:
- Your device serial number
- The readings you're seeing
- What reference readings show (if available)
- A photo of your web interface display

Our team will help you get accurate calibrations.

---

**Related guides:**
- [Setting Up Temperature Compensation →](../configuration/setting-up-the-temperature-compensation.md)
- [Getting Started Overview →](../getting-started/README.md)

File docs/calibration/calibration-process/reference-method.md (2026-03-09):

---
description: >-
  Reference method is a calibration method that is considered to be very
  accurate. The density of the current liquid is measured and communicated to
  the Hydrom. The hydrometer then calculates the calibr
---

# Reference method

!!! tip
    **Precondition:**

    1. User interface Access\
       To make this setting you must have access to the user interface. If this is not the case, see here how to do it:[access-to-the-user-interface.md](../../services/access-to-the-user-interface.md)
    2. Equipment needed:
       1. Density verification meter
       2. Reference liquid (can be beer in the brewing process)

## Step 3: Select Calibration

## Step 4: Perform the measurements.

### Session 1: 0° Brix/Plato solution

Create a 0° Brix solution by placing clear water (20°C) in a vessel.

Place the Hydrom in the vessel with the water.

When the instrument floats calmly, enter "0" in the Plato field and confirm by pressing "continue".

### Session 2: 20° Brix/Plato solution

Create a 20° Brix solution by mixing 1816g of the solution from Pass 1 with 454g of sugar.

Place the Hydrom in the vessel containing the mixture.

When it is floating calmly and the sugar has completely dissolved then enter "20" in the Plato field and confirm by pressing "continue".

### Session 3: 15° Brix/Plato solution

Create a 15° Brix solution by mixing 1668g of the solution from Pass 2 with 556g of water.

Place the hydrom in the vessel containing the mixture.

When it is floating calmly then enter "15" in the Plato field and confirm by pressing "continue".

### Session 4: 10° Brix/Plato Solution

Create a 10° Brix solution by mixing 1453g of the solution from Pass 3 with 727g of water.

Place the hydrom in the vessel containing the mixture.

When it is floating calmly then enter "10" in the Plato field and confirm by pressing "continue".

### Session 5: 7.5° Brix/Plato solution

Create a 7.5° Brix solution by mixing 1619g of the solution from Pass 4 with 540g of water.

Place the hydrom in the vessel containing the mixture.

When it is floating calmly then enter "7.5" in the Plato field and confirm by pressing "continue".

### Session 6: 5° Brix/Plato solution

Create a 5° Brix solution by mixing 1425g of the solution from Pass 5 with 713g of water.

Place the hydrom in the vessel containing the mixture.

When it is floating calmly then enter "5" in the Plato field and confirm by pressing "continue".

### Session 7: 2.5° Brix/Plato solution

Create a 2.5° Brix solution by mixing 1058g of the solution from Pass 6 with 1058g of water.

Place the hydrom in the vessel containing the mixture.

When it is floating calmly then enter "2.5" in the Plato field and confirm by pressing "continue".

## Step 5: Confirm the results

The formula has been calculated and the measured values are displayed in the table. After confirmation the new values are saved in the settings.

## The calibration is completed

| | | |
| --- | - | - |
| 1 | | |
| | 2 | |
| | | 3 |
| Nr. | | |
| Messung / Lösung | | |
| 1 2 3 4 5 6 7 | | |
| Brix soll | | |
| ° | | |
| 0,0 20,0 15,0 10,0 7,5 5,0 2,5 | | |
| Einwagen (g) | | |
| Zucker / Wasser vorherige Lsg | | |
| 0 2100 454 1816 1668 556 1453 727 1619 540 1425 713 1058 1058 | | |
| Volumen | | |
| ml | | |
| 2100 | | |
| 2100 | | |
| 2100 | | |
| 2100 | | |
| 2100 | | |
| 2100 | | |
| 2100 | | |
| Dichte Gewicht | | |
| bei 20°C g g/ml | | |
| 1 2100 1,081 2270 1,059 2224 1,038 2180 1,028 2159 1,018 2138 1,008 2117 | | |

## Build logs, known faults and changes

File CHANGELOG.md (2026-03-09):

# Changelog

All notable changes to this project will be documented in this file.

The format is based on [Keep a Changelog](https://keepachangelog.com/en/1.0.0/),
and this project adheres to [Semantic Versioning](https://semver.org/spec/v2.0.0.html).

---

## [Unreleased]

### Added
- Open-source release of firmware, hardware, and documentation

---

## [1.0.0] - 2023-01-01

### Added
- Initial firmware for ESP32 / Heltec WiFi LoRa 32 V2
- MPU6050 IMU-based angle measurement for specific gravity calculation
- DS18B20 temperature sensor support with compensation
- Calibration wizard (Plainwater and Reference methods)
- Web UI with OTA firmware update
- Bluetooth Low Energy (BLE iBeacon) data broadcast
- Wi-Fi client and access-point modes
- Cloud integrations: Brewfather, Brewer's Friend, Brewblox, Grainfather, MQTT, HTTP, Google Sheets, Ubidots, Telegram, BierBot Bricks, iRelay Display
- Alert / notification system
- Deep-sleep mode for extended battery life
- Backup and restore of device configuration
- Customisable language via Web UI
- KiCad PCB design (v1.0) with production-ready Gerbers and BOM

[Unreleased]: https://github.com/TjGer22/Hydrom/compare/v1.0.0...HEAD
[1.0.0]: https://github.com/TjGer22/Hydrom/releases/tag/v1.0.0

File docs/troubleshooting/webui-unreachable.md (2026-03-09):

---
description: >
  Troubleshooting guide for when the Hydrom web interface cannot be reached from a browser.
---

# Hydrom Web Interface Not Reachable

Can't access the Hydrom web interface? Follow this troubleshooting guide to get back online.

## Quick Diagnosis

### Step 1: Check Configuration Mode

Is your Hydrom in configuration mode (AP mode)?

**Look for:** A **green LED** on the device

- **Green LED = Yes** — The Hydrom is in configuration mode
- **Blue/red LED or no light = No** — The Hydrom is in normal mode

**If in configuration mode:**

1. Connect to the temporary Wi-Fi network named **hydrom_XXXXX** (where XXXXX is your device ID)
2. Open your browser and go to: **http://192.168.2.1**
3. You should see the Hydrom configuration interface
4. Complete the Wi-Fi setup if you haven't already

### Step 2: Are You on the Right Network?

If the Hydrom is NOT in configuration mode, verify you're connected to the correct network:

**To access the normal web interface:**

1. **Connect to your home/brewery Wi-Fi network** — The same network your Hydrom joined
2. Open your browser and enter the Hydrom's IP address in the address bar

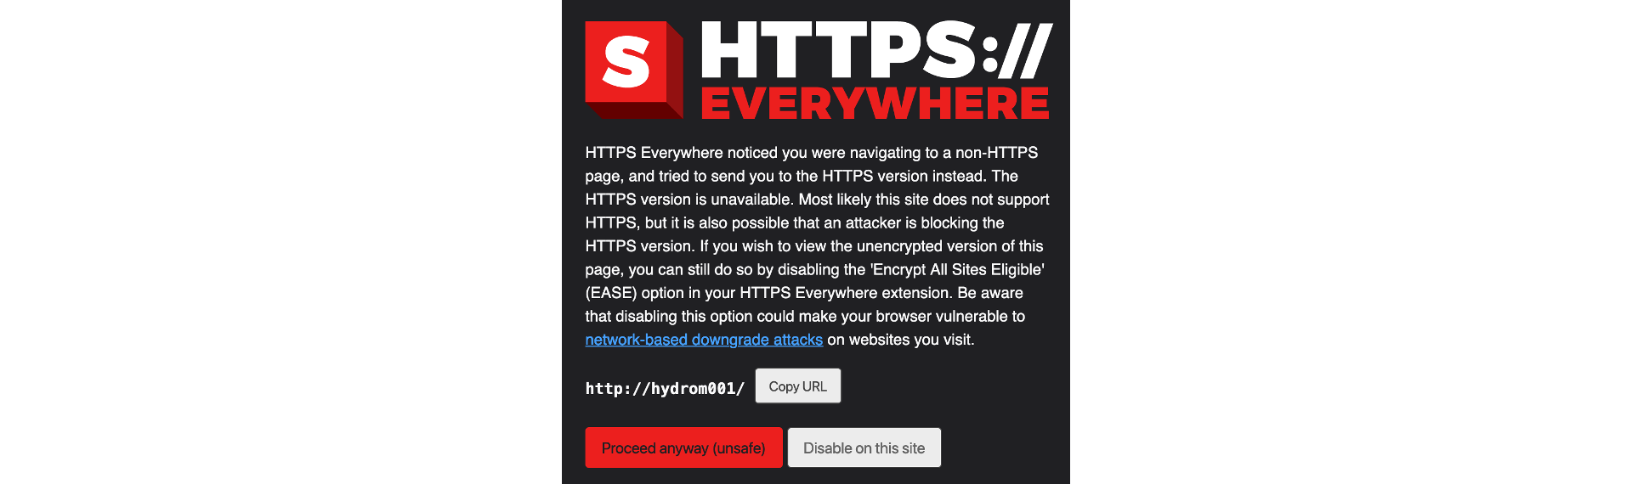
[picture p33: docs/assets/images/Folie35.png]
Network settings showing IP address


**Don't know the Hydrom's IP address?**

Look for it in your router's connected devices or network settings (typically shown in a green box on your router's admin interface).

### Step 3: Home Network Access

Once you know the Hydrom's IP address:

1. **On the same Wi-Fi network** as the Hydrom
2. Open a web browser (Chrome, Firefox, Safari, Edge, etc.)
3. Type the IP address in the address bar: **http://192.168.X.X**
4. Press Enter

You should see the Hydrom dashboard.

!!! info
    Always use **http://** not **https://** — Hydrom is accessed via unencrypted HTTP

### Step 4: Browser Shows "Not Secure"

If your browser displays a security warning like "Not Secure," "Your connection is not private," or shows a lock icon:

**This is normal** — Hydrom uses HTTP (not HTTPS) for the local web interface.

**To proceed:**

1. Click **Advanced** or **More details** (varies by browser)
2. Look for an option like **"Proceed anyway"** or **"Accept the risk and continue"**
3. Click it to access the interface

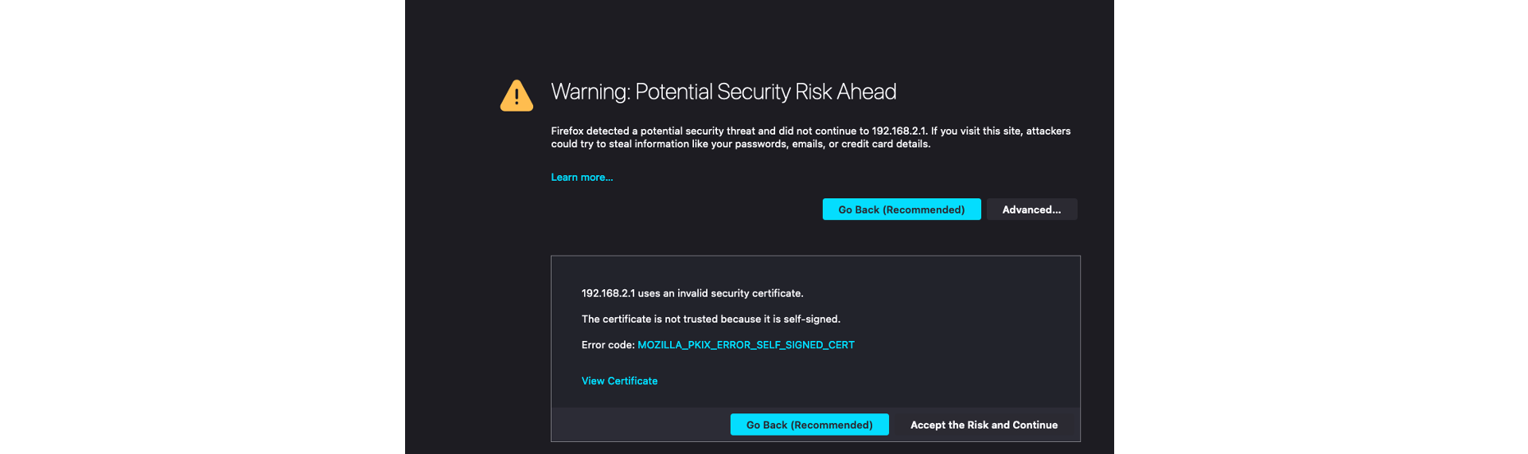
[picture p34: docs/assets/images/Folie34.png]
Proceed past browser warning


**Why is this secure?**
- Hydrom communicates only on your local Wi-Fi network
- No sensitive data passes through the internet
- This is standard for local network devices

## Still Can't Access?

If you've tried all steps above and still can't reach the web interface:

### Try a Soft Reset

1. Find the **reset button** on your Hydrom (small button, often recessed)
2. Press and hold for 3-5 seconds
3. Release and wait 30 seconds for the device to restart
4. Look for the green LED (configuration mode)
5. Try accessing via **http://192.168.2.1** again

### Check These Common Issues

**Is Wi-Fi working?**
- Other devices connected to the network?
- Can you access other network resources?

**Is the device powered?**
- Check the LED indicator (should show some light)
- Is the battery charged? Try charging via USB-C for 15 minutes and try again

**Firewall or network restrictions?**
- Some enterprise networks block device access
- Try connecting to a personal mobile hotspot to test
- Contact your network administrator

**Browser cache issues?**
- Clear your browser cache and cookies
- Try a different browser
- Try an incognito/private browsing window

## Contact Support

If none of these steps work:

**Email:** support@hydrom.io

**Include in your message:**
- Hydrom device serial number (on device or in documentation)
- Your IP address or network range (e.g., 192.168.1.X)
- LED color you're seeing (green/blue/red/none)
- What browser you're using
- Any error messages exactly as shown

Our support team will help you get back online quickly.

---

**Related guides:**
- [Wi-Fi Setup →](../services/wifi-setup.md)
- [Service Not Receiving Data →](service-no-data.md)

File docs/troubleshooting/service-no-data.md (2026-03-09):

---
description: >-
  You have taken the Hydrom into distribution and the service on the Internet
  does not receive any data? Then here are the steps to isolate the error.
---

# An Internet service does not receive any data

## General questions:

1. is the firmware up to date?
2. Does the Hydrom have a connection to the existing WLAN? The Hydrom can only send data if it is connected to a WLAN.
3. does the WLAN have a connection to the internet?\
   The Hydrom can only send data to an internet service if the WLAN is connected to the internet.
4. has the service been set up as described in the instructions?
5. was a test message sent after setting up the service? If the test message is not received, then the service is not set up correctly. Please check the settings of the service. If the test message arrives, then the service is set up correctly.
6. Has the Hydrom been put into deep sleep?
7. was the time waited for the Hydrom to wake up (interval)?

## Steps you can try out yourself:

1. Does the hydrom have a connection to the internet? The easiest way to check this is to enter http for the service, "google.com" as the server and "80" as the port. If the Hydrom has a connection to the Internet, the box behind the server should turn green.
2. Send a test message If the Hydrom has a connection to the internet and the service is set up correctly, then a test message should arrive.

## SUPPORT REQUEST

### To whom?

Mail to Support@hydrom.io

### With what content?

Answer to the general questions.

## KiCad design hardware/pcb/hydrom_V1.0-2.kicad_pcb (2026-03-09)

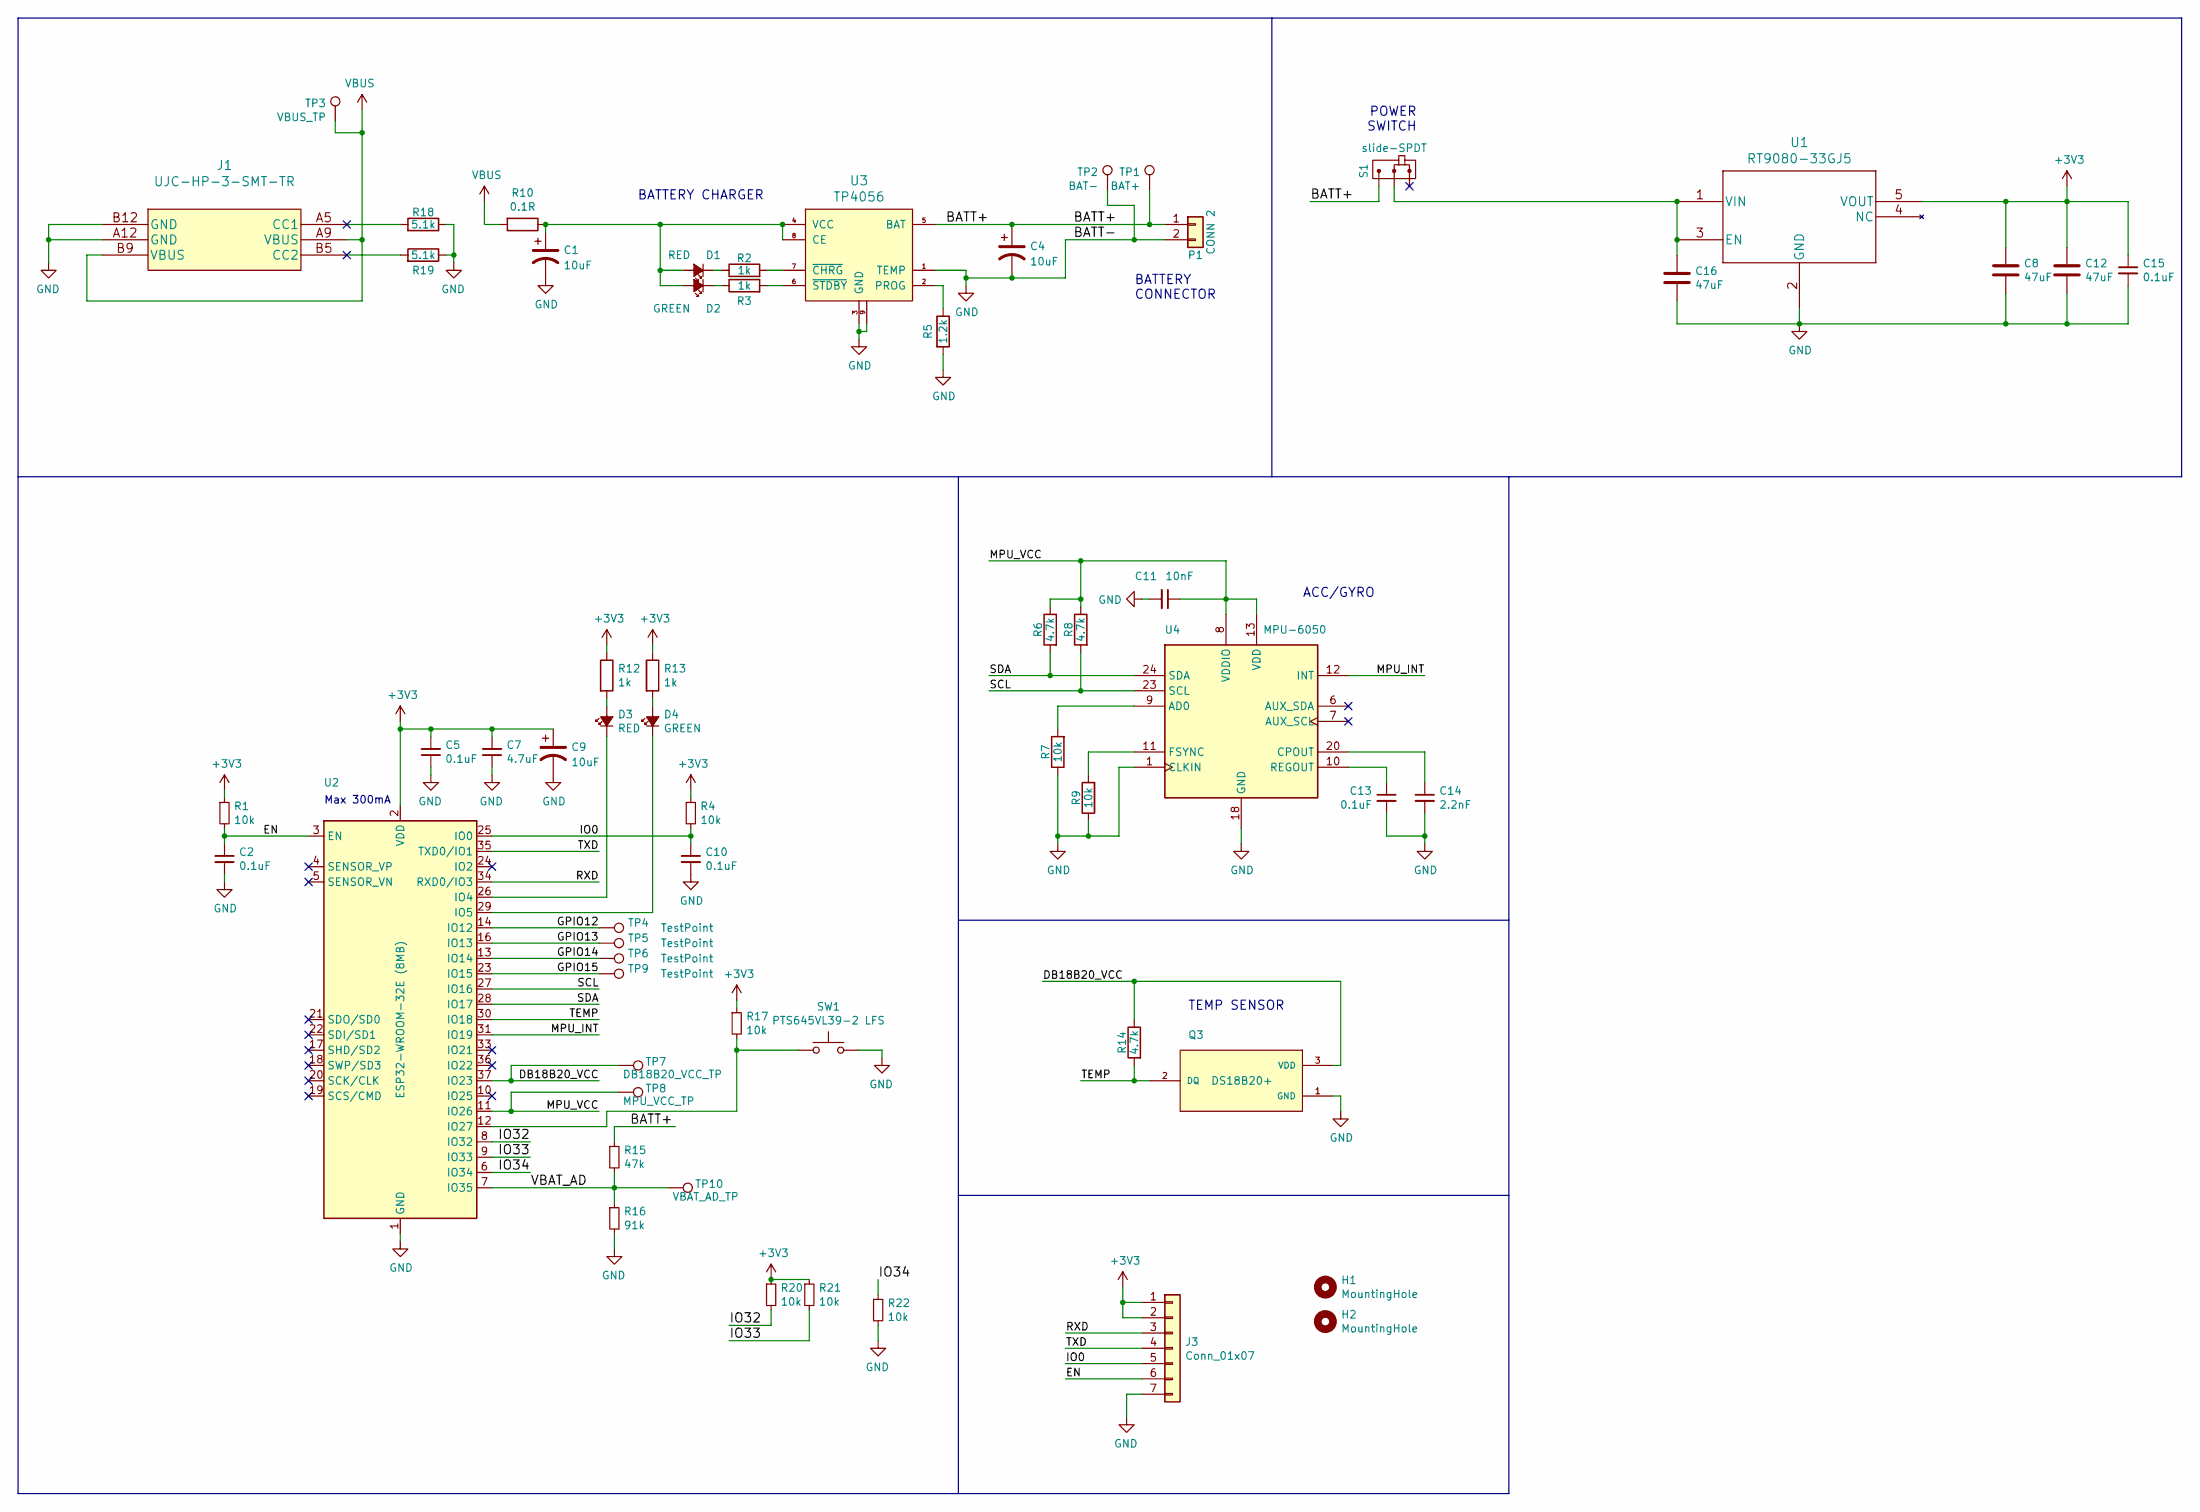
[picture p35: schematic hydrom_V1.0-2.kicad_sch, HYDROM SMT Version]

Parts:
C1, C4, C9: 10uF; CP_EIA-3216-18_Kemet-A; MPN 293D106X0010A2TE3; LCSC.com PN C2156473
C2, C5, C10, C13, C15: 0.1uF; C_0603_1608Metric; MPN CL10B104KB8WPNC; Digi-Key_PN 1276-1000-1-ND
C7: 4.7uF; C_0603_1608Metric; MPN CL10A475KP8NNNC; Digi-Key_PN 1276-2087-1-ND
C8, C12, C16: 47uF; C_0603_1608Metric; MPN C1206B476M016T; LCSC.com PN C607993
C11: 10nF; C_0603_1608Metric; MPN CL10B103KB8NNNL; Digi-Key_PN 445-1311-1-ND
C14: 2.2nF; C_0603_1608Metric; MPN CL10B222KB8NNNC; Digi-Key_PN 399-1085-1-ND
D1, D3: RED; LED_0805_2012Metric; MPN 150080RS75000; Digi-Key_PN 160-1427-1-ND
D2, D4: GREEN; LED_0805_2012Metric; MPN 150080GS75000; Digi-Key_PN 160-1423-1-ND
H1, H2: MountingHole; MountingHole_3.2mm_M3; MPN Does not apply; LCSC.com PN Does not apply
J1: UJC-HP-3-SMT-TR; 217175-0001; MPN UJC-HP-3-SMT-TR; Mouser PN 490-UJC-HP-3-SMT-TR
J3: Conn_01x07; PinHeader_1x07_P2.54mm_Vertical
P1: CONN 2; New_BAT_HOL
Q3: DS18B20+; TO-92_Inline_Wide; MPN DS18B20+T&R; Digi-Key_PN DS18B20+T&RCT-ND
R1, R4, R7, R9, R17, R20, R21, R22: 10k; R_0603_1608Metric; MPN SFR03EZPF1002; Digi-Key_PN 311-10.0KHRCT-ND
R2, R3, R12, R13: 1k; R_0603_1608Metric; MPN ESR03EZPF1001; Digi-Key_PN MCT0603-1.00K-CFCT-ND
R5: 1.2k; R_0603_1608Metric; MPN WR06X1201FTL; Digi-Key_PN MCT0603-1.20K-CFCT-ND
R6, R8, R14: 4.7k; R_0603_1608Metric; MPN RC0603FR-074K7L; Digi-Key_PN 311-4.70KHRCT-ND
R10: 0.1R; R_0603_1608Metric; MPN UCR03EVPFLR100; LCSC.com PN C880952
R15: 47k; R_0603_1608Metric; MPN AC0603FR-0747KL; Digi-Key_PN 311-10.0KHRCT-ND
R16: 91k; R_0603_1608Metric; MPN RC0603FR-0790K9L; Digi-Key_PN 311-10.0KHRCT-ND
R18, R19: 5.1k; R_0603_1608Metric; MPN RC0603FR-075K1L; Digi-Key_PN MCT0603-1.00K-CFCT-ND
S1: slide-SPDT; Slide_Switch; MPN SK12D07VG4NSPA; Mouser PN 611-SK12D07VG4NSPA
SW1: PTS645VL39-2 LFS; SW_Tactile_SPST_Angled_PTS645Vx39-2LFS; MPN PTS645VL39-2 LFS; Digi-Key_PN CKN9103-ND
TP1: BAT+; TestPoint_Loop_D1.80mm_Drill1.0mm_Beaded; MPN Does not apply; LCSC.com PN Does not apply
TP2: BAT-; TestPoint_Loop_D1.80mm_Drill1.0mm_Beaded; MPN Does not apply; LCSC.com PN Does not apply
TP3: VBUS_TP; TestPoint_Loop_D1.80mm_Drill1.0mm_Beaded; MPN Does not apply; LCSC.com PN Does not apply
TP4, TP5, TP6, TP9: TestPoint; TestPoint_Loop_D1.80mm_Drill1.0mm_Beaded; MPN Does not apply; LCSC.com PN Does not apply
TP7: DB18B20_VCC_TP; TestPoint_Loop_D1.80mm_Drill1.0mm_Beaded; MPN Does not apply; LCSC.com PN Does not apply
TP8: MPU_VCC_TP; TestPoint_Loop_D1.80mm_Drill1.0mm_Beaded; MPN Does not apply; LCSC.com PN Does not apply
TP10: VBAT_AD_TP; TestPoint_Loop_D1.80mm_Drill1.0mm_Beaded; MPN Does not apply; LCSC.com PN Does not apply
U1: RT9080-33GJ5; SOT-23-5; MPN TPRT9080-33GJ5; LCSC.com PN C2959864
U2: ESP32-WROOM-32E (8MB); ESP32-WROOM-32; MPN ESP32-WROOM-32E(M113EH2800PH3Q0); Digi-Key_PN 1965-ESP32-WROOM-32E(8MB)CT-ND
U3: TP4056; SOIC127P600X175-9N; MPN TP4056; LCSC.com PN C382139
U4: MPU-6050; InvenSense_QFN-24_4x4mm_P0.5mm; MPN MPU-6050; Digi-Key_PN 1428-1007-1-ND

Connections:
+3V3: C5.2, C7.2, C8.1, C9.1, C12.1, C15.1, J3.1, J3.2, R1.1, R4.1, R12.1, R13.1, R17.1, R20.1, R21.1, U1.5 (VOUT), U2.2 (VDD)
/BATT+: C4.1, P1.1, R15.1, S1.A, TP1.1, U3.5 (BAT)
/DB18B20_VCC: Q3.3 (VDD), R14.1, TP7.1, U2.37 (IO23)
/EN: C2.1, J3.6, R1.2, U2.3 (EN)
/GPIO12: TP4.1, U2.14 (IO12)
/GPIO13: TP5.1, U2.16 (IO13)
/GPIO14: TP6.1, U2.13 (IO14)
/GPIO15: TP9.1, U2.23 (IO15)
/IO0: C10.1, J3.5, R4.2, U2.25 (IO0)
/IO32: R20.2, U2.8 (IO32)
/IO33: R21.2, U2.9 (IO33)
/IO34: R22.1, U2.6 (IO34)
/MPU_INT: U2.31 (IO19), U4.12 (INT)
/MPU_VCC: C11.1, R6.1, R8.1, TP8.1, U2.11 (IO26), U4.8 (VDDIO), U4.13 (VDD)
/RXD: J3.3, U2.34 (RXD0/IO3)
/SCL: R8.2, U2.27 (IO16), U4.23 (SCL)
/SDA: R6.2, U2.28 (IO17), U4.24 (SDA)
/TEMP: Q3.2 (DQ), R14.2, U2.30 (IO18)
/TXD: J3.4, U2.35 (TXD0/IO1)
/VBAT_AD: R15.2, R16.1, TP10.1, U2.7 (IO35)
GND: C1.2, C2.2, C4.2, C5.1, C7.1, C8.2, C9.2, C10.2, C11.2, C12.2, C13.2, C14.2, C15.2, C16.2, J1.A12 (GND), J1.B12 (GND), J3.7, P1.2, Q3.1 (GND), R5.2, R7.1, R9.1, R16.2, R18.1, R19.1, R22.2, SW1.2, TP2.1, U1.2 (GND), U2.1 (GND), U2.15 (GND), U2.38 (GND), U2.39 (GND), U3.1 (TEMP), U3.3 (GND), U3.9, U4.1 (CLKIN), U4.18 (GND)
unnamed: C1.1, D1.2 (A), D2.2 (A), R10.1, U3.4 (VCC), U3.8 (CE)
unnamed: C13.1, U4.10 (REGOUT)
unnamed: C14.1, U4.20 (CPOUT)
unnamed: C16.1, S1.COM, U1.1 (VIN), U1.3 (EN)
unnamed: D1.1 (K), R2.1
unnamed: D2.1 (K), R3.1
unnamed: D3.1 (K), U2.26 (IO4)
unnamed: D3.2 (A), R12.2
unnamed: D4.1 (K), U2.29 (IO5)
unnamed: D4.2 (A), R13.2
unnamed: R2.2, U3.7 (~CHRG)
unnamed: R3.2, U3.6 (~STDBY)
unnamed: R5.1, U3.2 (PROG)
unnamed: R7.2, U4.9 (AD0)
unnamed: R9.2, U4.11 (FSYNC)
unnamed: R17.2, SW1.1, U2.12 (IO27)
VBUS: J1.A9 (VBUS), J1.B9 (VBUS), R10.2, TP3.1

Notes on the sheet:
BATTERY CONNECTOR
Max 300mA
POWER SWITCH
ACC/GYRO
TEMP SENSOR
BATTERY CHARGER

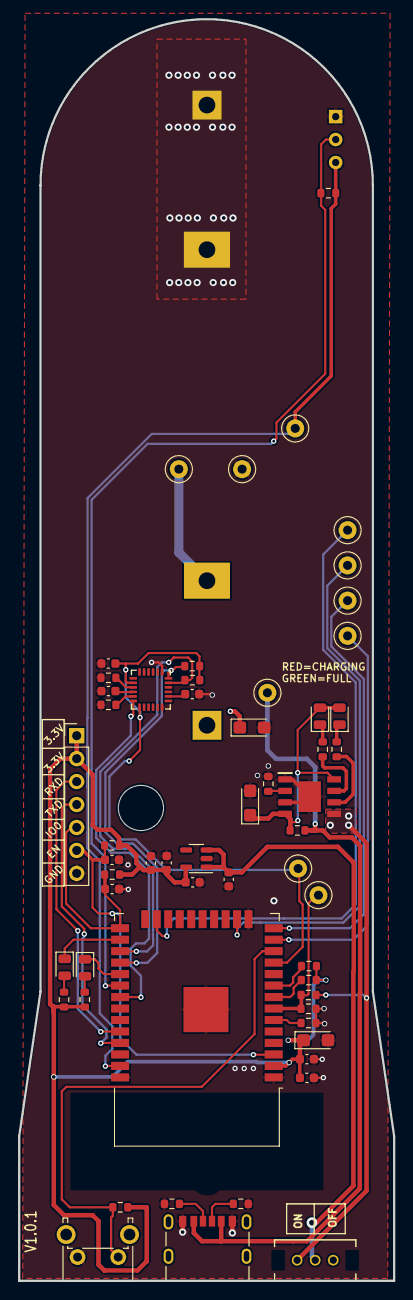
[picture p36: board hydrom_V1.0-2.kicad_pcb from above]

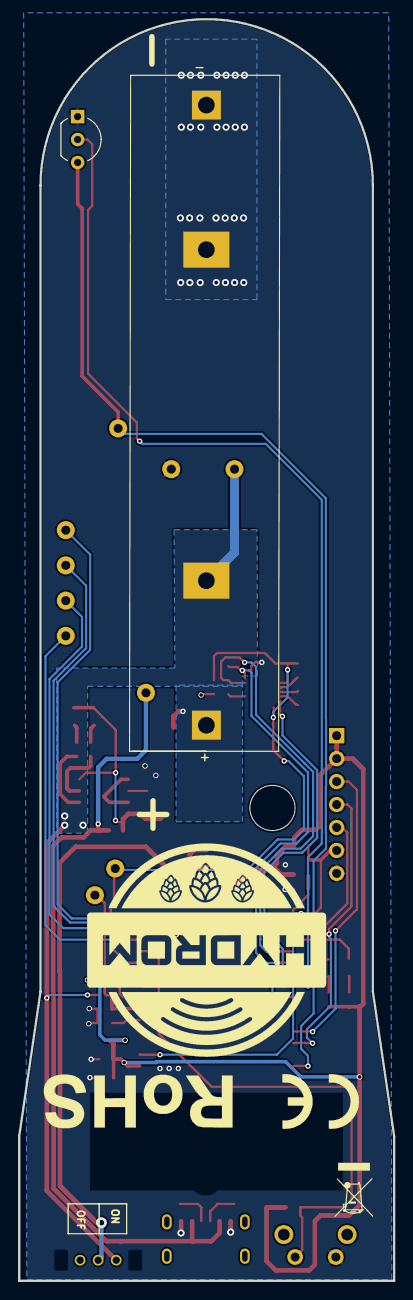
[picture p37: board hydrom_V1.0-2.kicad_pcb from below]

Board: 2 copper layers, 41.5 x 139.6 mm, 60 parts (2 on the bottom side), 38 nets.

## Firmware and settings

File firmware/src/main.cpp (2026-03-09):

/**
 * @file main.cpp
 * @author TjGer22
 * @brief Hydrom firmware entry point.
 * @date 2026
 *
 * @details
 * Initialises all hardware subsystems (sensors, network, BLE, web server)
 * and runs the main control loop. Deep-sleep handling and OTA updates
 * are also coordinated from this module.
 *
 * SPDX-License-Identifier: GPL-3.0-or-later
 */

#include <Arduino.h>
#include <EEPROM.h>
#include <WiFi.h>
#include <esp_sleep.h>
#include <soc/rtc.h>

#include "ArduAutoUpdater.h"
#include "BLESender.h"
#include "Calibration_MPU.h"
#include "DeviceManager.h"
#include "Globals.h"
#include "HydromConfiguration.h"
#include "NetworkManager.h"
#include "SensorManager.h"
#include "ServiceManager.h"
#include "Util.h"
#include "WebManager.h"

extern "C" {
#include <esp_clk.h>
}

/**
 * Local variables
 */
boolean Shutdown_declared;
boolean Task_Main_is_active;
boolean Task_Webserver_is_active;
boolean Reset_Wifi = false;

BLESender bt;
uint32_t l_DeepSleep_time;
boolean l_once = true;
long last_Release = 0;
SensorManager sensormanager_CPU0;
ServiceManager service;
/**
 * @brief add Threads
 *
 */
TaskHandle_t mainHnd;
TaskHandle_t Webserver_loopHnd;

/**
 * Local function defs
 */
void main_loop(void * parameter);
void Webserver_loop(void * parameter);
String CreateMessage(void);
void ResetButton_Pinstate_changed();
void Gracefull_Shutdown();
void manage_BLE_Delay();
boolean CheckWifiRequired();
boolean DeviceIsDeactivated();
void publish_Data_to_Services();
boolean Start_Network(int Mode);
void CheckDeviceEndlessSleep();
void sendBLE();
void readSensorsandsavethem(SensorManager * l_sensormanager);
void Wait_forever();
void Set_Fault_LED_Signal();

/**
 * @brief Arduino setup function — runs once at power-on or after deep-sleep wakeup.
 *
 * Initialises serial output, hardware pins, wake-up cause, configuration,
 * sensors, network and — depending on the wake-up reason — either publishes
 * data and sleeps again or starts the web-server tasks.
 */
void setup() {
    last_Release = millis();
    // Initialize the Serial Debug output
    Serial.begin(115200);
    Shutdown_declared        = false;
    Task_Main_is_active      = false;
    Task_Webserver_is_active = false;

    Device.setType();
    Device.prepareIO();

    /**
     * Here you have to take care that the correct input is used.
        The option "ext0 wake up source" uses the GPIOs of the RTC to wake up. So the RTC periphery will stay on during deep sleep if this wake up source is requested.
     *
     */
    Device.EnableWakeUp();

    attachInterrupt(digitalPinToInterrupt(27), ResetButton_Pinstate_changed, CHANGE);

    // print wake up cause
    Device.WakupCausePrint();

    // Hier wird überprüft ob das Hydrom ggf. resettet werden muss.
    if(Hydrom.WokeupReason == BUTTON) {
        Device.ConstantRED();
        Device.ConstantGREEN();
        // here we check if the button was pressed for more than 5 seconds
        if(Device.get_ResetButton_state()) {
            Print_Info(1, 1, "Obviously the reset button is still pressed. If the button is still not released in 7 seconds, the hydrom is reset.");
            int Resetbutton_Pressed_Time = 0;
            while(Device.get_ResetButton_state()) {
                // here we check if the button was pressed for more than 3 seconds
                if(Resetbutton_Pressed_Time >= BUTTON_PRESS_RESET_WIFI_SECONDS) {
                    Print_Info(1, 1, "Resetbutton was pressed 3sec.");
                    Reset_Wifi = true;
                }
                // If the button is still not released in 7 seconds, the hydrom is reset.
                if(Resetbutton_Pressed_Time >= BUTTON_PRESS_FACTORY_RESET_SECONDS) {
                    Device.ConstantGREEN();
                    config.factoryReset();
                }
                delay(500);
                Resetbutton_Pressed_Time++;
                Print_Info(1, 1, "+500sec.");
                Device.LED_FlipFlop();
            }
        } else {
            Print_Info(1, 1, "The Button is not pressed anymore");
            digitalWrite(DEF_LED_RED_PIN, HIGH);
            digitalWrite(DEF_LED_GREEN_PIN, HIGH);
        }
    } else {
        Print_Info(1, 1, "Button was not the Wakeup reason");
    }

    if(config.checkExistence(DEF_FILE_SETTINGS)) {
        Print_Info(1, 1, "OLD Settings found.");
        config.cleanup();
    }
    Print_Info(1, 1, "Entering Phase 1: Load Configuration");
    if(config.loadFS()) {    // Initialize File system, load default configuration
        Device.setType();
        if(Hydrom.WokeupReason == BUTTON) {
            Device.ConstantGREEN();
            Print_Info(2, 2, "Hydrom was started by Reset Button");
            if(Reset_Wifi) {
                Print_Info(2, 2, "Wifi Settings were resetted");
                StringCopyConst(Hydrom.name, DEF_HYDROM_NAME);
                StringCopyConst(Wifi.server_password, DEF_WIFI_SERVER_PASSWORD);
                StringCopyConst(Wifi.client_ssid, DEF_WIFI_CLIENT_SSID);
                StringCopyConst(Wifi.client_password, DEF_WIFI_CLIENT_PASSWORD);
                Wifi.mode  = DEF_WIFI_MODE;
                Reset_Wifi = false;
            }
        } else {
            Print_Info(2, 2, "Hydrom was not started by Button");
        }
    }
    if(strcmp(Hydrom.name, DEF_HYDROM_NAME) == 0) {
        Print_Info(6, Hydrom.current_Log_Level, "The variable " + String(Hydrom.name) + " is equal to the default " + String(DEF_HYDROM_NAME) + " therefore the new SSID is regenerated");
        StringCopyConst(Hydrom.name, config.generateSSID(Wifi.MacAdress).c_str());
    } else {
        Print_Info(6, Hydrom.current_Log_Level, "The variable " + String(Hydrom.name) + " is different to the default " + String(DEF_HYDROM_NAME) + " therefore the SSID is the same");
    }

    /**
     * @brief This part is executed only once at the beginning, shortly after flashing.

     *
     */
    if(Hydrom.accelOffset[0] == DEF_DEVICE_ACCELOFFSETX && Hydrom.accelOffset[1] == DEF_DEVICE_ACCELOFFSETY && Hydrom.accelOffset[2] == DEF_DEVICE_ACCELOFFSETZ) {
        if(!net.begin(false, 1, "Hydrom001", "Bonorum", DEF_WIFI_CLIENT_PASSWORD, "Hydrom001", "", DEF_IP, DEF_GATEWAY, DEF_SUBNET, 4)) {
            Set_Fault_LED_Signal();
            Print_Error("Leider konnte keine Verbindung mit dem WLAN hergestellt werden.");
            Wait_forever();
        }

        Device.setDS18B20state(HIGH);
        Device.setREDLEDstate(true);
        Device.setGREENLEDstate(false);

        sensormanager.setBatteryPin(DEF_BATTERY_PIN);

        float l_voltage     = sensormanager.getBatteryVoltage(DEF_BatteryScaleFactor);
        float l_temperature = sensormanager.getTemperature(DEF_DS18B20_DATA_PIN, DEF_DS18B20_VCC_PIN, 3);

        if(l_voltage <= BATTERY_CRITICAL_VOLTAGE && l_voltage >= BATTERY_MIN_VOLTAGE) {
            Set_Fault_LED_Signal();
            Print_Error("The Battery is with " + String(l_voltage) + "V too low maybe there is something wrong with the battery or the battery is empty.");
            Wait_forever();
        }
        if(l_temperature <= MIN_STARTUP_TEMPERATURE) {
            Set_Fault_LED_Signal();
            Print_Error("The Temperature is with " + String(l_temperature, 3) + "°C too low maybe there is something wrong with the Sensor");
            Wait_forever();
        }
        if(l_temperature >= MAX_STARTUP_TEMPERATURE) {
            Set_Fault_LED_Signal();
            Print_Error("The Temperature is with " + String(l_temperature, 3) + "°C too High maybe there is something wrong with the Sensor");
            Wait_forever();
        }

        Hydrom.MPU_is_Calibrated = false;
        Print_Info(6, Hydrom.current_Log_Level, "Hydrom Accel Ofset: " + String(Hydrom.accelOffset[0]));
        calibrator_mpu.start(DEF_SDA_PIN, DEF_SCL_PIN, DEF_MPU_SET_CLOCK);    // Start the calibration of the MPU

        if(!config.saveFS_Offsets()) {
            Print_Error("Something went wrong while writing the Offsets to the file system.");
            Set_Fault_LED_Signal();
            Wait_forever();
        }
        if(!config.saveFS_Settings()) {
            Print_Error("Something went wrong while writing the settings to the file system.");
            Set_Fault_LED_Signal();
            Wait_forever();
        }
        Device.setGREENLEDstate(true);
        Device.setREDLEDstate(true);

        Wait_forever();
    }

    if(Hydrom.WokeupReason != BUTTON && Hydrom.WokeupReason != TIMER) {
        Device.SetLEDOFF();
        Print_Info(1, 1, "Hydrom took off for an unexplained reason, so is put to sleep.");
        l_DeepSleep_time = calculateDeepSleepSeconds(DeepSleep.hours, DeepSleep.minutes, DeepSleep.seconds);
        Print_Info(1, 1, "Entering Phase 0.1: sleep " + String(l_DeepSleep_time) + "s");
        // sleep
        Print_Info(2, 2, "Start gracefull Shutdown");
        Gracefull_Shutdown();
        Device.SleepDeep(l_DeepSleep_time);
    }
    if(Hydrom.Landingpage != 3)
        Hydrom.Landingpage = 7;
    Print_Info(1, Hydrom.current_Log_Level, "Entering Phase 2: Initialize Sensors,Wifi,Bt");
    // Initialize sensors

    Device.setDS18B20state(HIGH);
    Device.setMPUstate(HIGH);
    sensormanager.setCurrentLogLevel(Hydrom.current_Log_Level);
    sensormanager.begin(DEF_DS18B20_DATA_PIN, Hydrom.gyroOffset, Hydrom.accelOffset, DEF_MPU_Interrupt_PIN, DEF_MPU_VCC_PIN, DEF_MPU_SET_CLOCK, DEF_SDA_PIN, DEF_SCL_PIN, true, DEF_DS18B20_VCC_PIN, configSensor.Period_gravity, DEF_BATTERY_PIN, configSensor.Period_temperature, configSensor.Period_batteryVoltage, configSensor.TemperatureCompensation_Factor, configSensor.LookupTable, configSensor.Enable_TemperatureCompensation, Hydrom.Coefficients, DEF_BatteryScaleFactor);
    // Only if the Hydrom was woken up by a timer, then Bluetooth will be activated.
    if(Bluetooth.Enabled) {
        if(Hydrom.WokeupReason == TIMER) {
            Print_Info(5, Hydrom.current_Log_Level, "Start Bluetooth");
            bt.begin(Bluetooth.BLETransPower);
            Print_Info(1, Hydrom.current_Log_Level, "Enter Phase 3: Read Sensors BLE Edition Timer");
            readSensorsandsavethem(&sensormanager);

            Print_Info(5, Hydrom.current_Log_Level, "Measurement_Values: " + String(configSensor.specific_gravity) + "SG; Temperature: " + String(sensormanager.get_converted_temperature(1)) + "F, " + String(configSensor.temperature) + "C");
            bt.send_data(Bluetooth.UUID_ID, configSensor.specific_gravity, sensormanager.get_converted_temperature(1));
            bt.stop();
        } else {
            Print_Info(5, Hydrom.current_Log_Level, "Bluetooth is activated but TIMER was noch the Wakeup Reason, therefore BLE was not started");
            Print_Info(1, Hydrom.current_Log_Level, "Enter Phase 3: Read Sensors BLE Edition Button");
            if(Hydrom.WokeupReason != BUTTON) {
                readSensorsandsavethem(&sensormanager);
                CheckDeviceEndlessSleep();
            }
        }
    } else {
        Print_Info(6, Hydrom.current_Log_Level, "Bluetooth is not activated, therefore BLE was not started");
        Print_Info(1, Hydrom.current_Log_Level, "Enter Phase 3: Read Sensors BLE Free Edition");
        if(Hydrom.WokeupReason != BUTTON) {
            readSensorsandsavethem(&sensormanager);
            CheckDeviceEndlessSleep();
        }
    }

    int err = 0;

    CheckDeviceEndlessSleep();

    if(CheckWifiRequired() && !DeviceIsDeactivated()) {
        if(Hydrom.WokeupReason == TIMER)
            if(!Start_Network(MODE_CLIENT))
                err++;

        if(Hydrom.WokeupReason == BUTTON) {
            if(Wifi.mode == MODE_SERVER_CLIENT) {
                if(!Start_Network(MODE_SERVER_CLIENT)) {
                    if(!Start_Network(MODE_SERVER)) {
                        err = 1;
                    } else {
                        err = 0;
                    }
                }
            } else {
                if(!Start_Network(MODE_SERVER))
                    err++;
            }
        }

        if(err != 0) {
            Device.ConstantRED();
            delay(1000);
            Device.SetLEDOFF();
            l_DeepSleep_time = calculateDeepSleepSeconds(DeepSleep.hours, DeepSleep.minutes, DeepSleep.seconds);
            Print_Info(2, Hydrom.current_Log_Level, "Caused by the unreachable Wifi the Hydrom is sleeping now");
            Gracefull_Shutdown();
            Device.SleepDeep(l_DeepSleep_time);
        }
    } else {
        Device.SetLEDOFF();
        l_DeepSleep_time = calculateDeepSleepSeconds(DeepSleep.hours, DeepSleep.minutes, DeepSleep.seconds);
        Print_Info(1, Hydrom.current_Log_Level, "Enter Phase 2.1: sleep " + String(l_DeepSleep_time) + "s");
        // sleep
        Print_Info(2, Hydrom.current_Log_Level, "Start gracefull Shutdown");
        Gracefull_Shutdown();
        Device.SleepDeep(l_DeepSleep_time);
    }

    if(Hydrom.WokeupReason == BUTTON) {
        Print_Info(5, Hydrom.current_Log_Level, "Webserver will be started");

        if(xTaskCreatePinnedToCore(main_loop, "CPU_0", 8000, NULL, 1, &mainHnd, 0)) {
            Print_Info(2, 2, " Thread 0 was created");
        } else {
            Print_Error("Thread 0 could not be created");
            Device.ConstantRED();
        }

        if(xTaskCreatePinnedToCore(Webserver_loop, "CPU_1", 8000, NULL, 1, &Webserver_loopHnd, 1)) {
            Print_Info(2, 2, " Thread 1 was created");
        } else {
            Print_Error("Thread 1 could not be created");
        }
        Device.ConstantREDGREEN();

    } else {
        Print_Info(1, Hydrom.current_Log_Level, "Entering Phase 4: Publish Data");
        // Button was not the reason
        publish_Data_to_Services();

        updater.set_current_Log_Level(Hydrom.current_Log_Level);
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
void loop() {
    delay(10000);
}

/**
 * @brief GPIO interrupt service routine fired on every change of the reset button pin.
 *
 * If a WiFi-reset sequence is not already in progress, sets the LED off and
 * puts the device into deep sleep for the configured interval.
 */
void ResetButton_Pinstate_changed() {
    if(!Reset_Wifi) {
        Print_Info(3, 99, "Resetbutton was pressed, so the Hydrom will sleep");
        Device.SetLEDOFF();
        l_DeepSleep_time = calculateDeepSleepSeconds(DeepSleep.hours, DeepSleep.minutes, DeepSleep.seconds);
        Print_Info(1, Hydrom.current_Log_Level, "Hydrom will sleep for " + String(l_DeepSleep_time) + "s");
        Device.SleepDeep(l_DeepSleep_time);
    }
}

/**
 * @brief Shuts down all active subsystems cleanly before entering deep sleep.
 *
 * Signals the web-server task to terminate, waits for it to finish, then stops
 * BLE, the web server, the sensor manager and cuts power to sensors.
 */
void Gracefull_Shutdown() {
    Print_Info(4, Hydrom.current_Log_Level, "Prepare the gracefull shutdown.");
    // To let the Threads kill themself the Shutdown_declared need to be set
    Shutdown_declared = true;
    // The ESP will wait until the Threads are dead
    while(Task_Webserver_is_active) {
        delay(250);
        Print_Info(5, Hydrom.current_Log_Level, ".");
    }
    if(Bluetooth.Enabled)
        bt.stop();
    web.stop();
    Print_Info(4, Hydrom.current_Log_Level, "Networkconnection closed");
    sensormanager.stop();
    Device.setMPUstate(LOW);
    Device.setDS18B20state(LOW);
    Print_Info(4, Hydrom.current_Log_Level, "gracefull shutdown prepered.");
}
/**
 * @brief Enters indefinite deep sleep if the battery voltage is critically low (≤ 3 V).
 *
 * Reads the battery voltage and calls SleepDeep(DEF_TIME_SLEEP_FOREVER) to protect
 * the battery. The device must be manually power-cycled to recover.
 */
void CheckDeviceEndlessSleep() {
    Print_Info(4, Hydrom.current_Log_Level, "Check If Device need to Sleep endless");
    configSensor.batteryVoltage = sensormanager.Measure_Battery_Voltage();
    if(configSensor.batteryVoltage <= 3 && configSensor.batteryVoltage >= 1) {
        Print_Error("Battery is to LOW V=" + String(configSensor.batteryVoltage));
        Device.SleepDeep(DEF_TIME_SLEEP_FOREVER);
    } else {
        if(configSensor.batteryVoltage <= 1)
            Print_Info(4, Hydrom.current_Log_Level, "Device is in Lab-Mode (No Battery connected)");
        if(configSensor.batteryVoltage >= 3)
            Print_Info(4, Hydrom.current_Log_Level, "Device is charged enough");
    }
}

/**
 * @brief Returns whether a WiFi connection is needed for this wake cycle.
 *
 * WiFi is required if the device woke via the button, or if at least one
 * network-based service (Brewfather, MQTT, InfluxDB, …) is enabled.
 *
 * @return true  WiFi must be established before publishing.
 * @return false No WiFi is needed; the device can skip to sleep.
 */
boolean CheckWifiRequired() {
    if(Hydrom.WokeupReason == BUTTON || Brewblox.Enabled == true || Brewfather.Enabled == true || BierBot.Enabled == true || Craftbeerpi.Enabled == true || Fhem.Enabled == true || Grainfather.Enabled == true || Http.Enabled == true || InfluxDB.Enabled == true || Mqtt.Enabled == true || Prometheus.Enabled == true || Tcontrol.Enabled == true || Tcp.Enabled == true || Telegram.Enabled == true || ThingSpeak.Enabled == true || Ubidots.Enabled == true || GoogleSheets.Enabled == true) {
        Print_Info(2, Hydrom.current_Log_Level, "Wifi is requiered");
        return true;
    } else {
        Print_Info(2, Hydrom.current_Log_Level, "Wifi is not requiered");
        return false;
    }
}

/**
 * @brief Reads the latest sensor values and dispatches them to every enabled service.
 *
 * Calls the appropriate ServiceManager send method for each enabled integration
 * (Brewblox, Brewfather, BierBot, MQTT, InfluxDB, Telegram, …).
 */
void publish_Data_to_Services() {
    l_DeepSleep_time = calculateDeepSleepSeconds(DeepSleep.hours, DeepSleep.minutes, DeepSleep.seconds);
    readSensorsandsavethem(&sensormanager);
    service.update(Hydrom.name, Bluetooth.UUID_ID, configSensor.gravity, configSensor.plato, configSensor.specific_gravity, sensormanager.get_converted_temperature(0), sensormanager.get_converted_temperature(1), sensormanager.get_converted_temperature(2), configSensor.batteryVoltage, configSensor.batteryPercentage, l_DeepSleep_time, WiFi.RSSI(), DEF_CONNTIMEOUT, Hydrom.current_Log_Level);//, MAX_STRING_LENGTH);

    if(Brewblox.Enabled)
        service.sendBrewblox(Brewblox.TargetServer, Brewblox.TargetPort, Brewblox.TopicLevel, DEF_BREWBLOX_USER, DEF_BREWBLOX_PASSWORD);
    if(Brewfather.Enabled)
        service.sendBrewfather(true, DEF_BREWFATHER_SERVER, DEF_BREWFATHER_PORT, Brewfather._url);
    if(BierBot.Enabled) {
        uint32_t new_Deepsleeptime_ms = service.sendBierBot(DEF_BIERBOT_SERVER, BierBot.Token, DEF_BIERBOT_URL, config.getFlashChipId(), Firmwareversion);
        if(new_Deepsleeptime_ms > 1000) {    // If the BierBot requests a new DeepSleep time, then this is set.

            DeepSleep.hours      = new_Deepsleeptime_ms / 3600000;    // 1h = 3600000ms //Here the DeepSleep time in hours is calculated
            new_Deepsleeptime_ms = new_Deepsleeptime_ms % 3600000;    // Here the rest of the calculation is calculated
            DeepSleep.minutes    = new_Deepsleeptime_ms / 60000;      // 1m = 60000ms //Here the DeepSleep time in minutes is calculated
            new_Deepsleeptime_ms = new_Deepsleeptime_ms % 60000;      // Here the rest of the calculation is calculated
            DeepSleep.seconds    = new_Deepsleeptime_ms / 1000;       // 1s = 1000ms //Here the DeepSleep time in seconds is calculated

            Print_Info(1, Hydrom.current_Log_Level, "Das bedeutet " + String(DeepSleep.hours) + "h " + String(DeepSleep.minutes) + "m " + String(DeepSleep.seconds) + "s");
            config.saveFS_Settings();
        }
    }

    if(Craftbeerpi.Enabled)
        service.sendCraftbeerpi(Craftbeerpi.TargetServer, DEF_CRAFTBEERPI_PORT, DEF_CRAFTBEERPI_URL);
    if(Fhem.Enabled)
        service.sendFHEM(Fhem.TargetServer, Fhem.TargetPort);
    if(Http.Enabled)
        service.sendHttp(Http.TargetServer, Http.TargetPort, Http._url);
    if(Grainfather.Enabled)
        service.sendGrainfather(DEF_GRAINFATHER_SERVER, DEF_GRAINFATHER_PORT, Grainfather._url);
    if(InfluxDB.Enabled)
        service.sendInfluxDB(InfluxDB.TargetServer, InfluxDB.TargetPort, InfluxDB.db, InfluxDB.user, InfluxDB.password, InfluxDB.Measurementsname);
    if(Mqtt.Enabled)
        service.sendMQTT(Mqtt.TargetServer, Mqtt.TargetPort, Mqtt.user, Mqtt.password, Mqtt.TopicLevel);
    if(Prometheus.Enabled)
        service.sendPrometheus(Prometheus.TargetServer, Prometheus.TargetPort, Prometheus.job, Prometheus.instance);
    if(Tcontrol.Enabled)
        service.sendTCONTROL(Tcontrol.TargetServer, Tcontrol.TargetPort);
    if(Telegram.Enabled) {
        if(service.sendTelegram(configSensor.temperature_unit, configSensor.tilt_unit, Telegram.Token, Telegram.chatID)) {
            Print_Info(3, Hydrom.current_Log_Level, "Send Message to Telegram Successfull");
        } else {
            Print_Error("Send Message to Telegram failed");
        }
    }
    if(Tcp.Enabled)
        service.sendTCP(Tcp.TargetServer, Tcp.TargetPort);
    if(Ubidots.Enabled)
        service.sendUbidots(configSensor.temperature_unit, configSensor.tilt_unit, Ubidots_Server, 80, Ubidots.Token);
    if(GoogleSheets.Enabled)
        service.sendGoogleSheets(DEF_GOOGLESHEETS_SERVER, DEF_GOOGLESHEETS_PORT, GoogleSheets.Token);

    if(Device.getTestMessage_state()) {
    }
}
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

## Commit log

2026-03-09 Add full Doxygen documentation and project structure
    - Add complete function-level Doxygen comments (@brief, @param, @return)
    to all firmware source files: main.cpp, WebManager, ServiceManager,
    HydromConfiguration, ArduAutoUpdater and all supporting libraries
    - Update @author tags to TjGer22 and standardise @file headers with
    SPDX-License-Identifier: GPL-3.0-or-later across all headers
    - Add firmware/, hardware/, docs/ directories and project root files
    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
    [BOM.xlsx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]
2026-03-09 Add GitHub Actions CI/CD workflows
    - build-firmware.yml — Build firmware + SPIFFS on push/PR to firmware/,
    static analysis via pio check (high severity)
    - release.yml — On version tag: verify tag vs Globals.h, build
    release assets, publish GitHub Release with OTA
    firmware.bin + versioned archives
    - test-installers.yml — Static analysis (ShellCheck, PSScriptAnalyzer) +
    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

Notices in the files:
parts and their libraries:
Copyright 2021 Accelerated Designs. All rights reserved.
